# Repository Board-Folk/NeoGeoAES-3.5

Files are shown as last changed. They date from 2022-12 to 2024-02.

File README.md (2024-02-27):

# NeoGeoAES-3.5 PCB Reproduction

This repository contains a recreation of the main board PCB for NeoGeo AES
consoles. This recreation is based on the available schematics for the
NeoGeo AES and reverse engineering using scanned images of the original
board's copper layers, so should be a reasonably accurate reproduction.

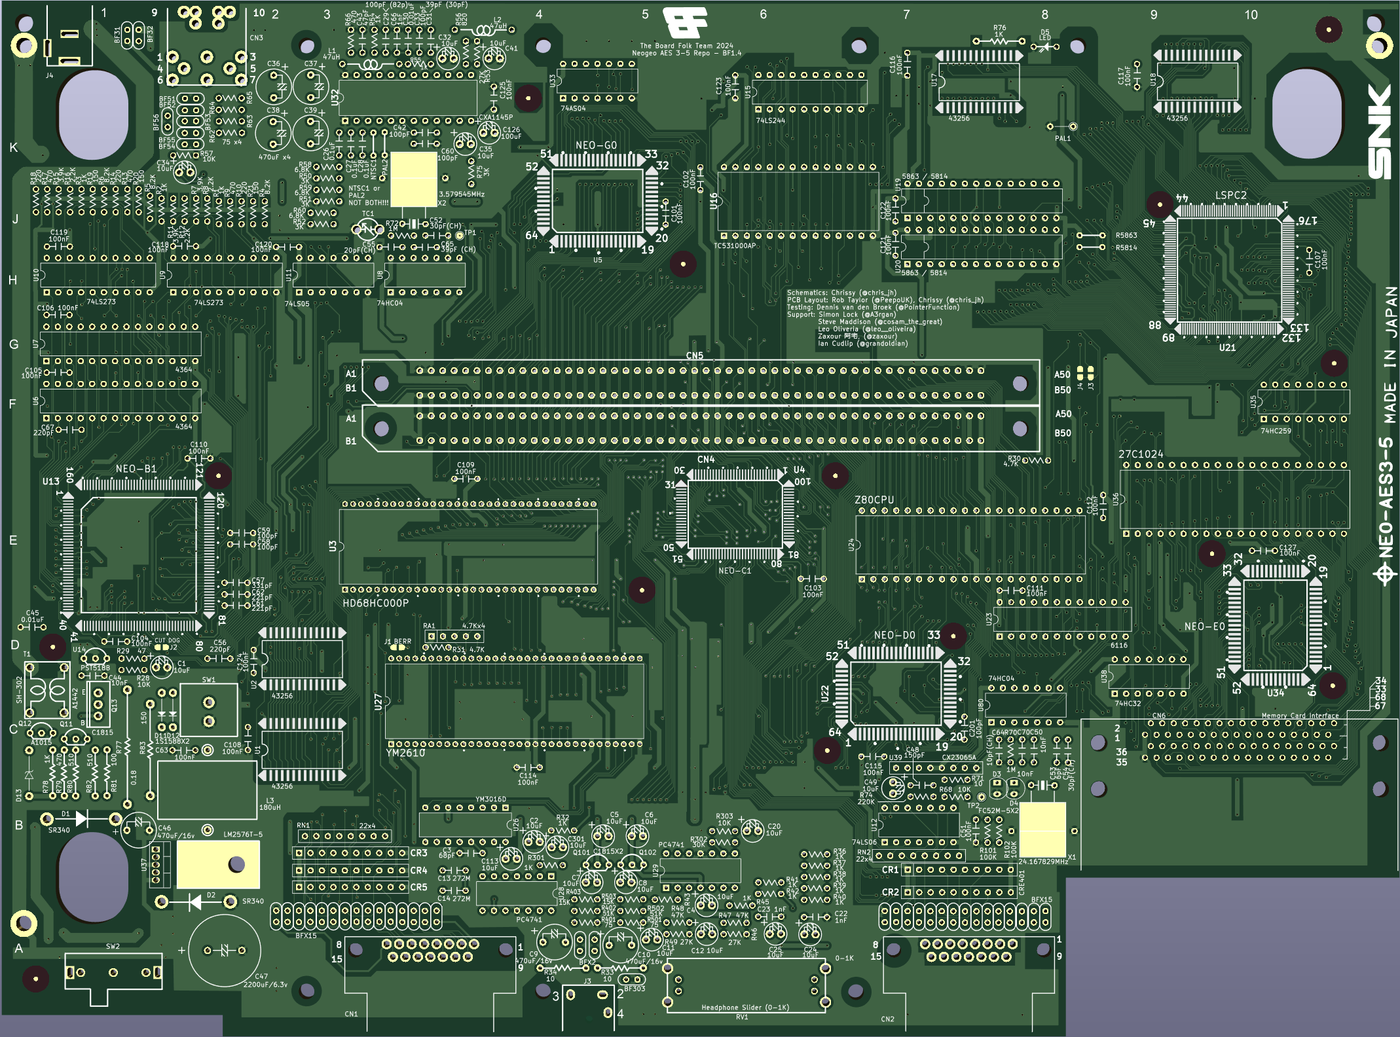
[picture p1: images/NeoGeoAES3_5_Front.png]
PCB


### Revisions

| Revision | Tested | Comments |
|:---:|:---:| --- |
| 1.1 | Working | Prototype |
| 1.2 | Not Tested | Added some missing silk screen |
| 1.3 | Tested | Moved some components on far right by 1mm to be in alignment |
| 1.4 | Tested (not by me) | Tweaks to BOM, updated Silkscreen |

### Future Features
 * Replace power section with something better
 * Add RGB ByPass Mod
 * Add Dual Controller component layput for using standard DB15
 * Do a SMD Version

## PCB Production

Minimum track widths, clearances and via sizes are within the standard
offering of modern PCB fabricators. Development was done using JLCPCB and as
such the Gerber files are provided to their specification.

The design is verified to work as a 2-layer PCB.

I have added it to the PCBWay Shared projects here

<a href="https://www.pcbway.com/project/shareproject/NeoGeo_AES_3_5_reproduction_main_PCB_179da741.html">PCB from PCBWay</a>

I recommend getting ENIG, but HASL will work also.

## Bill of Materials

Most parts are marked on the board and it is expected that these will be reused
from a donor board. It is completely possible that your particular board uses
different (but compatible) parts so it's advisable to take photos before starting.
For a complete BOM, consult the KiCad project's BOM folder, there you will find a CSV file or a PDF.

[**PDF BOM**][BOM]

[**Interactive BOM**][IBOM]

There are some components with mouser parts listed in Kicad BOM, *DO NOT USE THESE*. Need to verify they work.

## 9V or 5V

The NeoGeo AES 3-5 could come configured as either 9V or 5V supply input.

My board is 9V which this repository is based on. Due to this I have marked on the schematics/BOM
which parts are not to populated if using 9V or 5V and by default the 5V circuit is N.F (Not Fitted).

C66 was also not populated.

## Jumper / Links

There are various links around the board.

* __NTSC1 / PAL2 - Only one of these should be populated, it would be very very very bad if both are populated
  as one links to GND and the other to VCC.__\
&nbsp;
* PAL1 and PAL2 - if your board is configured for PAL with the appropriate crystal, these should be populated
* NTSC1 - if your board is configured for NTSC, this should be populated with the appropriate crystal.
* 5863 / 5814 - depending on your memory type, one of these should be populated.
* J1 - BERR Signal into the CPU. Default is off.
* J2 - DOGE Signal into the NEO-B1. Default is off.
* J3 / J4 - This is for the EVEN signal to the LSPC2 chip. J3 is already enabled by default.

## Memory

* 5814 - The shorter of the RAM Chips, make sure to populate into socket to the far right and populate the correct
  jumper.
* 5863 - The longer of the RAM Chips, uses the whole socket. Populate the correct jumper.

## Thanks

  * Rob Taylor ([@PeepoUK](https://github.com/PeepoUK)) for doing most of
    the PCB layout.\
&nbsp;
  * Simon "Aergan" Lock ([@Aergan](https://github.com/Aergan)),\
    Cosam (@cosam_the_great),\
    Dennis (@PointerFunction),\
    Leo Oliveria (@leo__oliveira),\
    Zaxour 阿宅, (@zaxour),\
    Ian Cudlip (@grandoldian)\
    for their insights, support and testing of the prototype boards.\
&nbsp;
  * The rest of the Board Folk Team for their support and general
    coolness.\
&nbsp;
  * The [NeoGeo Development Wiki](https://wiki.neogeodev.org/) for making
    the original NeoGeo-2 Schematics available, and the people who maintain
    this site.\
&nbsp;

## Legal

As the product of this project is a replica of a proprietary product, the
the author makes no claim of copyright to the schematics nor PCB layouts and
releases these into the public domain, solely for the purposes of study and
historical preservation.

You are free to produce PCBs based on this project's designs at your own risk
and without limitation, for your own use or for sale and/or repair at a
reasonable price. Attribution is appreciated. The authors are not obliged to
provide support of any kind.

Under no circumstances will the authors be held responsible or liable in any
way for losses, damages or costs resulting from the use of the information
and/or resources of this project.

The resources are provided "as-is" without warranty of any kind, either
expressed or implied, including, but not limited to, the implied warranties
of merchantability and fitness for a particular purpose.

[IBOM]: http://htmlpreview.github.io/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

[BOM]: https://raw.githubusercontent.com/Board-Folk/NeoGeoAES-3.5/main/bom/NeoGeoAES3_5-BOM.pdf

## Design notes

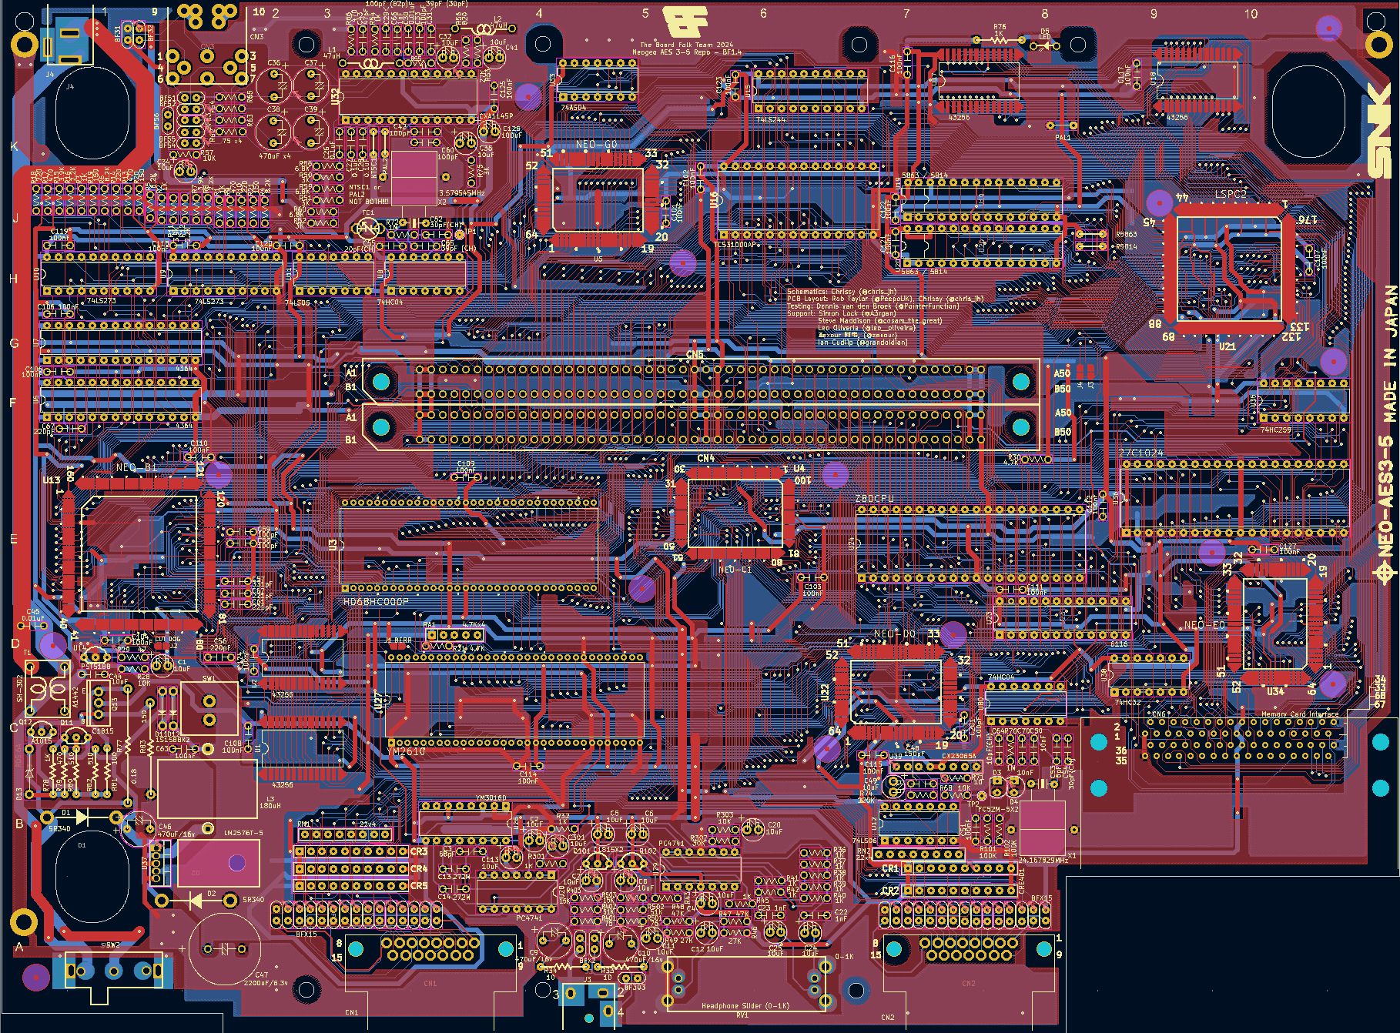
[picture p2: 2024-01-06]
images/NeoGeoAES3_5_PCB.png

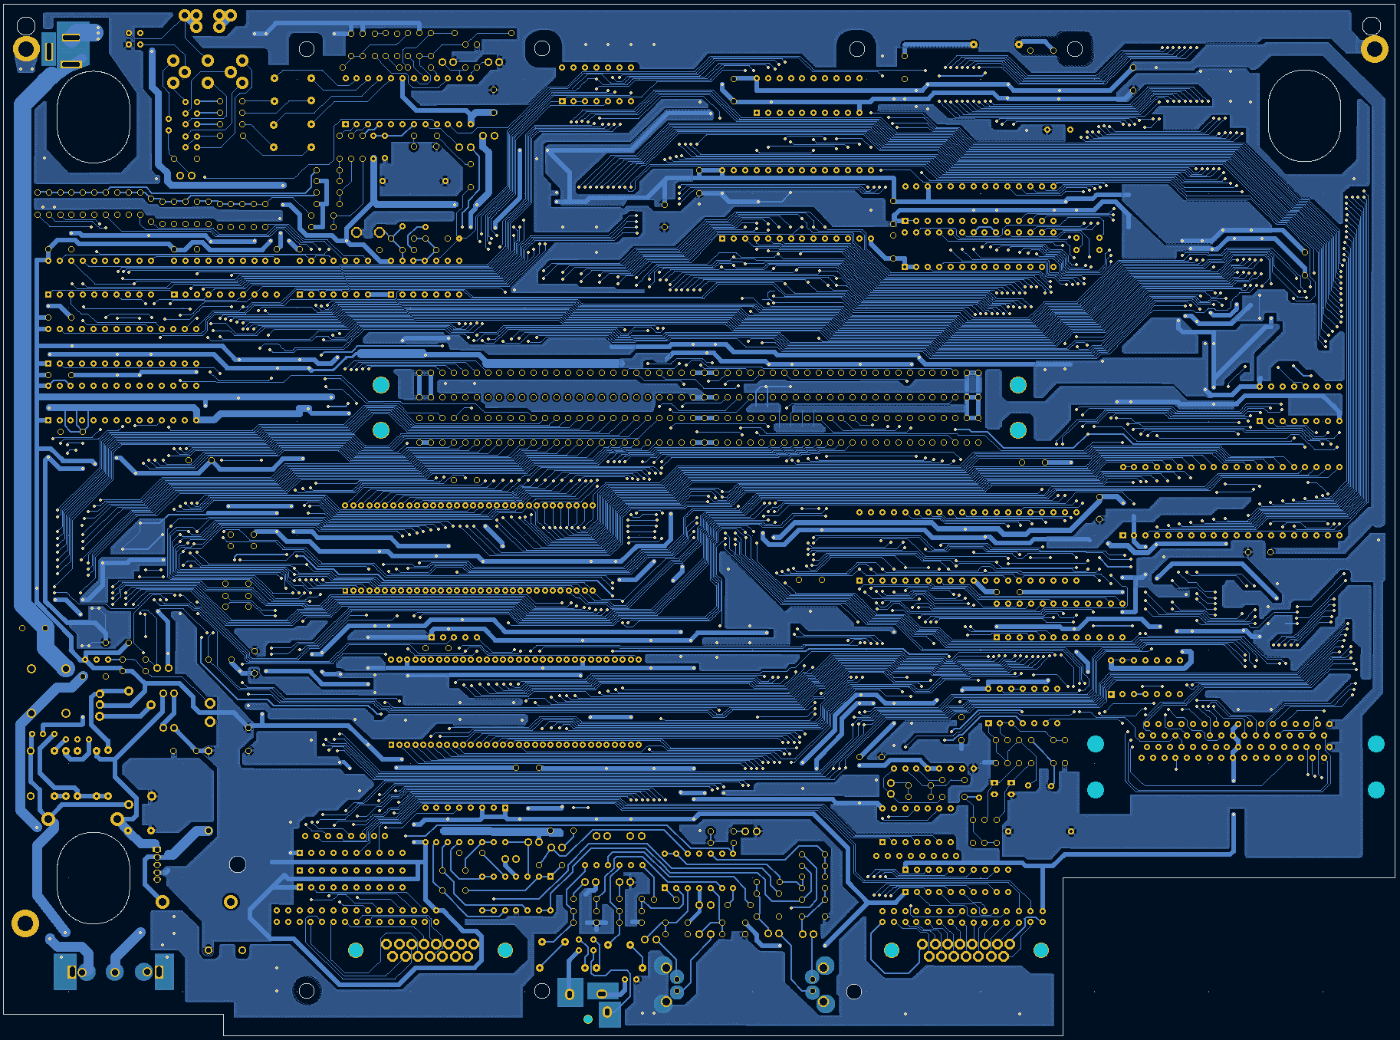
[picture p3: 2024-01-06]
images/NeoGeoAES3_5_PCB_Back.png

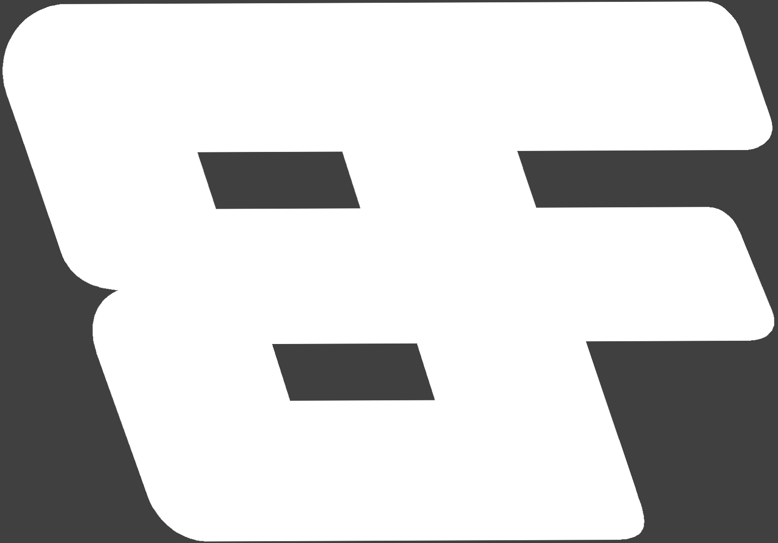
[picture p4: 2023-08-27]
images/BF.png

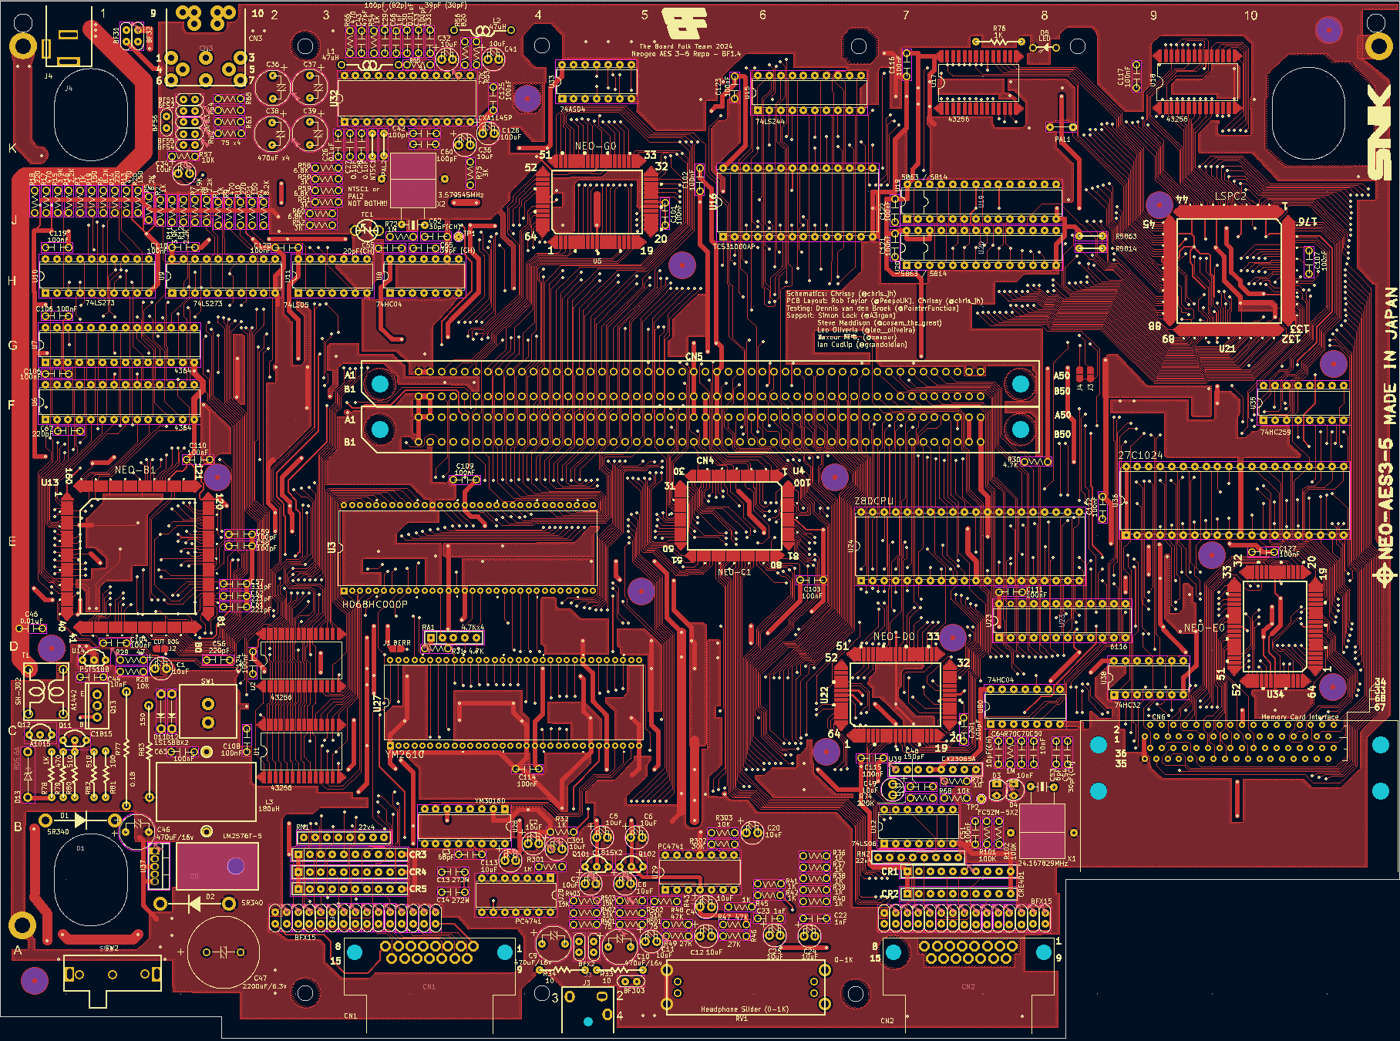
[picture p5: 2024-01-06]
images/NeoGeoAES3_5_PCB_Front.png

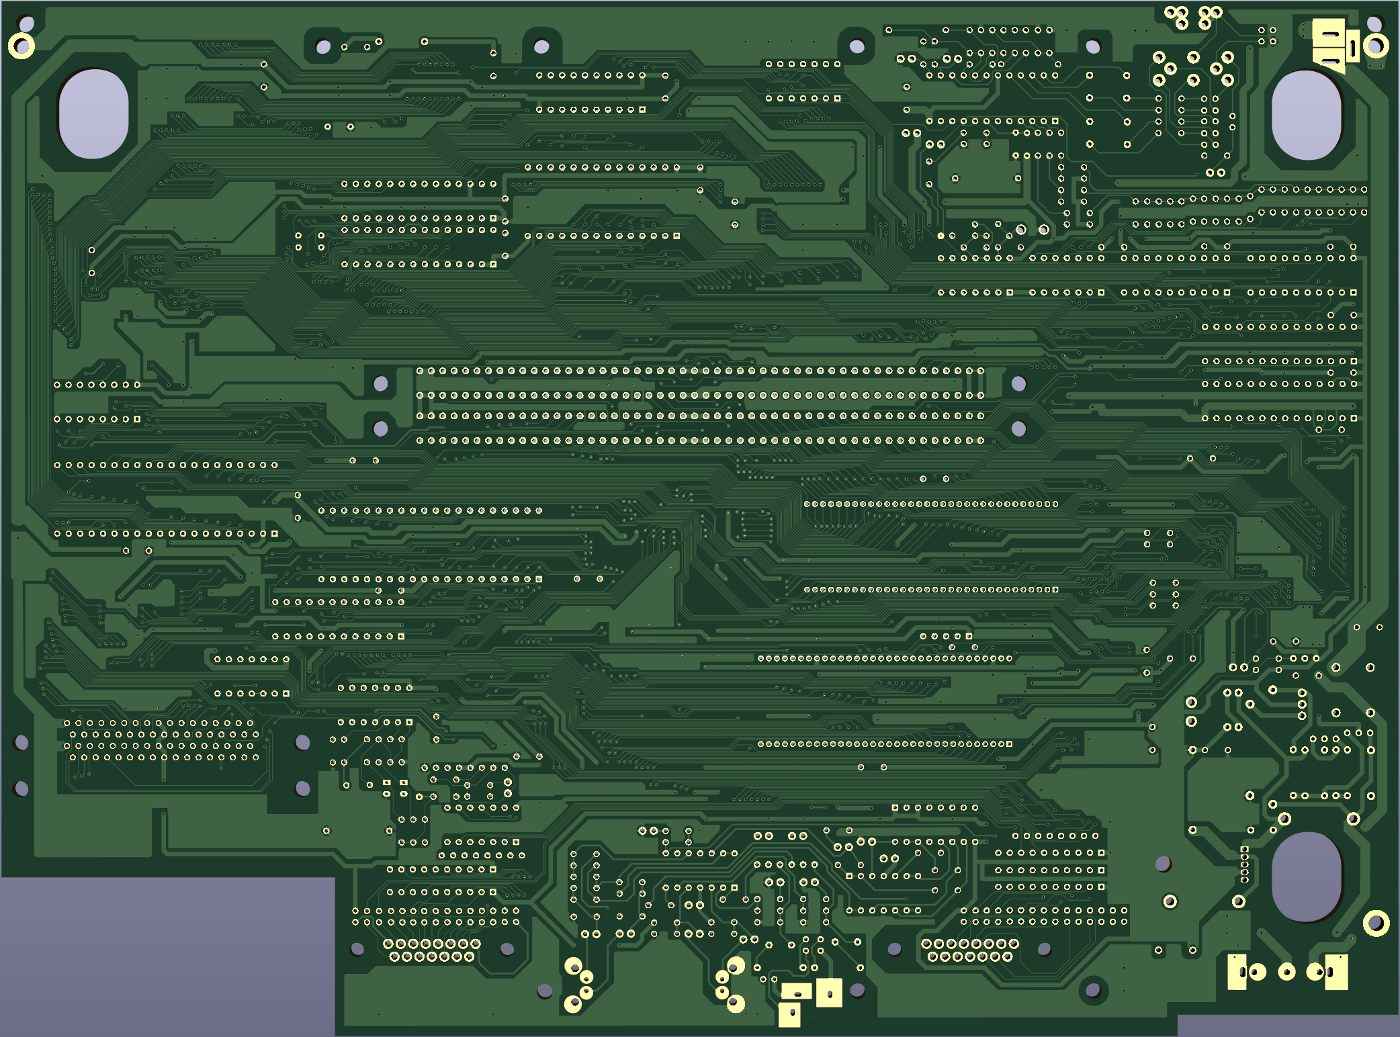
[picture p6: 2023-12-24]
images/NeoGeoAES3_5_Back.png

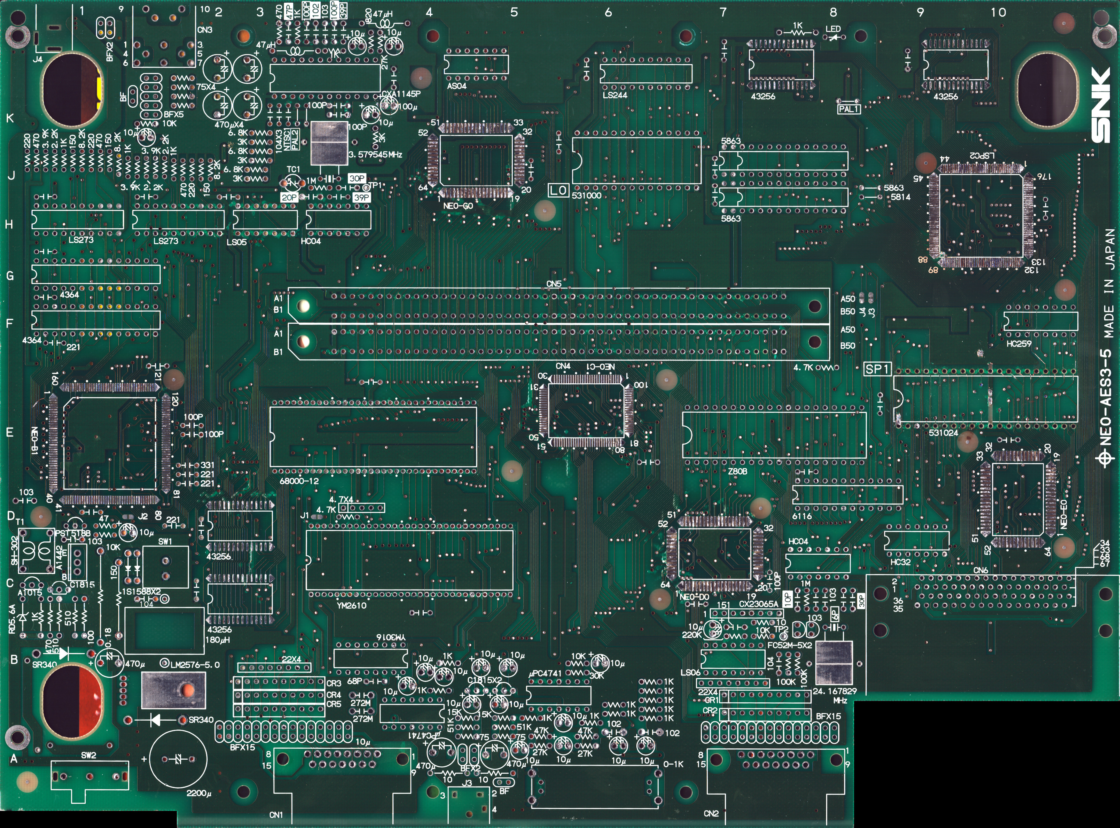
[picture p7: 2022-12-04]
images/neogeo_aes-3-5-front-300dpi_90p.jpg

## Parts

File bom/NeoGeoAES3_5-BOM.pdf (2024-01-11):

### NeoGeoAES3_5-BOM

Qty | Reference | Value | Mouser | Alternative | Comment
41 | BF1-BF32, BF51-BF56, BF301-BF303 | ZBF253D | 80-B-06-R-25
19 | C1, C2, C4-C8, C11, C12, C20, C24, C25, C32, C34, C35, C41, C49, C113, C301 | 10uF | 667-ECA-1CM100I
1 | C3 | 68pF | 810-FG28C0G2A680JNT6
7 | C9, C10, C36-C39, C46 | 470uF/16v | 647-UVR1C471MPD1TA
2 | C13, C14 | 272M | 80-MMK5272K63J01TA18
3 | C22, C23, C66 | 1nF | 810-FG28C0G1H102JNT6 | | -- mixed values --
3 | C26-C28 | 0.1uF | 810-FG26C0G1H104JNT0
1 | C29 | 100pF (82p) | 810-FG28C0G1H101JNT6
2 | C30, C45 | 0.01uF | 810-FG28C0G1H103JNT0
1 | C31 | 39pF (30pF) | 810-FG28C0G1H390JNT6
6 | C33, C42, C58-C60, C201 | 100pF | 810-FG28C0G1H101JNT6
1 | C43 | 47pF | 810-FG28C0G1H470JNT6
3 | C44, C50, C70 | 10nF | 810-FG28C0G1H103JNT0
1 | C47 | 2200uF/6.3v | 667-EEU-FC0J222S
1 | C48 | 150pF | 810-FG28C0G1H151JNT6
27 | C51, C63, C101-C112, C114-C125, C127 | 100nF | 810-FG26C0G1H104JNT0
2 | C52, C54 | 30pF(CH) | 80-C322C300K3G5TA
1 | C53 | 6pF | 810-FG28C0G1H060DNT6
1 | C55 | 20pF(CH) | 80-C317C200J5G
2 | C56, C67 | 220pF | 810-FG28C0G1H221JNT0
1 | C57 | 331pF | 810-FG28C0G1H331JNT6
2 | C61, C62 | 221pF | 810-FG28C0G1H221JNT0
1 | C64 | 10pF(CH) | 810-FG28C0G1H100DNT6
1 | C65 | 39pF (CH) | 810-FG28C0G1H390JNT6
1 | C126 | 100uF | 667-ECA-1CM101I
1 | CN1 | CTRL1 | | | Use Original
1 | CN2 | CTRL2 | | | Use Original
1 | CN3 | DIN-8 | | | Use Original
2 | CN4, CN5 | AXC90020 | 587-395-100-524-204
1 | CN6 | Memory Card Interface | | | Use Original
5 | CR1-CR5 | CRE401 | | https://github.com/mourix/CRE401
2 | D1, D2 | SR340 | 583-SR340-T | | Not Fitted when 5v Circuit
2 | D3, D4 | FC52M-5 | | LV2209 | Use Original
1 | D5 | LED | 604-WP7113ID5V
2 | D11, D12 | 1S1588 | | | Not Fitted when 9v Circuit
1 | D13 | RD5.6A | | | Not Fitted when 9v Circuit
1 | J3 | SMK S-G8043
1 | J4 | POWER JACK | 490-PJ-102B
1 | JP3 | J3
1 | JP4 | J4
1 | L1 | 47uH
1 | L2 | 47uH
1 | L3 | 180uH | | | Not Fitted when 5v Circuit, Use Original
1 | Q11 | C1815 | | | Not Fitted when 9v Circuit
1 | Q12 | A1015 | | | Not Fitted when 9v Circuit
1 | Q13 | A1442 | | | Not Fitted when 9v Circuit
2 | Q101, Q102 | 2SC1815 | 610-2SC1815
16 | R1-R3, R32, R36-R43, R45, R54, R55, R301 | 1K | 594-5063JD1K000FT
3 | R4-R6 | 8.2K | 594-5063JD8K200FT
3 | R7, R11, R15 | 3.9K | 594-5063JD3K900F
3 | R8, R12, R16 | 2.2K | 594-5063JD2K200FT
4 | R9, R13, R17, R66 | 470 | 594-5063JD470R0FT
3 | R10, R14, R18 | 220 | 594-5063JD220R0F
3 | R19-R21 | 150 | 594-5063JD150R0FT
4 | R28, R57, R68, R303 | 10K | 594-5063JD10K1%TR
1 | R29 | 47 | 594-5063JD47R00F
2 | R30, R31 | 4.7K | 594-5063JD4K700F5
2 | R33, R34 | 10 | 594-5063JD10R00FT
3 | R46, R49, R53 | 27K | 594-5063JD27K00FT
2 | R47, R48 | 47K | 594-5063JD47K00FT
4 | R50-R52, R75 | 3K | 594-5063JD3K000F
1 | R56 | 820 | 594-5063JD820R0FT
3 | R58-R60 | 6.8K | 594-5063JD6K810FT
6 | R62-R65, R401, R501 | 75 | 594-5063JD75R00FT
2 | R70, R72 | 1M | 594-5063JD1M000FT
1 | R71 | 10 | 594-5063JD10R00FT
1 | R74 | 220K | 594-5063JD220K0F
2 | R76, R78 | 1K | 594-5063JD1K000FT | | -- mixed values --
1 | R77 | 0.18 | | | Not Fitted when 9v Circuit
2 | R79, R82 | 510 | | | Not Fitted when 9v Circuit
1 | R80 | 470 | | | Not Fitted when 9v Circuit
1 | R81 | 100 | | | Not Fitted when 9v Circuit
1 | R83 | 150 | | | Not Fitted when 9v Circuit
2 | R101, R102 | 100K | 594-5063JD100K0FT

1

1 | R302 | 30K | 594-5063JD30K00F
2 | R402, R502 | 51K | 594-5063JD51K00F
2 | R403, R503 | 15K | 594-5063JD15K00F5
1 | RA1 | 4.7Kx4 | 652-4605X-1LF-4.7K
2 | RN1, RN2 | 22x4 | 652-4608X-2LF-22
1 | RV1 | Headphone Slider (0-1K) | | Alps Alpine RS20H12AC002 | Use Original
1 | SW1 | RESET SWITCH | | https://a.aliexpress.com/_EwBCIut | Use Original
1 | SW2 | POWER SWITCH | | | Use Original
1 | T1 | SH-302 | 80-SH-302
1 | TC1 | 0-50p | | Mouser 594-2222-808-23279 ?? 4pF-27pF or Digikey 2447-GKG50015-ND ? Use Original
4 | U1, U2, U17, U18 | 43256 | 870-62C256AL-25ULI | JEDEC 62256 (32k x 8) SRAM | Use Original
1 | U3 | HD68HC000P | | | Use Original
1 | U4 | NEO-C1 | | | Use Original
1 | U5 | NEO-G0 | | | Use Original
2 | U6, U7 | 4364 | 913-AS7C164A-15PCN | JEDEC 6264 (8k x 8) SRAM | Use Original
2 | U8, U80 | 74HC04 | 595-SN74HC04N
2 | U9, U10 | 74LS273 | 595-SN74LS273N
1 | U11 | 74LS05 | 595-SN74LS05N
1 | U12 | 74LS06 | 595-SN74LS06N
1 | U13 | NEO-B1 | | | Use Original
1 | U14 | PST518B | 579-MCP120-450GI/TO | | Use Original
1 | U15 | 74LS244 | 595-SN74LS244N
1 | U16 | TC531000AP | | | Use Original
2 | U19, U20 | 5863 / 5814 | | JEDEC 6116 (2k x 8) SRAM 35ns | Use Original
1 | U21 | LSPC2 | | | Use Original
1 | U22 | NEO-D0 | | | Use Original
1 | U23 | 6116 | | JEDEC 6116 (2k x 8) SRAM 35ns | Use Original
1 | U24 | Z80CPU | | | Use Original
1 | U26 | YM3016D | | | Use Original
1 | U27 | YM2610 | | | Use Original
2 | U28, U29 | PC4741 | 968-UPC4741G2-E1-A | | Use Original
1 | U32 | CXA1145P | | CXA1645 or CXA2075 needs adapterUse Original
1 | U33 | 74AS04 | 595-SN74AS04N
1 | U34 | NEO-E0 | | | Use Original
1 | U35 | 74HC259 | 595-SN74HC259N
1 | U36 | 27C1024 | | | Use Original
1 | U37 | LM2576T-5 | 926-LM2576T-5.0/NOPB | https://www.aliexpress.com/item/1005004285746293.html Not Fitted when 5v Circuit
1 | U38 | 74HC32 | 595-SN74HC32N
1 | U39 | CX23065A | Use Original or could be removed along with associated resistors and caps, D3 D4 removed and bridged and 24Mhz used
1 | X1 | 24.167829MHz | Use Original or 24 Mhz and CX23065A removed
1 | X2 | 3.579545MHz | 815-AB-3.579545-B2

2

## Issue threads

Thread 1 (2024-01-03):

Memory Card Slot Mouser Part does not fit

chris-jh, 2024-01-03:
The Memory Card PCMCIA selected in Mouser Part does not fit. Don't use.

jwestfall69, 2024-01-07:
Hi,

The NeoGeo uses a non-standard PCMCIA connector for the pins connecting to the PCB.  Pin 1 starts on the 2nd row while all PCMCIA connectors out there have pin 1 on the first row.  I've never been able to find a replacement other then sourcing from parts boards. You should consider just adjusting the PCB layout to work with a normal PCMCIA connector.

chris-jh, 2024-01-07:
Aye, i have removed the part from my bom and reference, which is now version BF1.4

I am planing on doing a remaster of the board with more modern parts in places.
PSU,
Video,
Memory Slot,
Headphone Socket and Slider,
Switch,
SRAM

Maybe even SMD for resistors and caps.

philjay78, 2024-01-12:
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
Hi, i'm Massimo. I think a similar thing could be a good solution for fix the problem for me that i have a 1.3 board.

philjay78, 2024-01-12:
[adapter.zip](https://github.com/Board-Folk/NeoGeoAES-3.5/files/13918917/adapter.zip)
could it work like this? It's my first attempt with kicad 👍

philjay78, 2024-01-13:
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
With my very very poor knowledge of kicad, i've made this adapter. I've tried the measure and maybe you have to cut the guide of the new pcmcia adapter (5535653-1), obviously you need to solder the adapter and cut the pins straight at max you can do.

chris-jh, 2024-01-14:
Looks good ? going for thin pcb ?

spokito95, 2025-01-26:
Hi, Having bent the connector to read the memory card of the neo geo, I looked for a substitute, but I found nothing interesting.
But this topic gave me the idea of making this small adapter on the surface, because the pins to be soldered through the pcb could be troublesome. So that's the idea I'm sharing with you.

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

spokito95, 2025-01-26:
Hello all,

I finally finished the pcb, taking care to check the measurements for optimum fit.
As philjay78 mentioned on his pcb, which I based on (thanks to him), I'll also have to cut off the parts of the PCMCIA adapter that stick out 12mm to keep the right dimensions.
I have made the Gerber file available. If anyone can find a cheap 5535651-6 connector, I'd be interested as it's a bit expensive.
I ordered 5 copies of pcb on JLCPCB and pre-ordered the connector: 5535651-6 because it was out of stock on LCSC electronics. I'll wait and see.
I will keep you informed as soon as I receive them.

[Gerber_adapter_PCMCIA_Neo_Geo_AES_2025-01-26.zip](https://github.com/user-attachments/files/18551862/Gerber_adapter_PCMCIA_Neo_Geo_AES_2025-01-26.zip)

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

chris-jh, 2025-01-28:
Looking good, still not got around to making a remix board, one day 😂

spokito95, 2025-01-30:
Hello Chris-jh,

First of all, congratulations on the reproduction work, it's truly amazing! I've finalized two Neo Geo AES 3.5 reproduction PCBs, and both work perfectly! However, I had to install components D3, D4, and U39 as well as the original quartz, in addition to the 100k resistors and the 100nF capacitor, because the 24.000 MHz quartz crystal, like the one in the photo, did not work. Which components should I remove exactly to avoid using D3, D4, and U39 as well as the original quartz? What is the exact procedure to make it work?

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

chris-jh, 2025-02-01:
Trying to remember, i found this photo on my phone. But basically it is the MVS circuit. I don't think i used 33pf, i think it was either 30pF or 20pF at C70.

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

spokito95, 2025-02-01:
Capacitor C50 10nf must be replaced also by 30pf or not ? Because I have a problem on screen with glitch or unsynchronised, I don't know.

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

spokito95, 2025-02-01:
It's ok now I had to replace the C50 (10 nF) and C70 (10 nF) capacitors with two 20pF capacitors, thank you very much for your help :)

chris-jh, 2025-02-01:
Yes sorry, C50 and C70. i got my board out and i have 20pF here.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

chris-jh, 2025-02-01:
These are the components i have fitted in that area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

spokito95, 2025-02-01:
No problem it's cool :), I'll summarise what needs to be done in pdf below.

[Remove and reolace components.pdf](https://github.com/user-attachments/files/18630258/Remove.and.reolace.components.pdf)

spokito95, 2025-03-15:
Hi everyone,

Just a quick update on my Neo Geo AES motherboard reproduction project: my latest board is finally finished and fully functional! Super happy with how it turned out! 🎉

I especially want to give a huge thanks to Illusionrip, who spontaneously and generously offered to send me a 68000 to help me out. Without him, I wouldn’t have been able to finish this board so quickly, so a massive thank you for your precious help! 🙏 :amen:

Right after that, I also assembled my little PCMCIA adapter PCB for the memory card reader, and good news — it works perfectly.
To connect the two PCBs, I chose to use tulip pin headers, and honestly, I don’t regret it at all.

They make soldering much easier (solder flows nicely between the contacts),
And most importantly, they allow for easy continuity testing if you ever have any doubts or issues — super handy to make sure everything is good before finalizing the build.
Just a quick note for anyone thinking about doing the same: the PCMCIA adapter PCB must be properly secured with two screws and nuts (see pictures), to make sure everything stays firmly in place and to avoid putting stress on the solder joints, which could eventually crack or break. This is really important for long-term reliability.

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

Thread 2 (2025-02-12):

Latest board (1.4) does not pass JLCPCB capabilities

joncco, 2025-02-12:
I sent the latest gerber (1.4) to JLCPCB for manufacturing.  It came back with:
the mininum trace spacing in your file are smaller than our mininum requirement of 0.1mm for 2 layer PCB ,please check and modify .

After opening the files in kicad, I found a few traces that have spacing of 0.081. These are around the cart slot, plus a few traces around the memory card area.

I have downloaded and reworked it a bit to allow it to pass DRC using kicad 8.x.  I can submit the changes I made, but not really sure how to proceed.

DoctorDan1986, 2025-04-03:
I, too, was unable to send this through JLCPCB.  Had to have mine done at PCBWAY for about 4x the cost.

bsulyan, 2025-05-05:
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

Same thing today

DoctorDan1986, 2025-05-05:
It seems to change - I've had it pass and I've had it fail a few times.

@bsulyan - I have several free boards.  If you are okay with black soldermask and ENIG, I'll happily sell you one for a reasonable price.

bsulyan, 2025-05-06:
> It seems to change - I've had it pass and I've had it fail a few times.
>
> [@bsulyan](https://github.com/bsulyan) - I have several free boards. If you are okay with black soldermask and ENIG, I'll happily sell you one for a reasonable price.

Thanks for the offer, but I have several NeoGeos that need a new PCB, I would like to take 5 at once. I'll wait for a response from
@joncco

DoctorDan1986, 2025-05-06:
Oh wow.  The funny thing is, I ordered 5 and got 7.  I've used one, and added the video RAM to another, so I actually do have 5 boards.  The offer is open should you care to take it, and no offense taken should you not.

joncco, 2025-05-06:
Sorry for the late reply.  I will look for my files and do a pull request.  Should happen in the next 2-3 days.

bsulyan, 2025-05-06:
> Oh wow. The funny thing is, I ordered 5 and got 7. I've used one, and added the video RAM to another, so I actually do have 5 boards available. The offer is open should you care to take it, and no offense taken should you not.

Can you email me at bastien.sulyan at gmail.com ?

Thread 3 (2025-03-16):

Power circuit missing details for A1015 and C1815

DoctorDan1986, 2025-03-16:
The interactive BOM does not even allow these components to be selected; are the two items near the A1142 left unpopulated?  Are they reused from the original?  Two C1815s are used near the headphone jack; why are these excluded from the build list?

chris-jh, 2025-03-16:
As the readme section on "9V or 5V" tells you this board build is based on the 9v version.

You need to look at the schematics, the interactive bom is used as a component location guide only and anything that is not selectable is N.F (Not Fitted) and will not be used on the iBom. look at the PDF or CSV file.

I don't understand what you mean about the two C1815s ? they are Q101 and Q102 they are not excluded from the build list.

chris-jh, 2025-03-17:
As i said this is based on the 9v version. If you want the 5v iBom, you will have to adjust the KiCad yourself and produce it.

Closed 2025-03-16.

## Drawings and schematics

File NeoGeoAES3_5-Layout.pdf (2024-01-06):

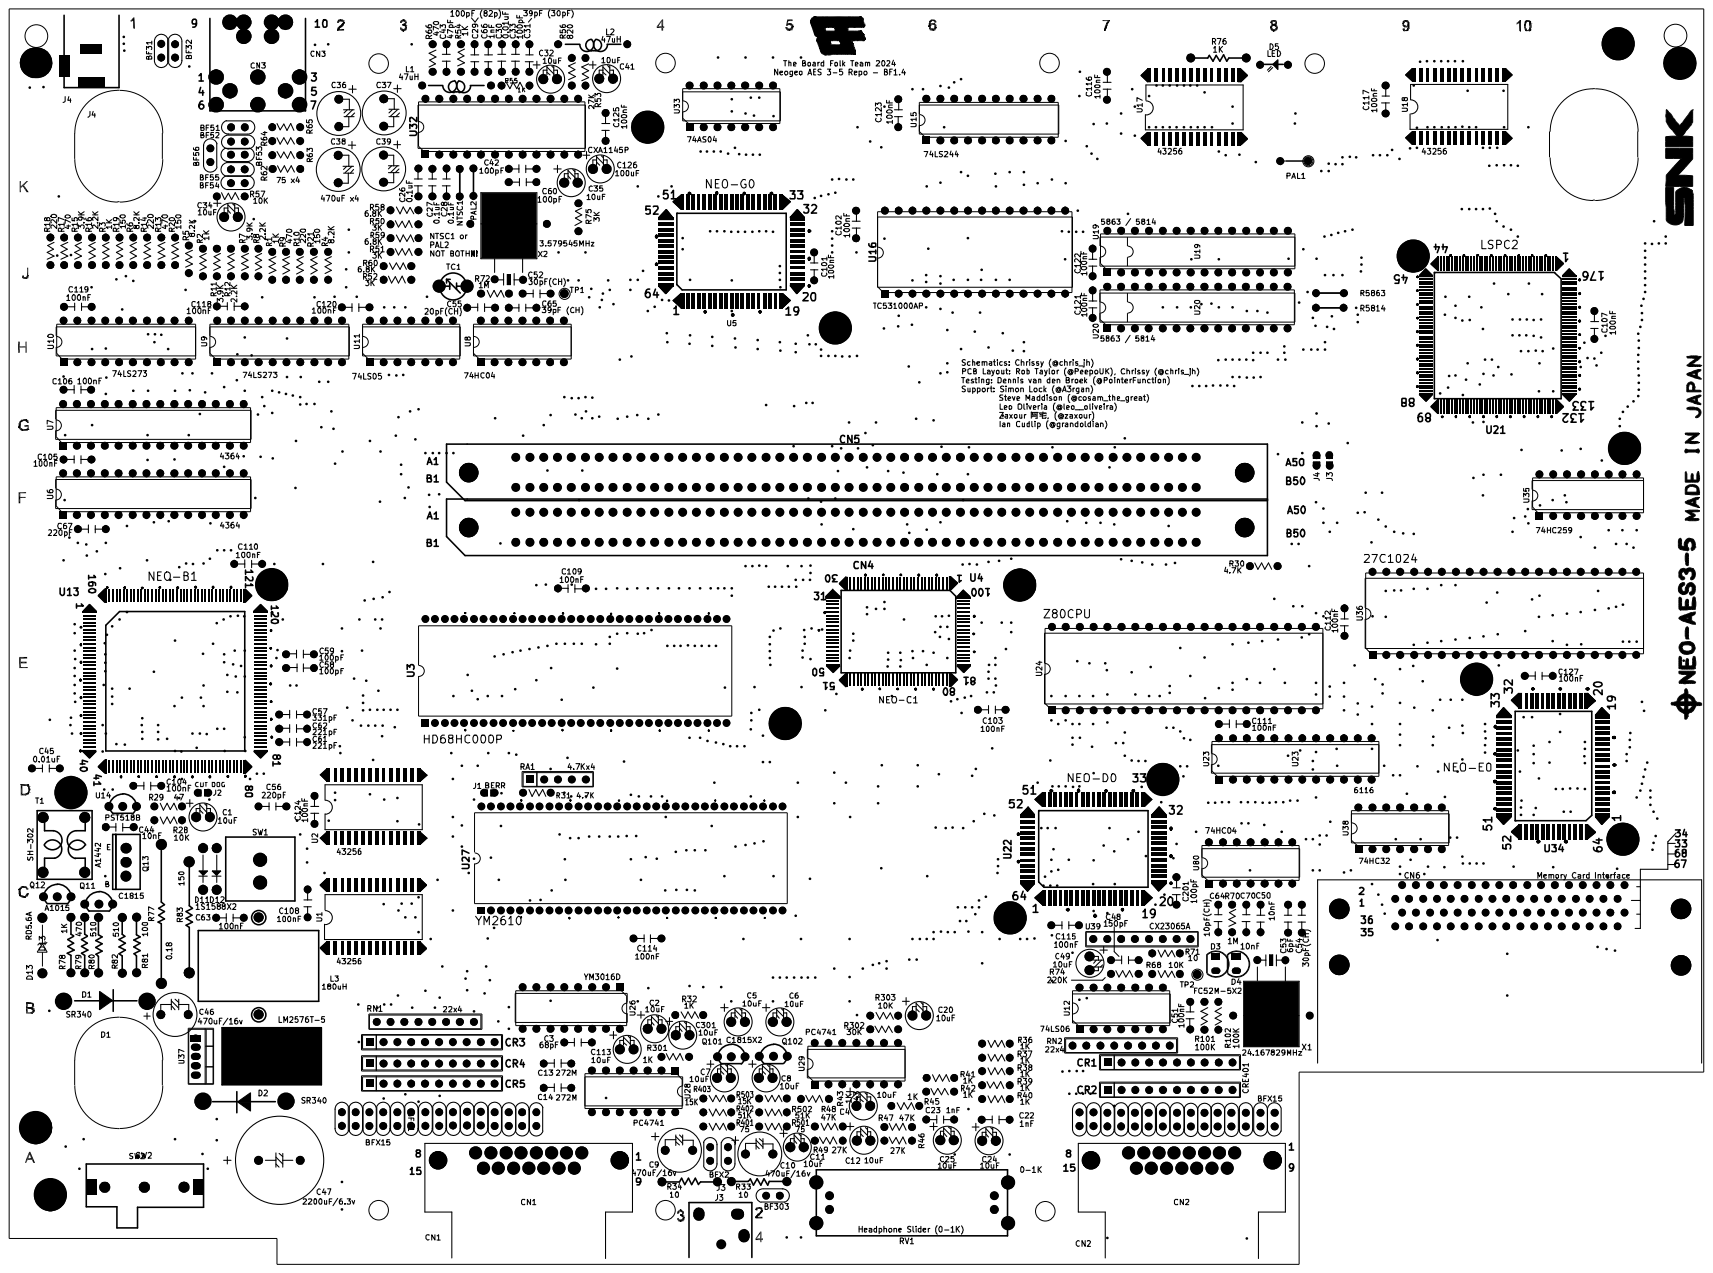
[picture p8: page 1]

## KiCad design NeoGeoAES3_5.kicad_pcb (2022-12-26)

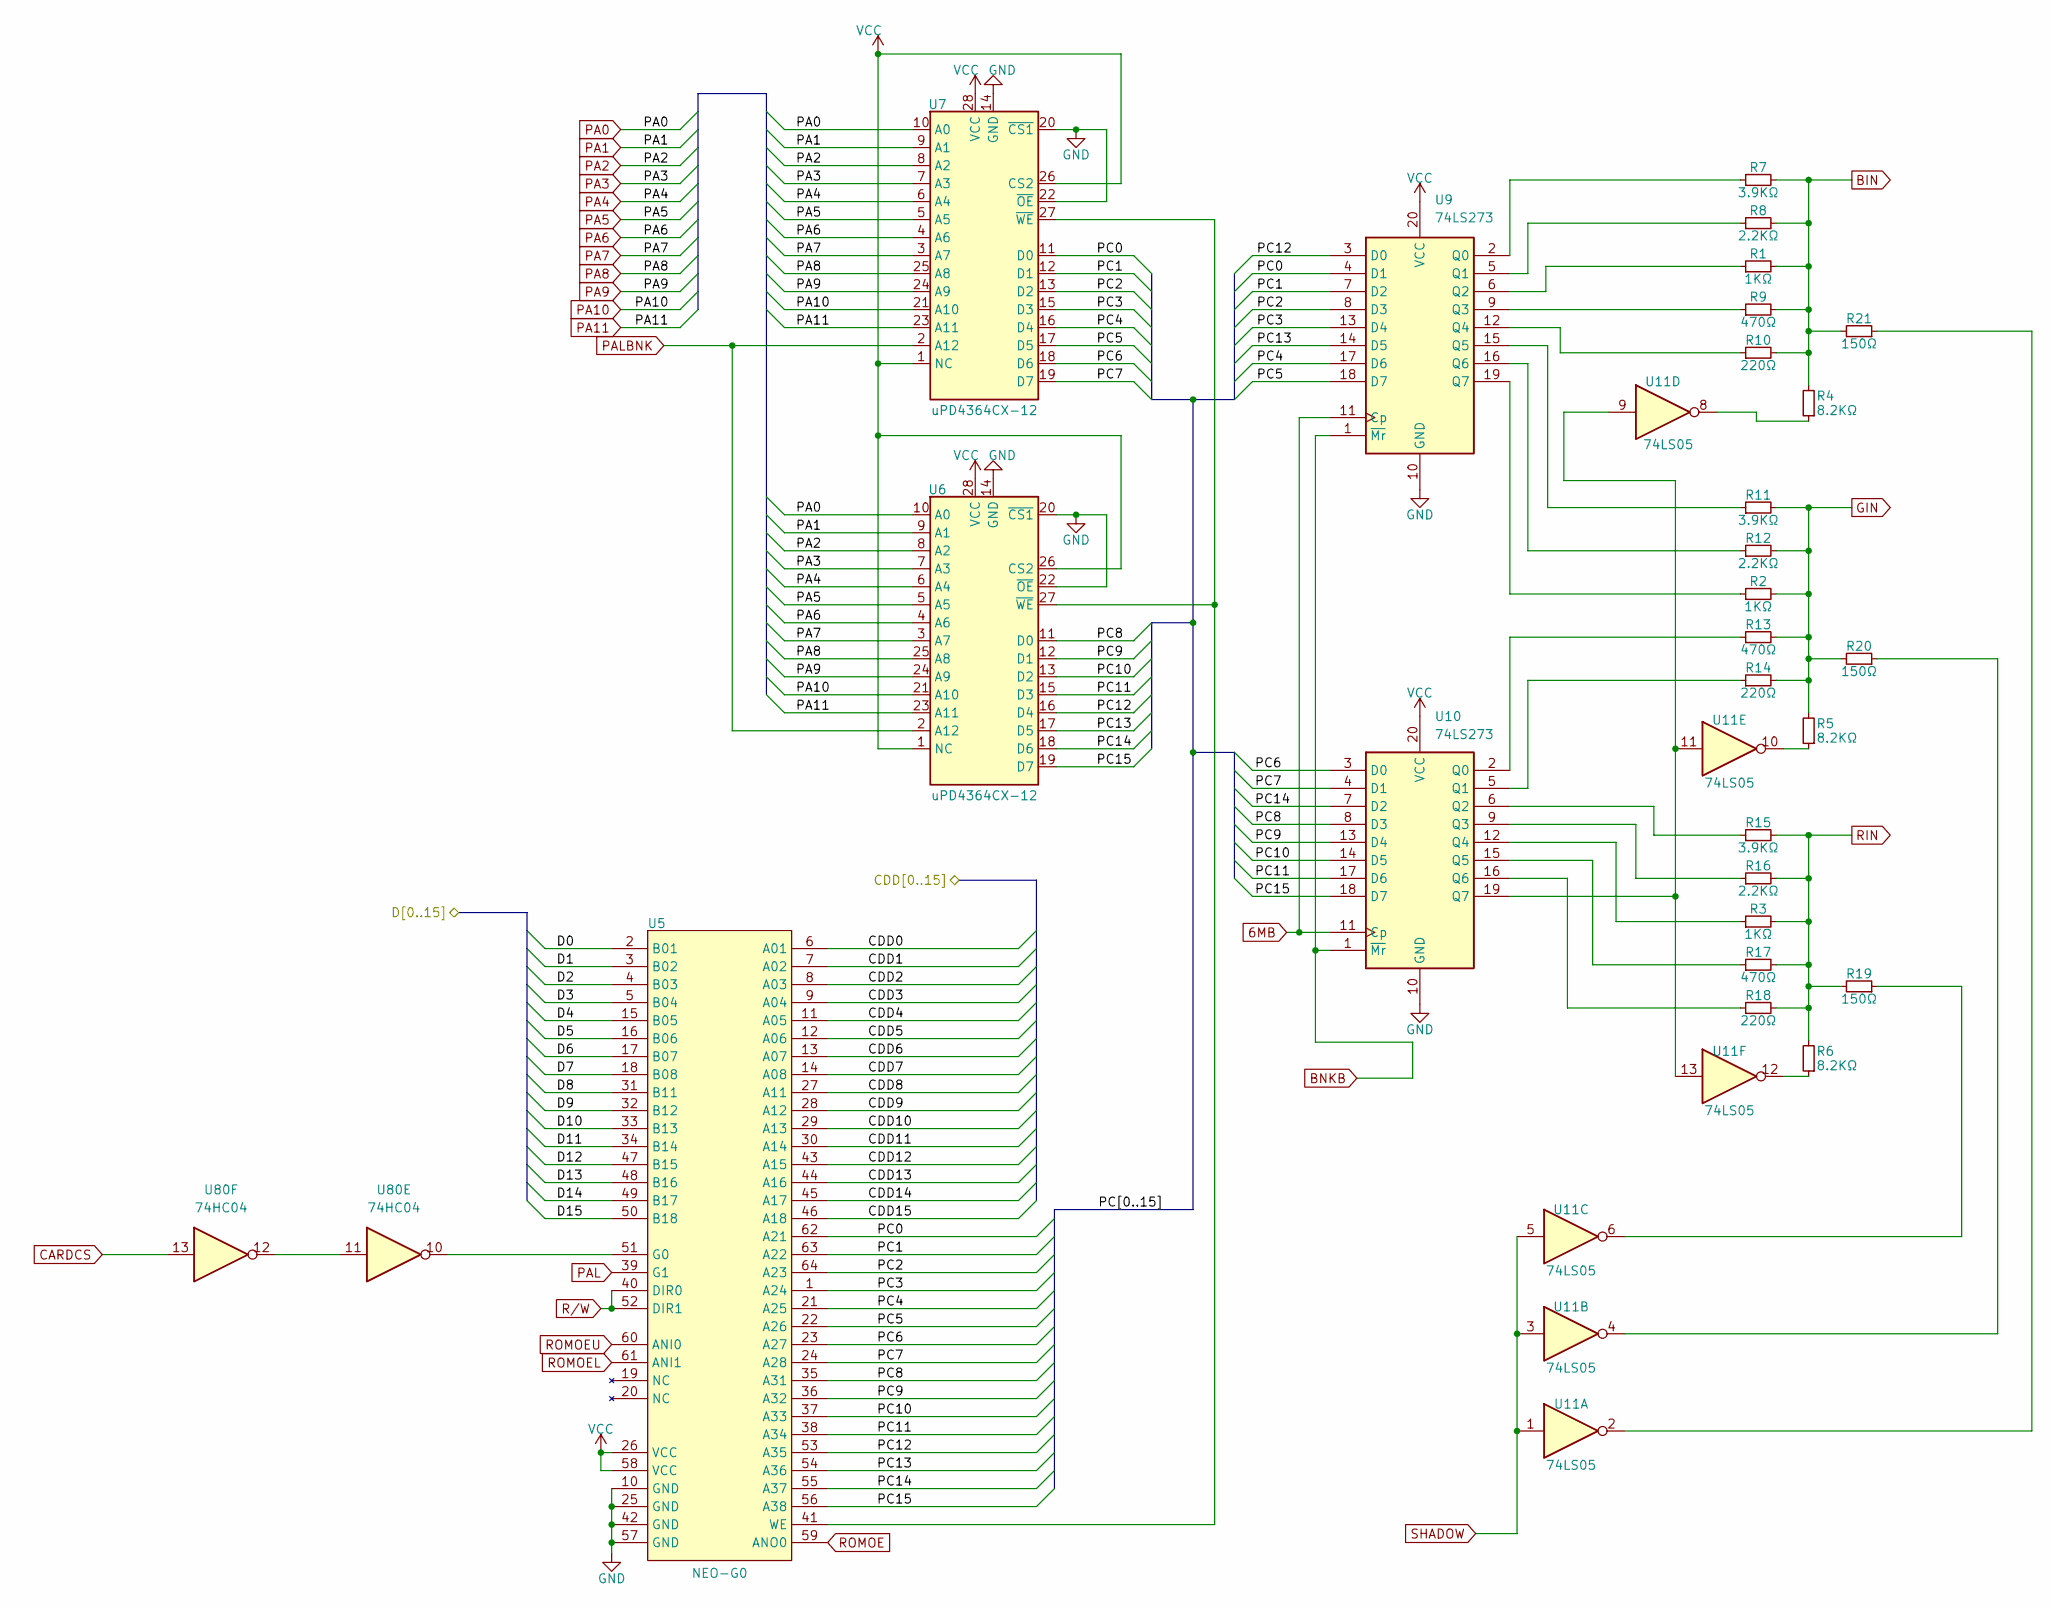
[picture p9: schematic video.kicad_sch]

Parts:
R1, R2, R3: 1KΩ; Resistor1-5mm
R4, R5, R6: 8.2KΩ; Resistor1-5mm
R7, R11, R15: 3.9KΩ; Resistor1-5mm
R8, R12, R16: 2.2KΩ; Resistor1-5mm
R9, R13, R17: 470Ω; Resistor1-5mm
R10, R14, R18: 220Ω; Resistor1-5mm
R19, R20, R21: 150Ω; Resistor1-5mm
U5: NEO-G0
U6, U7: uPD4364CX-12; DIP-28_W7.62mm
U9, U10: 74LS273; DIP-20_W7.62mm
U11: 74LS05; DIP-14_W7.62mm
U80: 74HC04; DIP-14_W7.62mm

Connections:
6MB: U9.11 (Cp), U10.11 (Cp); also elsewhere on the board
/CARD INTERFACE/CDD0: U5.6 (A01); also elsewhere on the board
/CARD INTERFACE/CDD1: U5.7 (A02); also elsewhere on the board
/CARD INTERFACE/CDD2: U5.8 (A03); also elsewhere on the board
/CARD INTERFACE/CDD3: U5.9 (A04); also elsewhere on the board
/CARD INTERFACE/CDD4: U5.11 (A05); also elsewhere on the board
/CARD INTERFACE/CDD5: U5.12 (A06); also elsewhere on the board
/CARD INTERFACE/CDD6: U5.13 (A07); also elsewhere on the board
/CARD INTERFACE/CDD7: U5.14 (A08); also elsewhere on the board
/CARD INTERFACE/CDD8: U5.27 (A11); also elsewhere on the board
/CARD INTERFACE/CDD9: U5.28 (A12); also elsewhere on the board
/CARD INTERFACE/CDD10: U5.29 (A13); also elsewhere on the board
/CARD INTERFACE/CDD11: U5.30 (A14); also elsewhere on the board
/CARD INTERFACE/CDD12: U5.43 (A15); also elsewhere on the board
/CARD INTERFACE/CDD13: U5.44 (A16); also elsewhere on the board
/CARD INTERFACE/CDD14: U5.45 (A17); also elsewhere on the board
/CARD INTERFACE/CDD15: U5.46 (A18); also elsewhere on the board
/CPU/D0: U5.2 (B01); also elsewhere on the board
/CPU/D1: U5.3 (B02); also elsewhere on the board
/CPU/D2: U5.4 (B03); also elsewhere on the board
/CPU/D3: U5.5 (B04); also elsewhere on the board
/CPU/D4: U5.15 (B05); also elsewhere on the board
/CPU/D5: U5.16 (B06); also elsewhere on the board
/CPU/D6: U5.17 (B07); also elsewhere on the board
/CPU/D7: U5.18 (B08); also elsewhere on the board
/CPU/D8: U5.31 (B11); also elsewhere on the board
/CPU/D11: U5.34 (B14); also elsewhere on the board
/CPU/D12: U5.47 (B15); also elsewhere on the board
/CPU/D13: U5.48 (B16); also elsewhere on the board
/CPU/D14: U5.49 (B17); also elsewhere on the board
/CPU/D15: U5.50 (B18); also elsewhere on the board
/VIDEO/PC0: U5.62 (A21), U7.11 (D0), U9.4 (D1)
/VIDEO/PC1: U5.63 (A22), U7.12 (D1), U9.7 (D2)
/VIDEO/PC2: U5.64 (A23), U7.13 (D2), U9.8 (D3)
/VIDEO/PC3: U5.1 (A24), U7.15 (D3), U9.13 (D4)
/VIDEO/PC4: U5.21 (A25), U7.16 (D4), U9.17 (D6)
/VIDEO/PC5: U5.22 (A26), U7.17 (D5), U9.18 (D7)
/VIDEO/PC6: U5.23 (A27), U7.18 (D6), U10.3 (D0)
/VIDEO/PC7: U5.24 (A28), U7.19 (D7), U10.4 (D1)
/VIDEO/PC8: U5.35 (A31), U6.11 (D0), U10.8 (D3)
/VIDEO/PC9: U5.36 (A32), U6.12 (D1), U10.13 (D4)
/VIDEO/PC10: U5.37 (A33), U6.13 (D2), U10.14 (D5)
/VIDEO/PC11: U5.38 (A34), U6.15 (D3), U10.17 (D6)
/VIDEO/PC12: U5.53 (A35), U6.16 (D4), U9.3 (D0)
/VIDEO/PC13: U5.54 (A36), U6.17 (D5), U9.14 (D5)
/VIDEO/PC14: U5.55 (A37), U6.18 (D6), U10.7 (D2)
/VIDEO/PC15: U5.56 (A38), U6.19 (D7), U10.18 (D7)
BIN: R1.2, R4.2, R7.2, R8.2, R9.2, R10.2, R21.2; also elsewhere on the board
BNKB: U9.1 (~Mr), U10.1 (~Mr); also elsewhere on the board
CARDCS: U80.13; also elsewhere on the board
GIN: R2.2, R5.2, R11.2, R12.2, R13.2, R14.2, R20.2; also elsewhere on the board
unnamed: R4.1, U11.8
unnamed: R5.1, U11.10
unnamed: R6.1, U11.12
unnamed: R19.1, U11.6
unnamed: R20.1, U11.4
unnamed: R21.1, U11.2
unnamed: U5.51 (G0), U80.10
unnamed: U5.41 (WE), U6.27 (~WE), U7.27 (~WE)
unnamed: R7.1, U9.2 (Q0)
unnamed: R8.1, U9.5 (Q1)
unnamed: R1.1, U9.6 (Q2)
unnamed: R9.1, U9.9 (Q3)
unnamed: R10.1, U9.12 (Q4)
unnamed: R11.1, U9.15 (Q5)
unnamed: R12.1, U9.16 (Q6)
unnamed: R2.1, U9.19 (Q7)
unnamed: R13.1, U10.2 (Q0)
unnamed: R14.1, U10.5 (Q1)
unnamed: R15.1, U10.6 (Q2)
unnamed: R16.1, U10.9 (Q3)
unnamed: R3.1, U10.12 (Q4)
unnamed: R17.1, U10.15 (Q5)
unnamed: R18.1, U10.16 (Q6)
unnamed: U10.19 (Q7), U11.9, U11.11, U11.13
unnamed: U80.11, U80.12
PA0: U6.10 (A0), U7.10 (A0); also elsewhere on the board
PA1: U6.9 (A1), U7.9 (A1); also elsewhere on the board
PA2: U6.8 (A2), U7.8 (A2); also elsewhere on the board
PA3: U6.7 (A3), U7.7 (A3); also elsewhere on the board
PA4: U6.6 (A4), U7.6 (A4); also elsewhere on the board
PA5: U6.5 (A5), U7.5 (A5); also elsewhere on the board
PA6: U6.4 (A6), U7.4 (A6); also elsewhere on the board
PA7: U6.3 (A7), U7.3 (A7); also elsewhere on the board
PA8: U6.25 (A8), U7.25 (A8); also elsewhere on the board
PA9: U6.24 (A9), U7.24 (A9); also elsewhere on the board
PA10: U6.21 (A10), U7.21 (A10); also elsewhere on the board
PA11: U6.23 (A11), U7.23 (A11); also elsewhere on the board
PAL: U5.39 (G1); also elsewhere on the board
PALBNK: U6.2 (A12), U7.2 (A12); also elsewhere on the board
RIN: R3.2, R6.2, R15.2, R16.2, R17.2, R18.2, R19.2; also elsewhere on the board
ROMOE: U5.59 (ANO0); also elsewhere on the board
ROMOEL: U5.61 (ANI1); also elsewhere on the board
ROMOEU: U5.60 (ANI0); also elsewhere on the board
R/W: U5.40 (DIR0), U5.52 (DIR1); also elsewhere on the board
SHADOW: U11.1, U11.3, U11.5; also elsewhere on the board
VCC: U5.26 (VCC), U5.58 (VCC), U6.1 (NC), U6.26 (CS2), U6.28 (VCC), U7.1 (NC), U7.26 (CS2), U7.28 (VCC), U9.20 (VCC), U10.20 (VCC); also elsewhere on the board

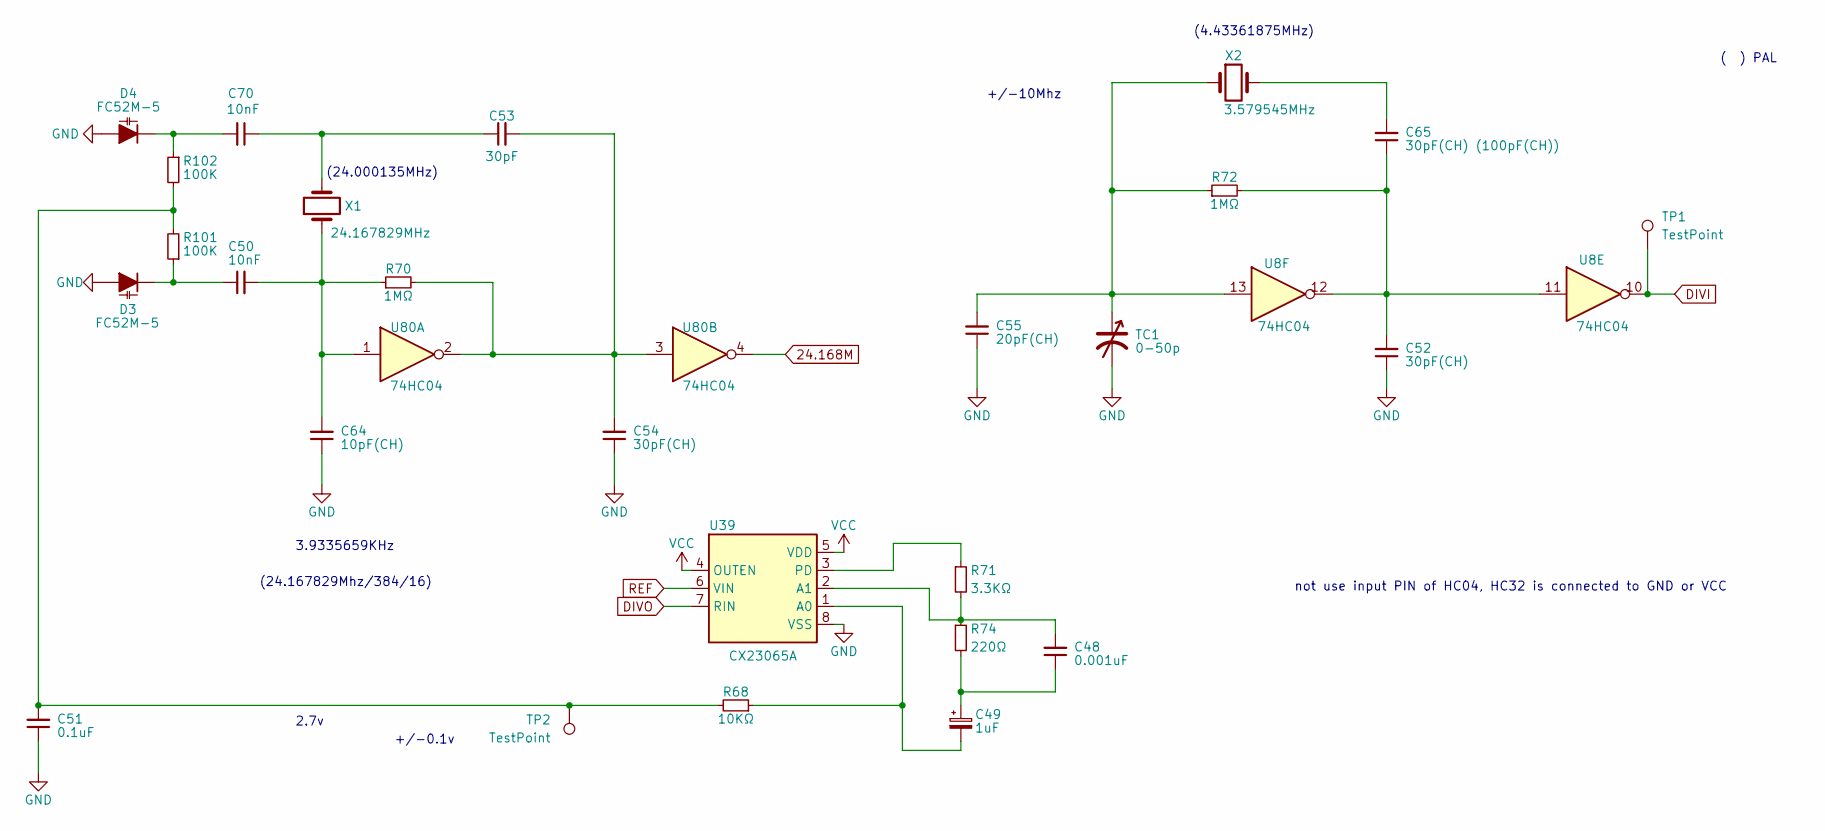
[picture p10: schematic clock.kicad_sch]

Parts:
C48: 0.001uF; CAP3-5mm
C49: 1uF; CAP2-2.5mm
C50, C70: 10nF; CAP3-5mm
C51: 0.1uF; CAP3-5mm
C52: 30pF(CH); CAP1-5mm
C53: 30pF; CAP3-5mm
C54: 30pF(CH); CAP3-5mm
C55: 20pF(CH); CAP1-5mm
C64: 10pF(CH); CAP3-5mm
C65: 30pF(CH) (100pF(CH)); CAP1-5mm
D3, D4: FC52M-5; SOD-70_P2.54mm
R68: 10KΩ; Resistor1-5mm
R70, R72: 1MΩ; Resistor1-5mm
R71: 3.3KΩ; Resistor1-5mm
R74: 220Ω; Resistor1-5mm
R101, R102: 100K; Resistor1-5mm
TC1: 0-50p; R_Axial_DIN0204_L3.6mm_D1.6mm_P5.08mm_Vertical
TP1: TestPoint; TestPoint_Pad_D1.5mm
TP2: TestPoint; TestPoint_THTPad_D1.5mm_Drill0.7mm
U8, U80: 74HC04; DIP-14_W7.62mm
U39: CX23065A
X1: 24.167829MHz; Crystal
X2: 3.579545MHz; Crystal

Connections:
24.168M: U80.4
DIVI: TP1.1, U8.10; also elsewhere on the board
DIVO: U39.7 (RIN); also elsewhere on the board
unnamed: C48.1, C49.1, R74.2
unnamed: C50.2, C64.2, R70.1, U80.1, X1.1
unnamed: C51.2, R68.2, R101.2, R102.2, TP2.1
unnamed: C52.2, C65.1, R72.2, U8.11, U8.12
unnamed: C53.1, C70.1, X1.2
unnamed: C53.2, C54.2, R70.2, U80.2, U80.3
unnamed: C55.2, R72.1, TC1.1, U8.13, X2.1
unnamed: C65.2, X2.2
unnamed: C50.1, D3.1 (K), R101.1
unnamed: C70.2, D4.1 (K), R102.1
unnamed: C49.2, R68.1, U39.1 (A0)
unnamed: C48.2, R71.2, R74.1, U39.2 (A1)
unnamed: R71.1, U39.3 (PD)
REF: U39.6 (VIN); also elsewhere on the board
VCC: U39.4 (OUTEN), U39.5 (VDD); also elsewhere on the board

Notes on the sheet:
2.7v
(4.43361875MHz)
+/-0.1v
(24.167829Mhz/384/16)
( ) PAL
(24.000135MHz)
not use input PIN of HC04, HC32 is connected to GND or VCC
+/-10Mhz
3.9335659KHz

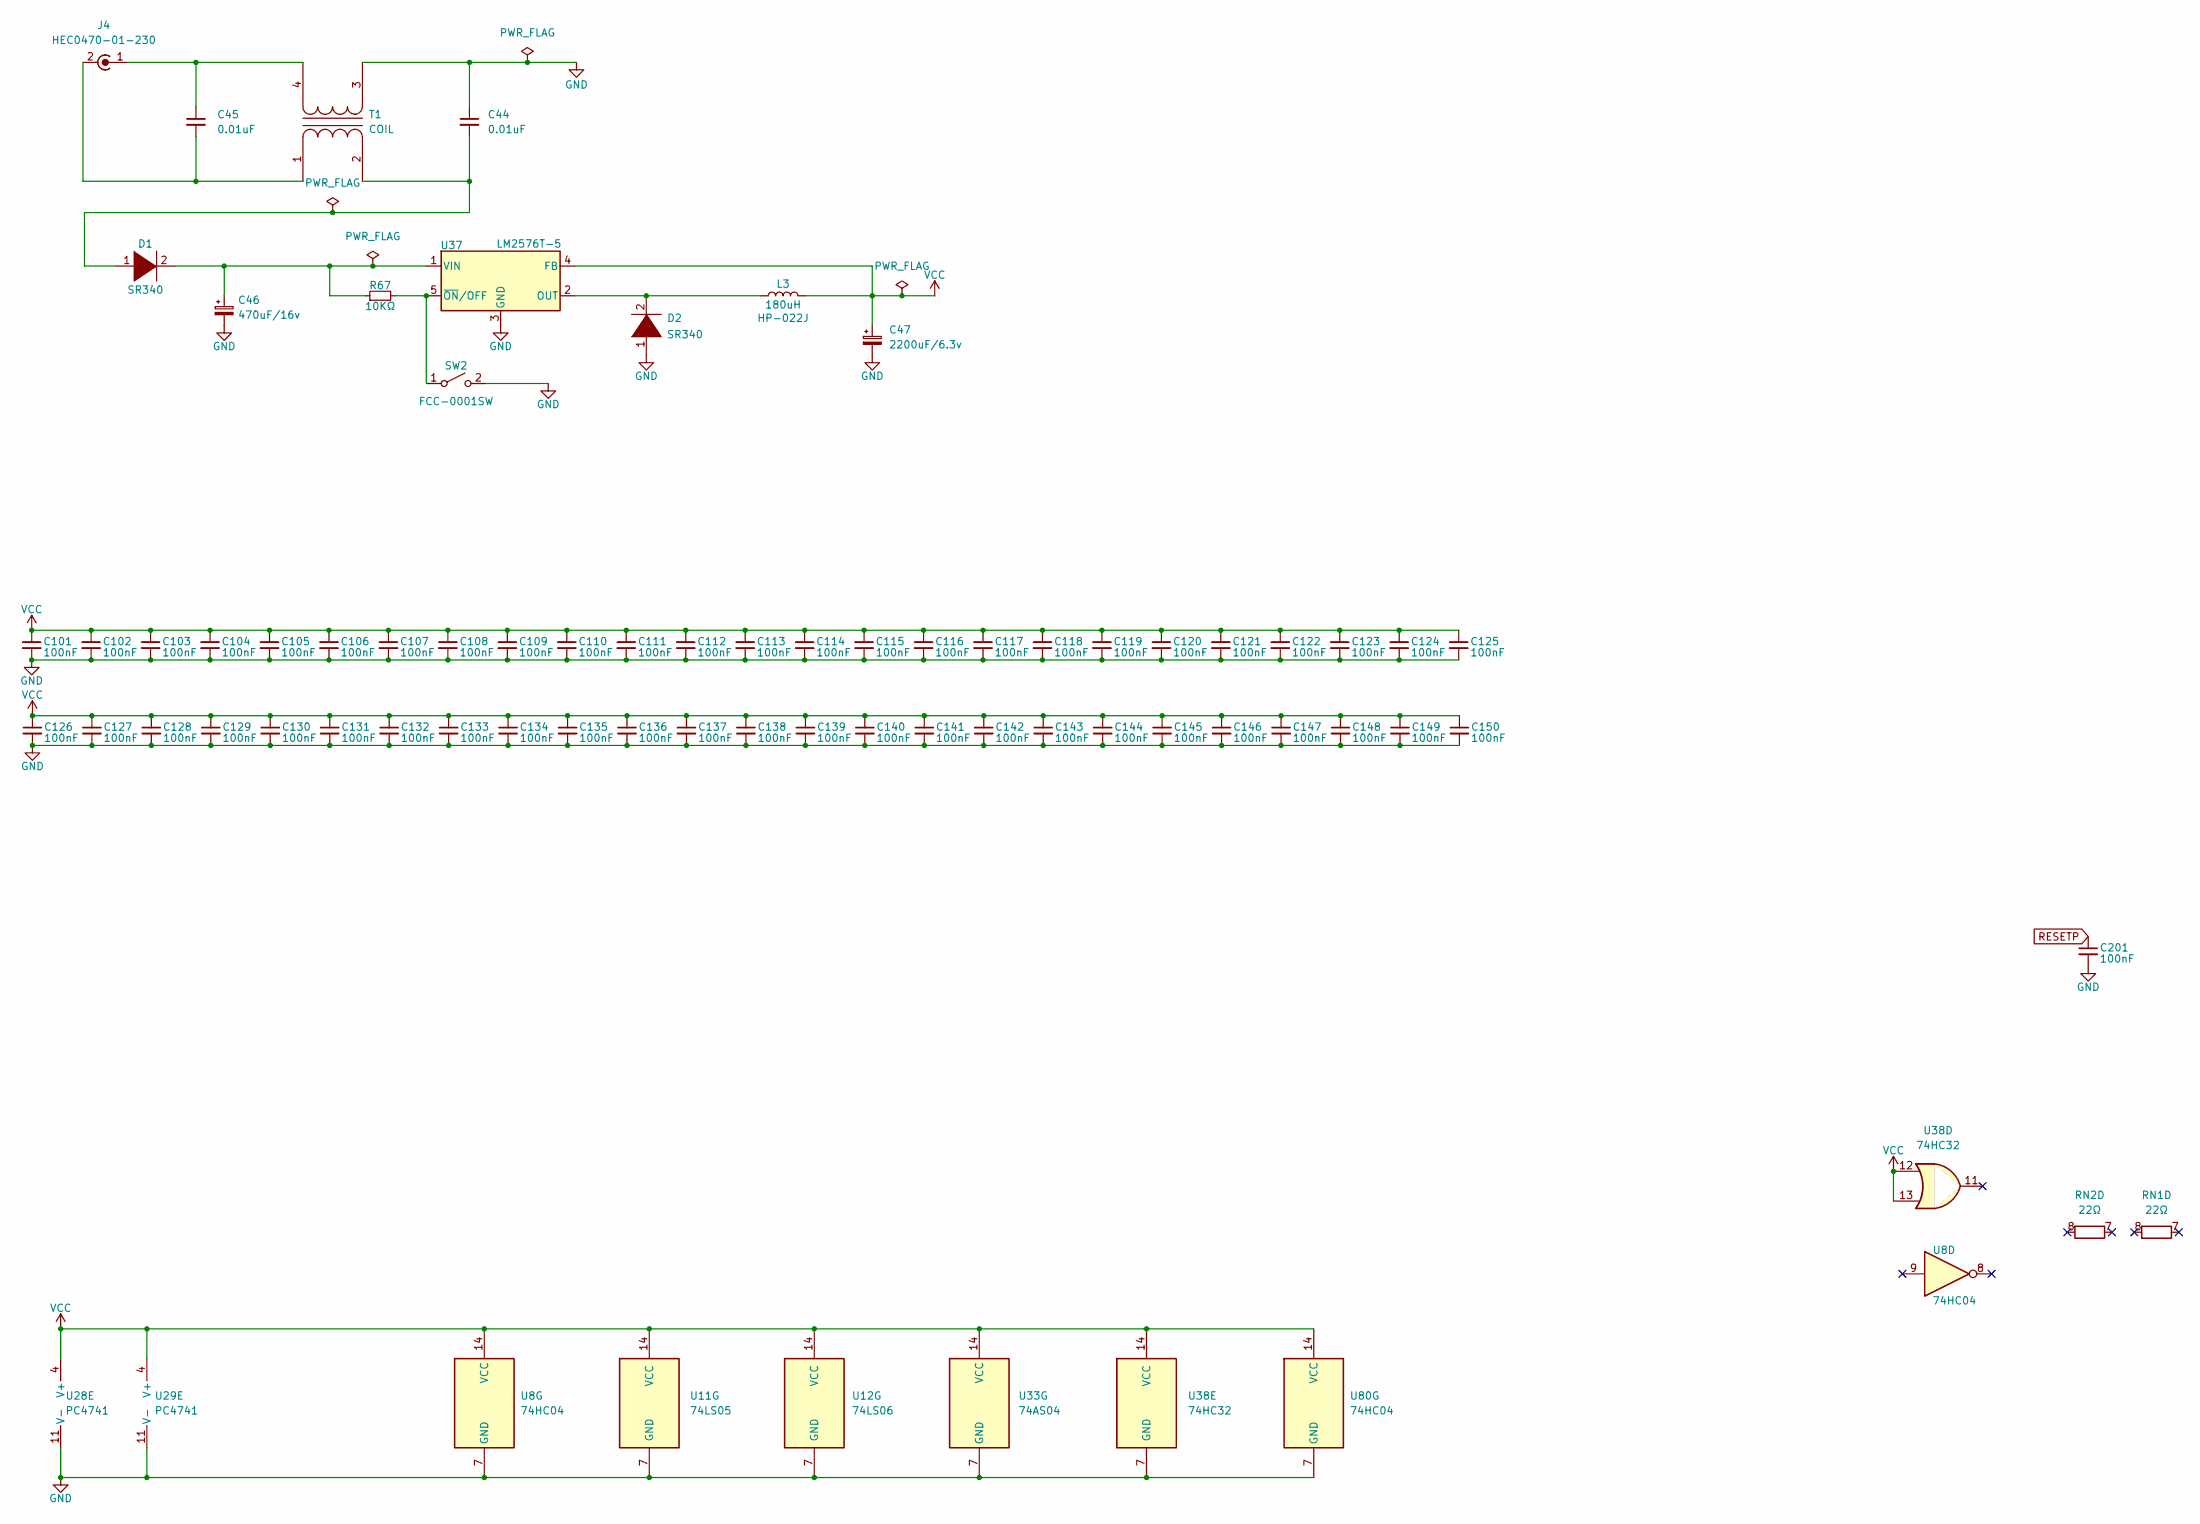
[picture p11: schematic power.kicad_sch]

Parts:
C44, C45: 0.01uF; CAP1-5mm
C46: 470uF/16v; CAP3-5mm
C47: 2200uF/6.3v; CAP3-5mm
C101, C102, C103, C104, C105, C106, C107, C108, C109, C110, C111, C112, C114, C115, C116, C117, C118, C119, C120, C121, C122, C123, C124, C125, C126, C127, C128, C129, C130, C131, C132, C133, C134, C135, C136, C137, C138, C139, C140, C141, C142, C143, C144, C145, C146, C147, C148, C149, C150, C201: 100nF; CAP3-5mm
C113: 100nF; CAP2-2.5mm
D1, D2: SR340; D_A-405_P10.16mm_Horizontal
J4: HEC0470-01-230; SolderJumper-2_P1.3mm_Open_Pad1.0x1.5mm
L3: 180uH; Resistor1-5mm
R67: 10KΩ; Resistor1-5mm
RN1, RN2: 22Ω; RN2
SW2: FCC-0001SW; SW_Tactile_Straight_KSL0Axx1LFTR
T1: COIL; Transformer_NF_ETAL_1-1_P1200
U8, U80: 74HC04; DIP-14_W7.62mm
U11: 74LS05; DIP-14_W7.62mm
U12: 74LS06; DIP-14_W7.62mm
U28, U29: PC4741; DIP-14_W7.62mm
U33: 74AS04; DIP-14_W7.62mm
U37: LM2576T-5; TO-220-5_Vertical
U38: 74HC32; DIP-14_W7.62mm

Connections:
unnamed: C44.2, D1.1 (K), T1.2 (AB)
unnamed: C46.1, D1.2 (A), R67.1, U37.1 (VIN)
unnamed: D2.2 (A), L3.1, U37.2 (OUT)
unnamed: C45.2, J4.2 (Ext), T1.1 (AA)
unnamed: C45.1, J4.1 (In), T1.4 (SB)
unnamed: R67.2, SW2.1 (A), U37.5 (~ON/OFF)
RESETP: C201.1; also elsewhere on the board
VCC: C47.1, C101.1, C102.1, C103.1, C104.1, C105.1, C106.1, C107.1, C108.1, C109.1, C110.1, C111.1, C112.1, C113.1, C114.1, C115.1, C116.1, C117.1, C118.1, C119.1, C120.1, C121.1, C122.1, C123.1, C124.1, C125.1, C126.1, C127.1, C128.1, C129.1, C130.1, C131.1, C132.1, C133.1, C134.1, C135.1, C136.1, C137.1, C138.1, C139.1, C140.1, C141.1, C142.1, C143.1, C144.1, C145.1, C146.1, C147.1, C148.1, C149.1, C150.1, L3.2, U8.14 (VCC), U11.14 (VCC), U12.14 (VCC), U28.4 (V+), U29.4 (V+), U33.14 (VCC), U37.4 (FB), U38.12, U38.13, U38.14 (VCC), U80.14 (VCC); also elsewhere on the board

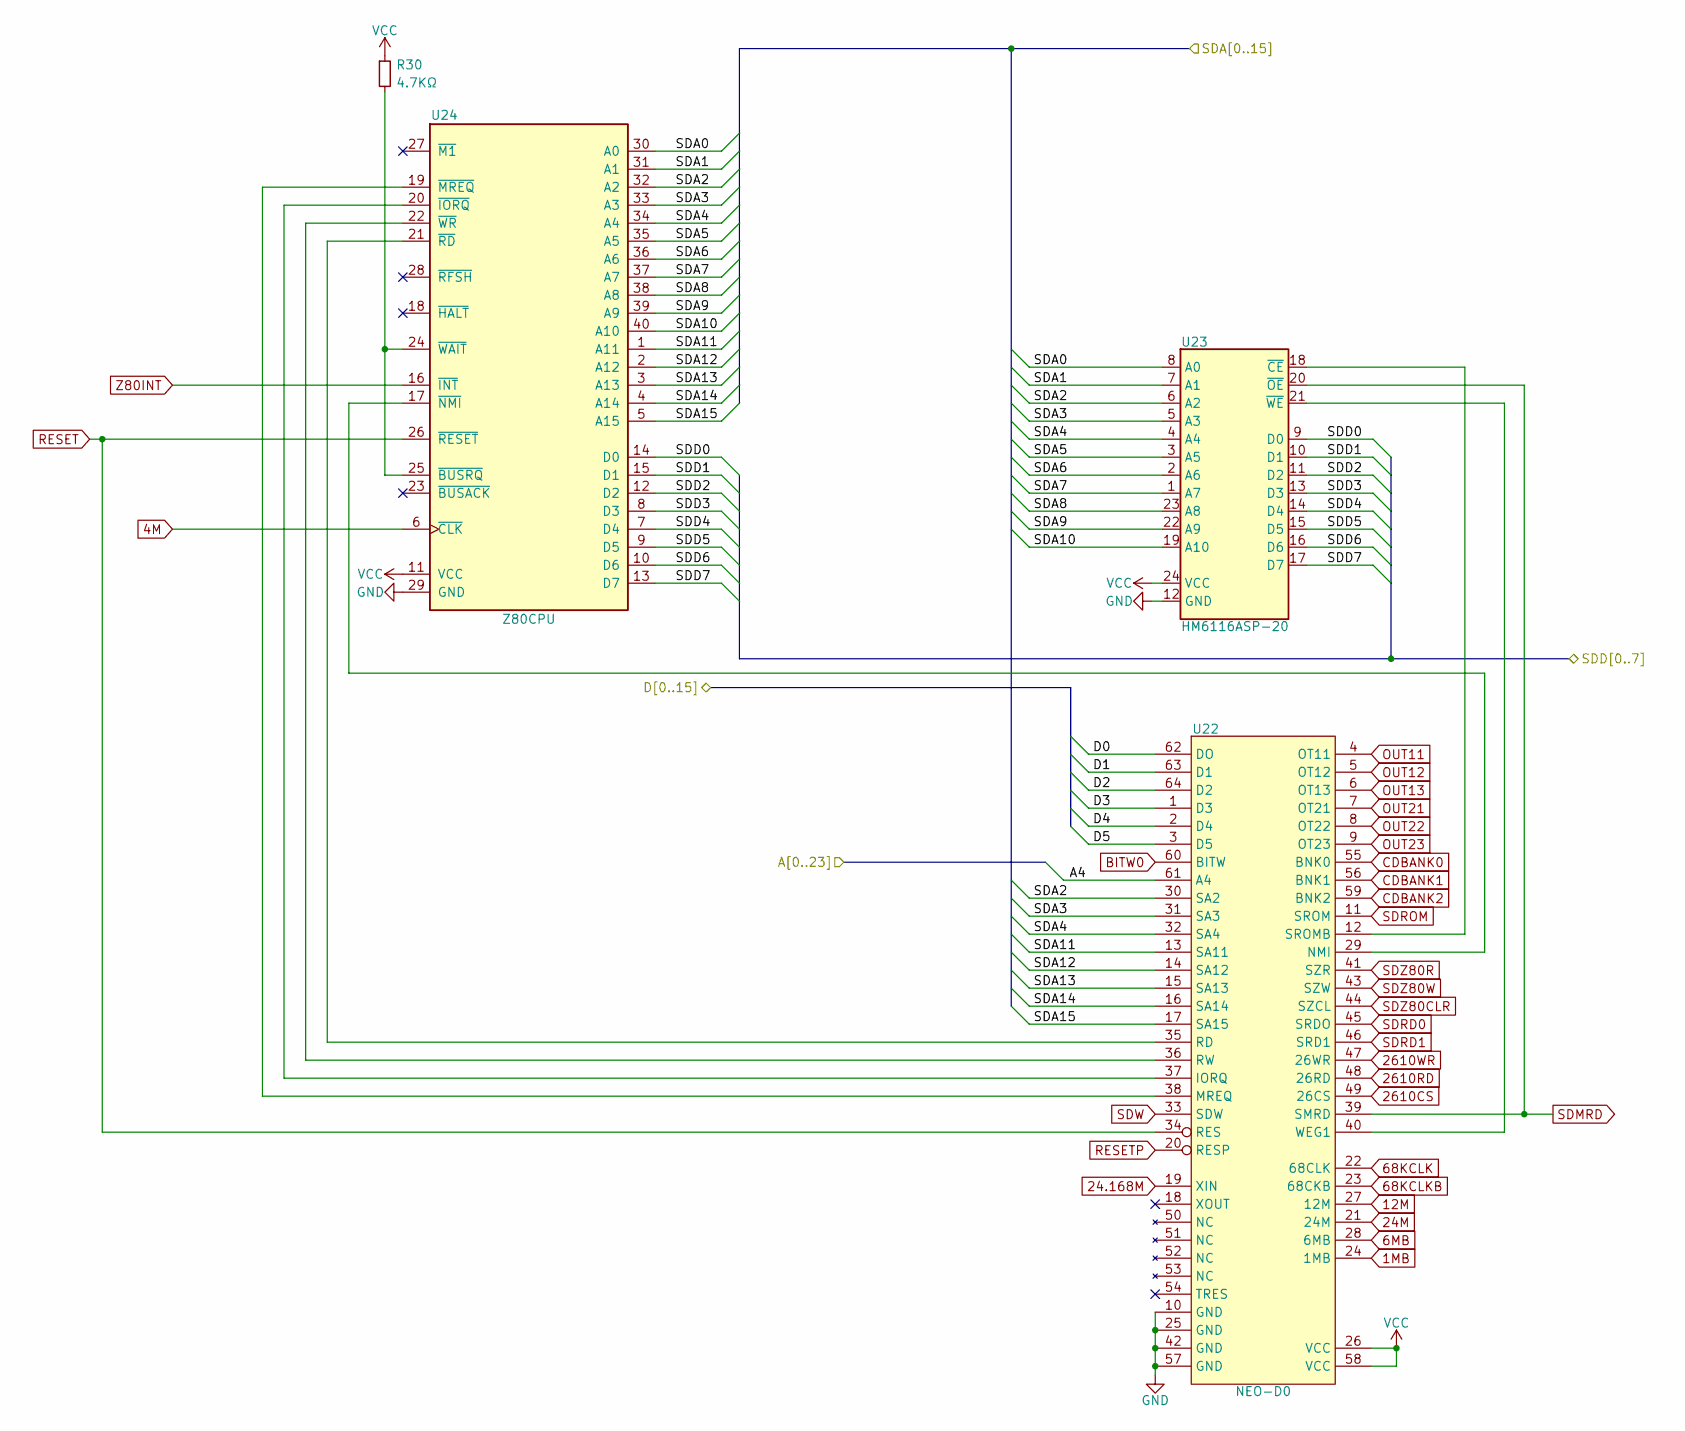
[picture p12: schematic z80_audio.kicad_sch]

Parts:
R30: 4.7KΩ; Resistor1-5mm
U22: NEO-D0; NEO-G0
U23: HM6116ASP-20; DIP-24_W7.62mm
U24: Z80CPU; DIP-40_W15.24mm

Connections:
1MB: U22.24 (1MB); also elsewhere on the board
4M: U24.6 (~CLK); also elsewhere on the board
6MB: U22.28 (6MB); also elsewhere on the board
12M: U22.27 (12M); also elsewhere on the board
24M: U22.21 (24M); also elsewhere on the board
68KCLK: U22.22 (68CLK); also elsewhere on the board
68KCLKB: U22.23 (68CKB); also elsewhere on the board
2610CS: U22.49 (26CS); also elsewhere on the board
2610RD: U22.48 (26RD); also elsewhere on the board
2610WR: U22.47 (26WR); also elsewhere on the board
/CPU/A4: U22.61 (A4); also elsewhere on the board
/CPU/D0: U22.62 (DO); also elsewhere on the board
/CPU/D1: U22.63 (D1); also elsewhere on the board
/CPU/D4: U22.2 (D4); also elsewhere on the board
/CPU/D5: U22.3 (D5); also elsewhere on the board
/CPU/SDD0: U23.9 (D0), U24.14 (D0); also elsewhere on the board
/CPU/SDD1: U23.10 (D1), U24.15 (D1); also elsewhere on the board
/CPU/SDD2: U23.11 (D2), U24.12 (D2); also elsewhere on the board
/CPU/SDD3: U23.13 (D3), U24.8 (D3); also elsewhere on the board
/CPU/SDD4: U23.14 (D4), U24.7 (D4); also elsewhere on the board
/CPU/SDD5: U23.15 (D5), U24.9 (D5); also elsewhere on the board
/CPU/SDD6: U23.16 (D6), U24.10 (D6); also elsewhere on the board
/CPU/SDD7: U23.17 (D7), U24.13 (D7); also elsewhere on the board
/Cartridge Slots/SDA0: U23.8 (A0), U24.30 (A0); also elsewhere on the board
/Cartridge Slots/SDA1: U23.7 (A1), U24.31 (A1); also elsewhere on the board
/Cartridge Slots/SDA2: U22.30 (SA2), U23.6 (A2), U24.32 (A2); also elsewhere on the board
/Cartridge Slots/SDA3: U22.31 (SA3), U23.5 (A3), U24.33 (A3); also elsewhere on the board
/Cartridge Slots/SDA4: U22.32 (SA4), U23.4 (A4), U24.34 (A4); also elsewhere on the board
/Cartridge Slots/SDA5: U23.3 (A5), U24.35 (A5); also elsewhere on the board
/Cartridge Slots/SDA6: U23.2 (A6), U24.36 (A6); also elsewhere on the board
/Cartridge Slots/SDA7: U23.1 (A7), U24.37 (A7); also elsewhere on the board
/Cartridge Slots/SDA8: U23.23 (A8), U24.38 (A8); also elsewhere on the board
/Cartridge Slots/SDA9: U23.22 (A9), U24.39 (A9); also elsewhere on the board
/Cartridge Slots/SDA10: U23.19 (A10), U24.40 (A10); also elsewhere on the board
/Cartridge Slots/SDA11: U22.13 (SA11), U24.1 (A11); also elsewhere on the board
/Cartridge Slots/SDA12: U22.14 (SA12), U24.2 (A12); also elsewhere on the board
/Cartridge Slots/SDA13: U22.15 (SA13), U24.3 (A13); also elsewhere on the board
/Cartridge Slots/SDA14: U22.16 (SA14), U24.4 (A14); also elsewhere on the board
/Cartridge Slots/SDA15: U22.17 (SA15), U24.5 (A15); also elsewhere on the board
BITW0: U22.60 (BITW); also elsewhere on the board
CDBANK0: U22.55 (BNK0); also elsewhere on the board
CDBANK1: U22.56 (BNK1)
CDBANK2: U22.59 (BNK2)
unnamed: U22.37 (IORQ), U24.20 (~IORQ)
unnamed: U22.38 (MREQ), U24.19 (~MREQ)
unnamed: U22.29 (NMI), U24.17 (~NMI)
unnamed: U22.35 (RD), U24.21 (~RD)
unnamed: U22.36 (RW), U24.22 (~WR)
unnamed: U22.12 (SROMB), U23.18 (~CE)
unnamed: U22.40 (WEG1), U23.21 (~WE)
unnamed: R30.2, U24.24 (~WAIT), U24.25 (~BUSRQ)
OUT11: U22.4 (OT11); also elsewhere on the board
OUT12: U22.5 (OT12); also elsewhere on the board
OUT13: U22.6 (OT13); also elsewhere on the board
OUT21: U22.7 (OT21); also elsewhere on the board
OUT22: U22.8 (OT22); also elsewhere on the board
OUT23: U22.9 (OT23); also elsewhere on the board
RESET: U22.34 (RES), U24.26 (~RESET); also elsewhere on the board
SDMRD: U22.39 (SMRD), U23.20 (~OE); also elsewhere on the board
SDRD0: U22.45 (SRDO); also elsewhere on the board
SDRD1: U22.46 (SRD1); also elsewhere on the board
SDROM: U22.11 (SROM); also elsewhere on the board
SDZ80CLR: U22.44 (SZCL); also elsewhere on the board
SDZ80R: U22.41 (SZR); also elsewhere on the board
SDZ80W: U22.43 (SZW); also elsewhere on the board
VCC: R30.1, U22.26 (VCC), U22.58 (VCC), U23.24 (VCC), U24.11 (VCC); also elsewhere on the board
Z80INT: U24.16 (~INT); also elsewhere on the board

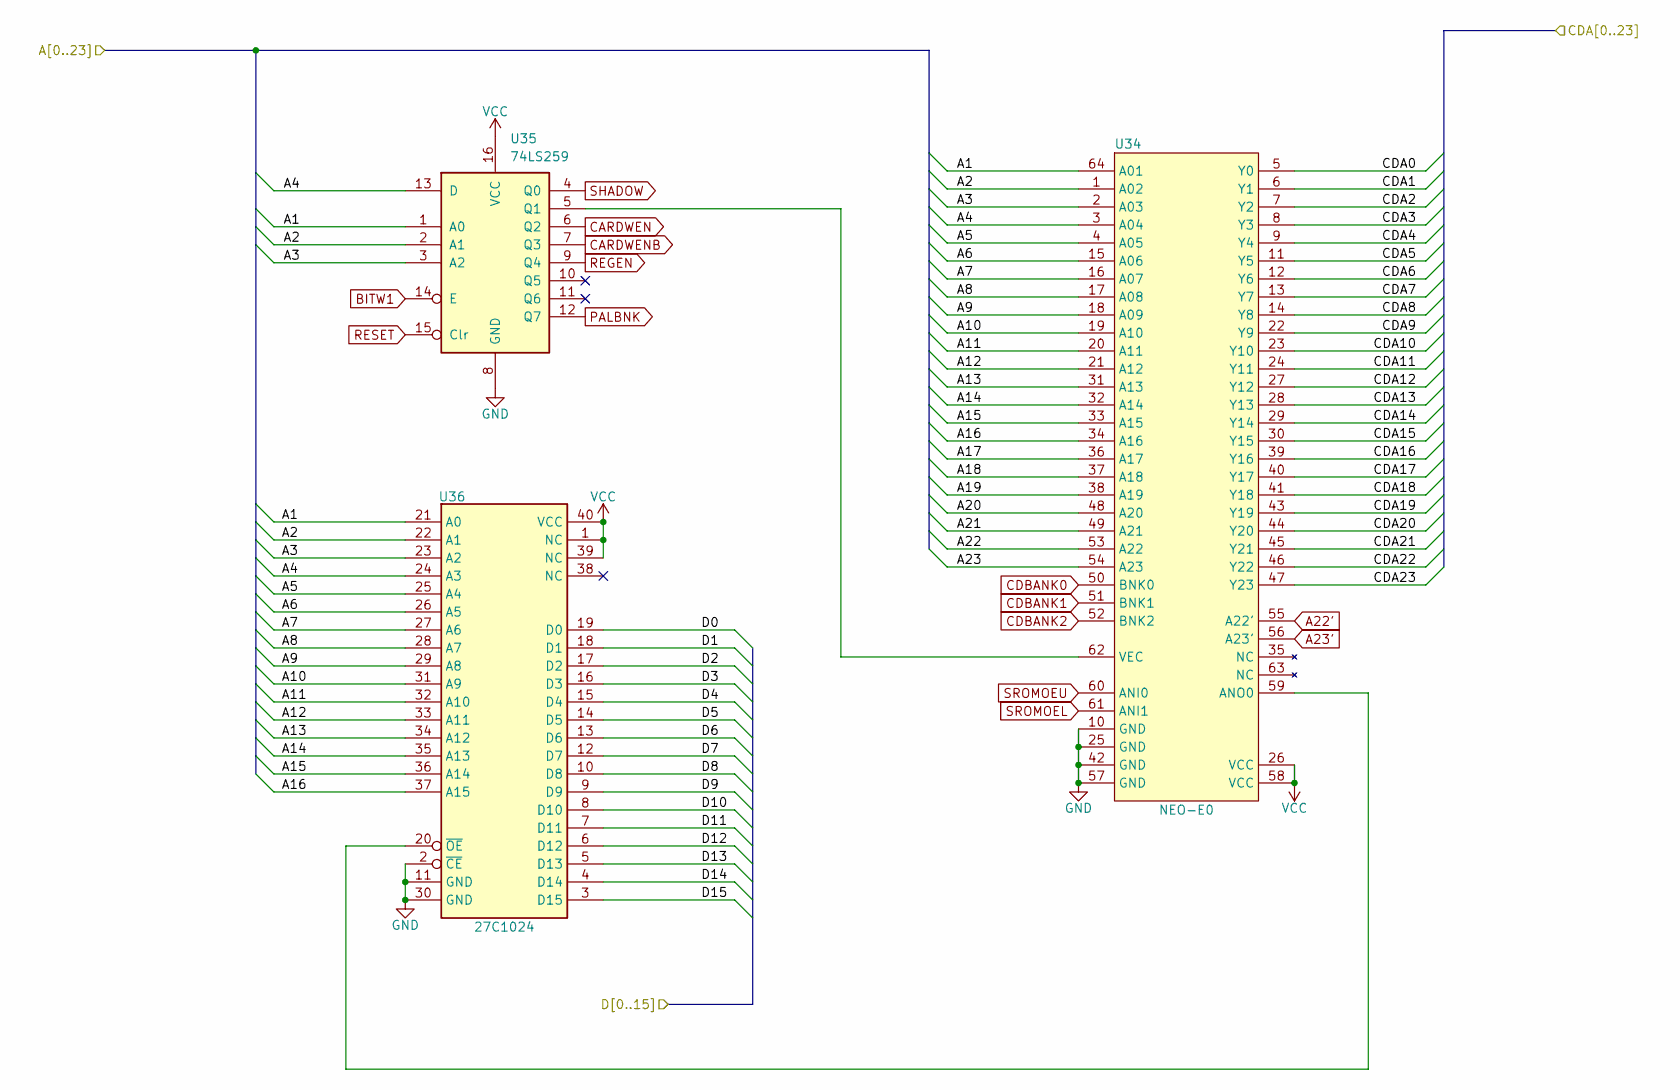
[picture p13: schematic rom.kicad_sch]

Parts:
U34: NEO-E0; NEO-G0
U35: 74LS259; DIP-16_W7.62mm
U36: 27C1024; DIP-40_W15.24mm

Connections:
/CARD INTERFACE/CDA0: U34.5 (Y0); also elsewhere on the board
/CARD INTERFACE/CDA1: U34.6 (Y1); also elsewhere on the board
/CARD INTERFACE/CDA2: U34.7 (Y2); also elsewhere on the board
/CARD INTERFACE/CDA3: U34.8 (Y3); also elsewhere on the board
/CARD INTERFACE/CDA4: U34.9 (Y4); also elsewhere on the board
/CARD INTERFACE/CDA5: U34.11 (Y5); also elsewhere on the board
/CARD INTERFACE/CDA6: U34.12 (Y6); also elsewhere on the board
/CARD INTERFACE/CDA7: U34.13 (Y7); also elsewhere on the board
/CARD INTERFACE/CDA8: U34.14 (Y8); also elsewhere on the board
/CARD INTERFACE/CDA9: U34.22 (Y9); also elsewhere on the board
/CARD INTERFACE/CDA10: U34.23 (Y10); also elsewhere on the board
/CARD INTERFACE/CDA11: U34.24 (Y11); also elsewhere on the board
/CARD INTERFACE/CDA12: U34.27 (Y12); also elsewhere on the board
/CARD INTERFACE/CDA13: U34.28 (Y13); also elsewhere on the board
/CARD INTERFACE/CDA14: U34.29 (Y14); also elsewhere on the board
/CARD INTERFACE/CDA15: U34.30 (Y15); also elsewhere on the board
/CARD INTERFACE/CDA16: U34.39 (Y16); also elsewhere on the board
/CARD INTERFACE/CDA17: U34.40 (Y17); also elsewhere on the board
/CARD INTERFACE/CDA18: U34.41 (Y18); also elsewhere on the board
/CARD INTERFACE/CDA19: U34.43 (Y19); also elsewhere on the board
/CARD INTERFACE/CDA20: U34.44 (Y20); also elsewhere on the board
/CARD INTERFACE/CDA21: U34.45 (Y21); also elsewhere on the board
/CARD INTERFACE/CDA22: U34.46 (Y22); also elsewhere on the board
/CARD INTERFACE/CDA23: U34.47 (Y23); also elsewhere on the board
/CPU/A1: U34.64 (A01), U35.1 (A0), U36.21 (A0); also elsewhere on the board
/CPU/A2: U34.1 (A02), U35.2 (A1), U36.22 (A1); also elsewhere on the board
/CPU/A3: U34.2 (A03), U35.3 (A2), U36.23 (A2); also elsewhere on the board
/CPU/A4: U34.3 (A04), U35.13 (D), U36.24 (A3); also elsewhere on the board
/CPU/A5: U34.4 (A05), U36.25 (A4); also elsewhere on the board
/CPU/A6: U34.15 (A06), U36.26 (A5); also elsewhere on the board
/CPU/A7: U34.16 (A07), U36.27 (A6); also elsewhere on the board
/CPU/A8: U34.17 (A08), U36.28 (A7); also elsewhere on the board
/CPU/A9: U34.18 (A09), U36.29 (A8); also elsewhere on the board
/CPU/A10: U34.19 (A10), U36.31 (A9); also elsewhere on the board
/CPU/A11: U34.20 (A11), U36.32 (A10); also elsewhere on the board
/CPU/A12: U34.21 (A12), U36.33 (A11); also elsewhere on the board
/CPU/A13: U34.31 (A13), U36.34 (A12); also elsewhere on the board
/CPU/A14: U34.32 (A14), U36.35 (A13); also elsewhere on the board
/CPU/A15: U34.33 (A15), U36.36 (A14); also elsewhere on the board
/CPU/A16: U34.34 (A16), U36.37 (A15); also elsewhere on the board
/CPU/A17: U34.36 (A17); also elsewhere on the board
/CPU/A18: U34.37 (A18); also elsewhere on the board
/CPU/A19: U34.38 (A19); also elsewhere on the board
/CPU/A20: U34.48 (A20); also elsewhere on the board
/CPU/A21: U34.49 (A21); also elsewhere on the board
/CPU/A22: U34.53 (A22); also elsewhere on the board
/CPU/A23: U34.54 (A23); also elsewhere on the board
/CPU/D0: U36.19 (D0); also elsewhere on the board
/CPU/D1: U36.18 (D1); also elsewhere on the board
/CPU/D2: U36.17 (D2); also elsewhere on the board
/CPU/D3: U36.16 (D3); also elsewhere on the board
/CPU/D4: U36.15 (D4); also elsewhere on the board
/CPU/D5: U36.14 (D5); also elsewhere on the board
/CPU/D6: U36.13 (D6); also elsewhere on the board
/CPU/D7: U36.12 (D7); also elsewhere on the board
/CPU/D8: U36.10 (D8); also elsewhere on the board
/CPU/D9: U36.9 (D9); also elsewhere on the board
/CPU/D10: U36.8 (D10); also elsewhere on the board
/CPU/D11: U36.7 (D11); also elsewhere on the board
/CPU/D12: U36.6 (D12); also elsewhere on the board
/CPU/D13: U36.5 (D13); also elsewhere on the board
/CPU/D14: U36.4 (D14); also elsewhere on the board
/CPU/D15: U36.3 (D15); also elsewhere on the board
A22': U34.55 (A22'); also elsewhere on the board
A23': U34.56 (A23'); also elsewhere on the board
BITW1: U35.14 (E)
CARDWEN: U35.6 (Q2); also elsewhere on the board
CARDWENB: U35.7 (Q3); also elsewhere on the board
CDBANK0: U34.50 (BNK0); also elsewhere on the board
unnamed: U34.59 (ANO0), U36.20 (~OE)
unnamed: U34.62 (VEC), U35.5 (Q1)
PALBNK: U35.12 (Q7); also elsewhere on the board
REGEN: U35.9 (Q4); also elsewhere on the board
RESET: U35.15 (Clr); also elsewhere on the board
SHADOW: U35.4 (Q0); also elsewhere on the board
SROMOEL: U34.61 (ANI1); also elsewhere on the board
SROMOEU: U34.60 (ANI0); also elsewhere on the board
VCC: U34.26 (VCC), U34.58 (VCC), U35.16 (VCC), U36.1 (NC), U36.39 (NC), U36.40 (VCC); also elsewhere on the board

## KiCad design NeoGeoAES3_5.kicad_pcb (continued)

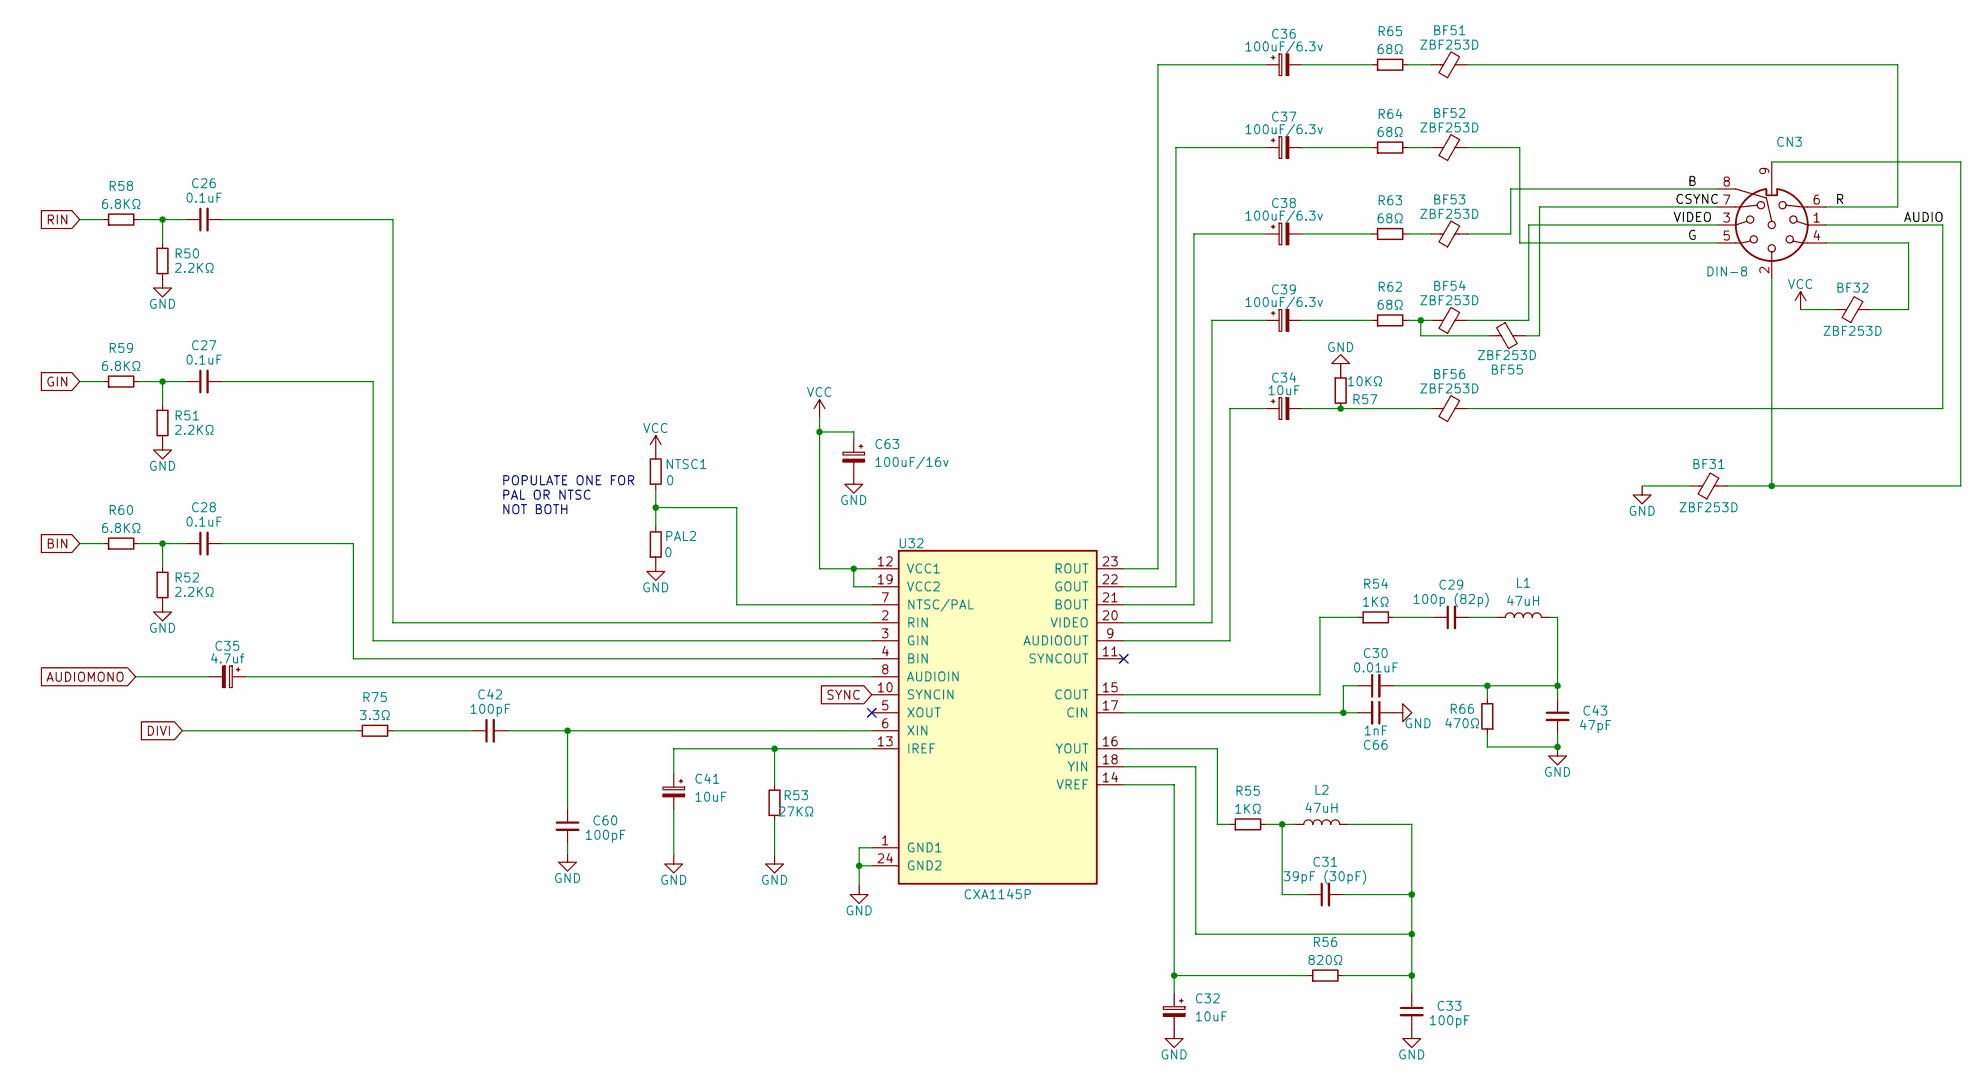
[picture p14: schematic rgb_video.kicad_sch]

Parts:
BF31, BF32, BF51, BF52, BF53, BF54, BF55, BF56: ZBF253D; BF-2.5mm
C26, C27, C28: 0.1uF; CAP3-5mm
C29: 100p (82p); CAP3-5mm
C30: 0.01uF; CAP3-5mm
C31: 39pF (30pF); CAP3-5mm
C32, C34, C41: 10uF; CAP2-2.5mm
C33, C42, C60: 100pF; CAP3-5mm
C35: 4.7uf; CAP2-2.5mm
C36, C37, C38, C39: 100uF/6.3v; CAP1-5mm
C43: 47pF; CAP3-5mm
C63: 100uF/16v; CAP3-5mm
C66: 1nF; CAP3-5mm
CN3: DIN-8; DSUB-9_Female_Horizontal_P2.77x2.84mm_EdgePinOffset4.94mm_H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
L1, L2: 47uH; Inductor
NTSC1: 0; PAL
PAL2: 0; PAL
R50, R51, R52: 2.2KΩ; Resistor1-5mm
R53: 27KΩ; Resistor1-5mm
R54, R55: 1KΩ; Resistor1-5mm
R56: 820Ω; Resistor1-5mm
R57: 10KΩ; Resistor1-5mm
R58, R59, R60: 6.8KΩ; Resistor1-5mm
R62, R63, R64, R65: 68Ω; Resistor1-5mm
R66: 470Ω; Resistor1-5mm
R75: 3.3Ω; Resistor1-5mm
U32: CXA1145P; DIP-24_W10.16mm

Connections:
/RGB VIDEO/AUDIO: BF56.2, CN3.1
/RGB VIDEO/B: BF53.2, CN3.8
/RGB VIDEO/CSYNC: BF55.2, CN3.7
/RGB VIDEO/G: BF52.2, CN3.5
/RGB VIDEO/R: BF51.2, CN3.6
/RGB VIDEO/VIDEO: BF54.2, CN3.3
AUDIOMONO: C35.2; also elsewhere on the board
BIN: R60.1; also elsewhere on the board
DIVI: R75.1; also elsewhere on the board
GIN: R59.1; also elsewhere on the board
unnamed: BF31.2, CN3.2, CN3.9
unnamed: BF32.2, CN3.4
unnamed: BF51.1, R65.2
unnamed: BF52.1, R64.2
unnamed: BF53.1, R63.2
unnamed: BF54.1, BF55.1, R62.2
unnamed: BF56.1, C34.2, R57.2
unnamed: C26.1, R50.1, R58.2
unnamed: C27.1, R51.1, R59.2
unnamed: C28.1, R52.1, R60.2
unnamed: C29.1, R54.2
unnamed: C29.2, L1.1
unnamed: C30.2, C43.1, L1.2, R66.2
unnamed: C31.1, L2.1, R55.2
unnamed: C36.2, R65.1
unnamed: C37.2, R64.1
unnamed: C38.2, R63.1
unnamed: C39.2, R62.1
unnamed: C42.1, R75.2
unnamed: C35.1, U32.8 (AUDIOIN)
unnamed: C34.1, U32.9 (AUDIOOUT)
unnamed: C28.2, U32.4 (BIN)
unnamed: C38.1, U32.21 (BOUT)
unnamed: C30.1, C66.2, U32.17 (CIN)
unnamed: R54.1, U32.15 (COUT)
unnamed: C27.2, U32.3 (GIN)
unnamed: C37.1, U32.22 (GOUT)
unnamed: C41.1, R53.2, U32.13 (IREF)
unnamed: NTSC1.1, PAL2.2, U32.7 (NTSC/PAL)
unnamed: C26.2, U32.2 (RIN)
unnamed: C36.1, U32.23 (ROUT)
unnamed: C39.1, U32.20 (VIDEO)
unnamed: C32.1, R56.1, U32.14 (VREF)
unnamed: C42.2, C60.1, U32.6 (XIN)
unnamed: C31.2, C33.1, L2.2, R56.2, U32.18 (YIN)
unnamed: R55.1, U32.16 (YOUT)
RIN: R58.1; also elsewhere on the board
SYNC: U32.10 (SYNCIN); also elsewhere on the board
VCC: BF32.1, C63.1, NTSC1.2, U32.12 (VCC1), U32.19 (VCC2); also elsewhere on the board

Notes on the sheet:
POPULATE ONE FOR PAL OR NTSC NOT BOTH

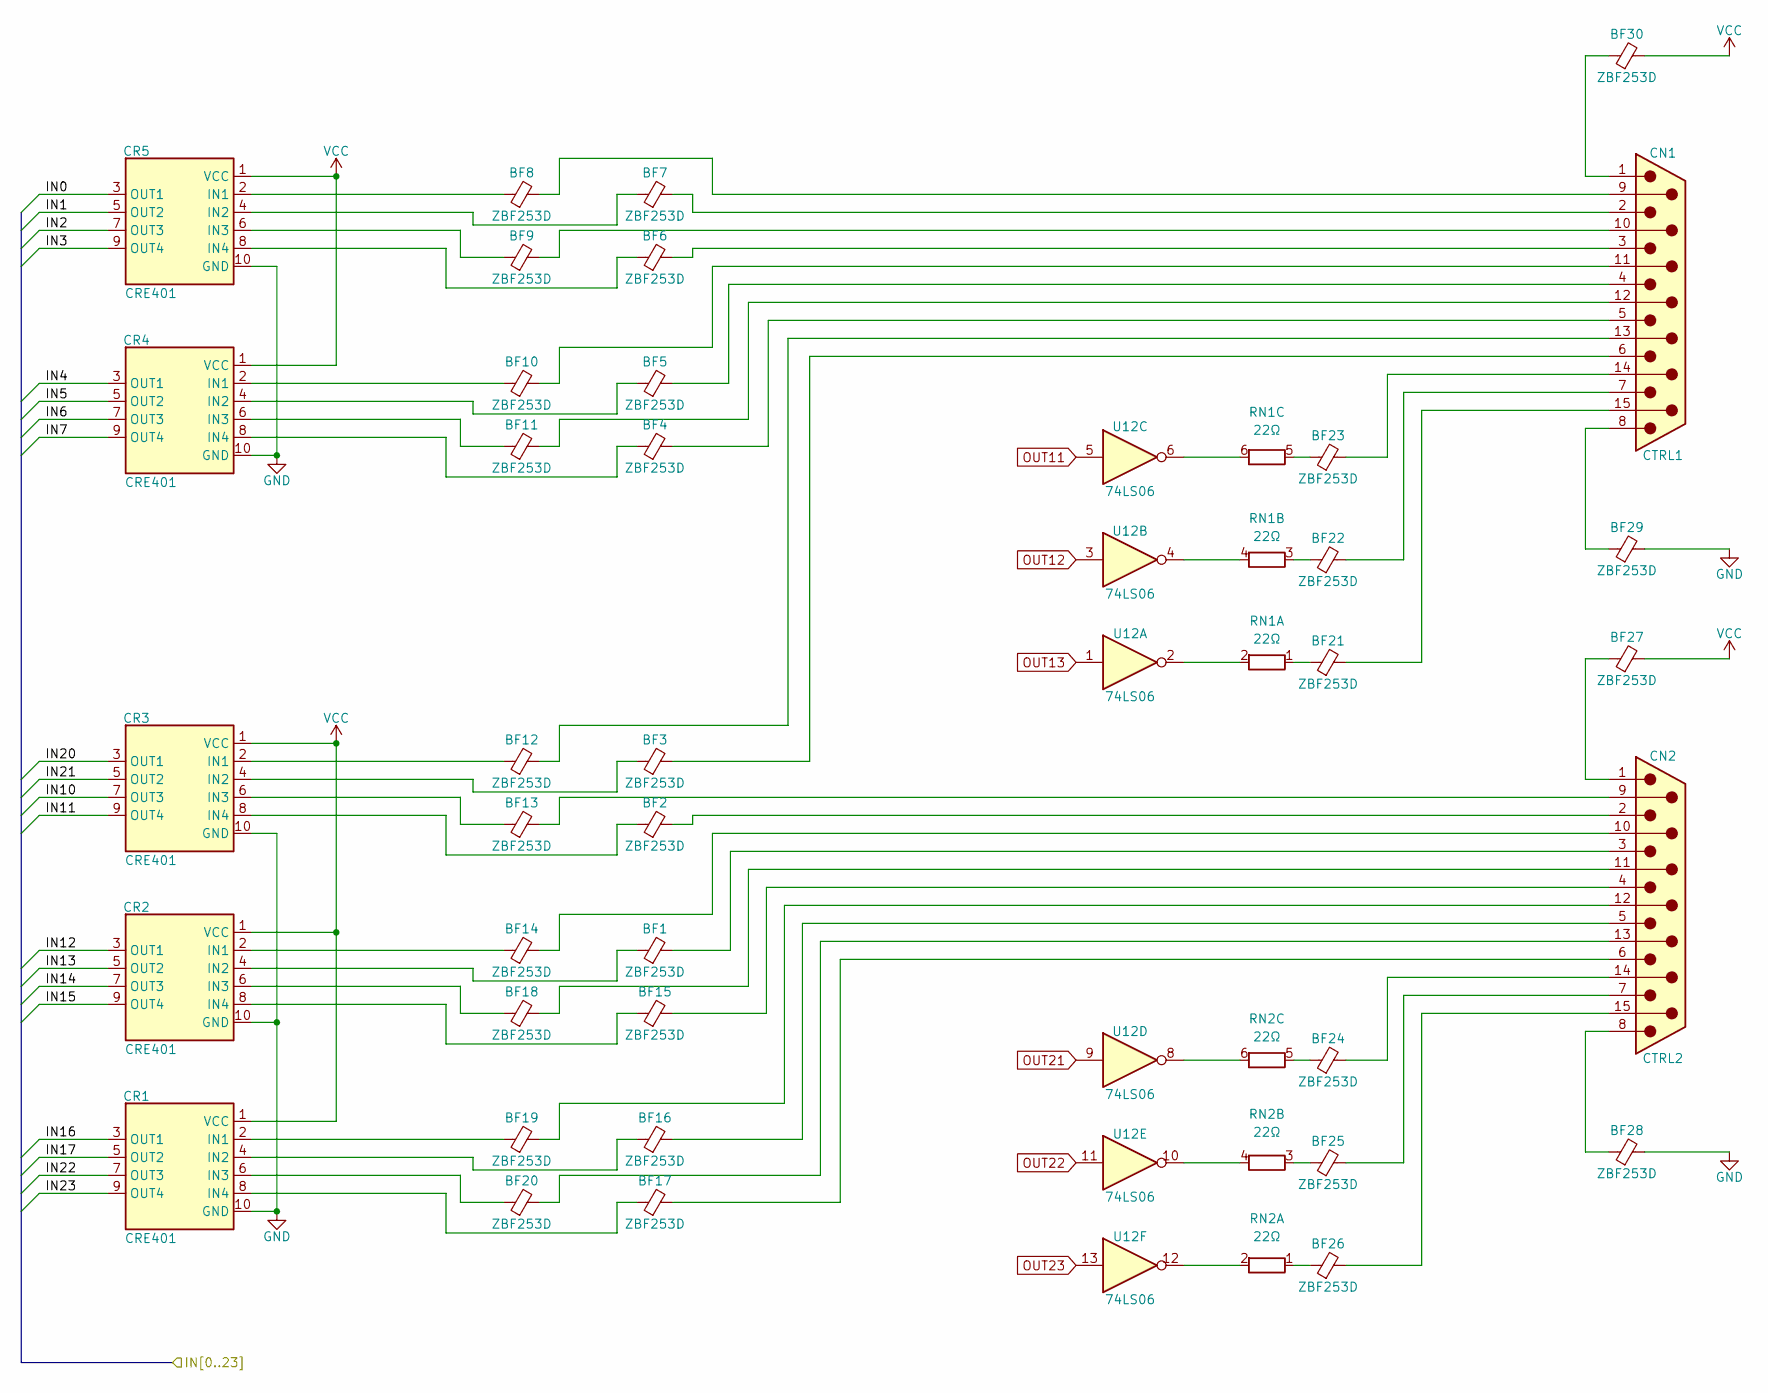
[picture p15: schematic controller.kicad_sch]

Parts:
BF1, BF2, BF3, BF4, BF5, BF6, BF7, BF8, BF9, BF10, BF11, BF12, BF13, BF14, BF15, BF16, BF17, BF18, BF19, BF20, BF21, BF22, BF23, BF24, BF25, BF26, BF27, BF28, BF29, BF30: ZBF253D; BF-2.5mm
CN1: CTRL1; CN1-2
CN2: CTRL2; CN1-2
CR1, CR2, CR3, CR4, CR5: CRE401; R_Array_SIP10
RN1, RN2: 22Ω; RN2
U12: 74LS06; DIP-14_W7.62mm

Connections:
/CONTROLLER/IN0: CR5.3 (OUT1); also elsewhere on the board
/CONTROLLER/IN1: CR5.5 (OUT2); also elsewhere on the board
/CONTROLLER/IN2: CR5.7 (OUT3); also elsewhere on the board
/CONTROLLER/IN3: CR5.9 (OUT4); also elsewhere on the board
/CONTROLLER/IN4: CR4.3 (OUT1); also elsewhere on the board
/CONTROLLER/IN5: CR4.5 (OUT2); also elsewhere on the board
/CONTROLLER/IN6: CR4.7 (OUT3); also elsewhere on the board
/CONTROLLER/IN7: CR4.9 (OUT4); also elsewhere on the board
/CONTROLLER/IN10: CR3.7 (OUT3); also elsewhere on the board
/CONTROLLER/IN11: CR3.9 (OUT4); also elsewhere on the board
/CONTROLLER/IN12: CR2.3 (OUT1); also elsewhere on the board
/CONTROLLER/IN13: CR2.5 (OUT2); also elsewhere on the board
/CONTROLLER/IN14: CR2.7 (OUT3); also elsewhere on the board
/CONTROLLER/IN15: CR2.9 (OUT4); also elsewhere on the board
/CONTROLLER/IN16: CR1.3 (OUT1); also elsewhere on the board
/CONTROLLER/IN17: CR1.5 (OUT2); also elsewhere on the board
/CONTROLLER/IN20: CR3.3 (OUT1); also elsewhere on the board
/CONTROLLER/IN21: CR3.5 (OUT2); also elsewhere on the board
/CONTROLLER/IN22: CR1.7 (OUT3); also elsewhere on the board
/CONTROLLER/IN23: CR1.9 (OUT4); also elsewhere on the board
unnamed: BF1.2, CN2.3
unnamed: BF2.2, CN2.2
unnamed: BF3.2, CN1.6
unnamed: BF4.2, CN1.5
unnamed: BF5.2, CN1.4
unnamed: BF6.2, CN1.3
unnamed: BF7.2, CN1.2
unnamed: BF15.2, CN2.4
unnamed: BF16.2, CN2.5
unnamed: BF17.2, CN2.6
unnamed: BF22.2, CN1.7
unnamed: BF25.2, CN2.7
unnamed: BF27.1, CN2.1
unnamed: BF28.1, CN2.8
unnamed: BF29.1, CN1.8
unnamed: BF30.1, CN1.1
unnamed: BF8.2, CN1.9
unnamed: BF9.2, CN1.10
unnamed: BF11.2, CN1.12
unnamed: BF12.2, CN1.13
unnamed: BF23.2, CN1.14
unnamed: BF21.2, CN1.15
unnamed: BF10.2, CN1.11 (P111)
unnamed: BF13.2, CN2.9
unnamed: BF14.2, CN2.10
unnamed: BF19.2, CN2.12
unnamed: BF20.2, CN2.13
unnamed: BF24.2, CN2.14
unnamed: BF26.2, CN2.15
unnamed: BF18.2, CN2.11 (P111)
unnamed: BF19.1, CR1.2 (IN1)
unnamed: BF16.1, CR1.4 (IN2)
unnamed: BF20.1, CR1.6 (IN3)
unnamed: BF17.1, CR1.8 (IN4)
unnamed: BF14.1, CR2.2 (IN1)
unnamed: BF1.1, CR2.4 (IN2)
unnamed: BF18.1, CR2.6 (IN3)
unnamed: BF15.1, CR2.8 (IN4)
unnamed: BF12.1, CR3.2 (IN1)
unnamed: BF3.1, CR3.4 (IN2)
unnamed: BF13.1, CR3.6 (IN3)
unnamed: BF2.1, CR3.8 (IN4)
unnamed: BF10.1, CR4.2 (IN1)
unnamed: BF5.1, CR4.4 (IN2)
unnamed: BF11.1, CR4.6 (IN3)
unnamed: BF4.1, CR4.8 (IN4)
unnamed: BF8.1, CR5.2 (IN1)
unnamed: BF7.1, CR5.4 (IN2)
unnamed: BF9.1, CR5.6 (IN3)
unnamed: BF6.1, CR5.8 (IN4)
unnamed: BF21.1, RN1.1 (R1.1)
unnamed: RN1.2 (R1.2), U12.2
unnamed: BF22.1, RN1.3 (R2.1)
unnamed: RN1.4 (R2.2), U12.4
unnamed: BF23.1, RN1.5 (R3.1)
unnamed: RN1.6 (R3.2), U12.6
unnamed: BF26.1, RN2.1 (R1.1)
unnamed: RN2.2 (R1.2), U12.12
unnamed: BF25.1, RN2.3 (R2.1)
unnamed: RN2.4 (R2.2), U12.10
unnamed: BF24.1, RN2.5 (R3.1)
unnamed: RN2.6 (R3.2), U12.8
OUT11: U12.5; also elsewhere on the board
OUT12: U12.3; also elsewhere on the board
OUT13: U12.1; also elsewhere on the board
OUT21: U12.9; also elsewhere on the board
OUT22: U12.11; also elsewhere on the board
OUT23: U12.13; also elsewhere on the board
VCC: BF27.2, BF30.2, CR1.1 (VCC), CR2.1 (VCC), CR3.1 (VCC), CR4.1 (VCC), CR5.1 (VCC); also elsewhere on the board

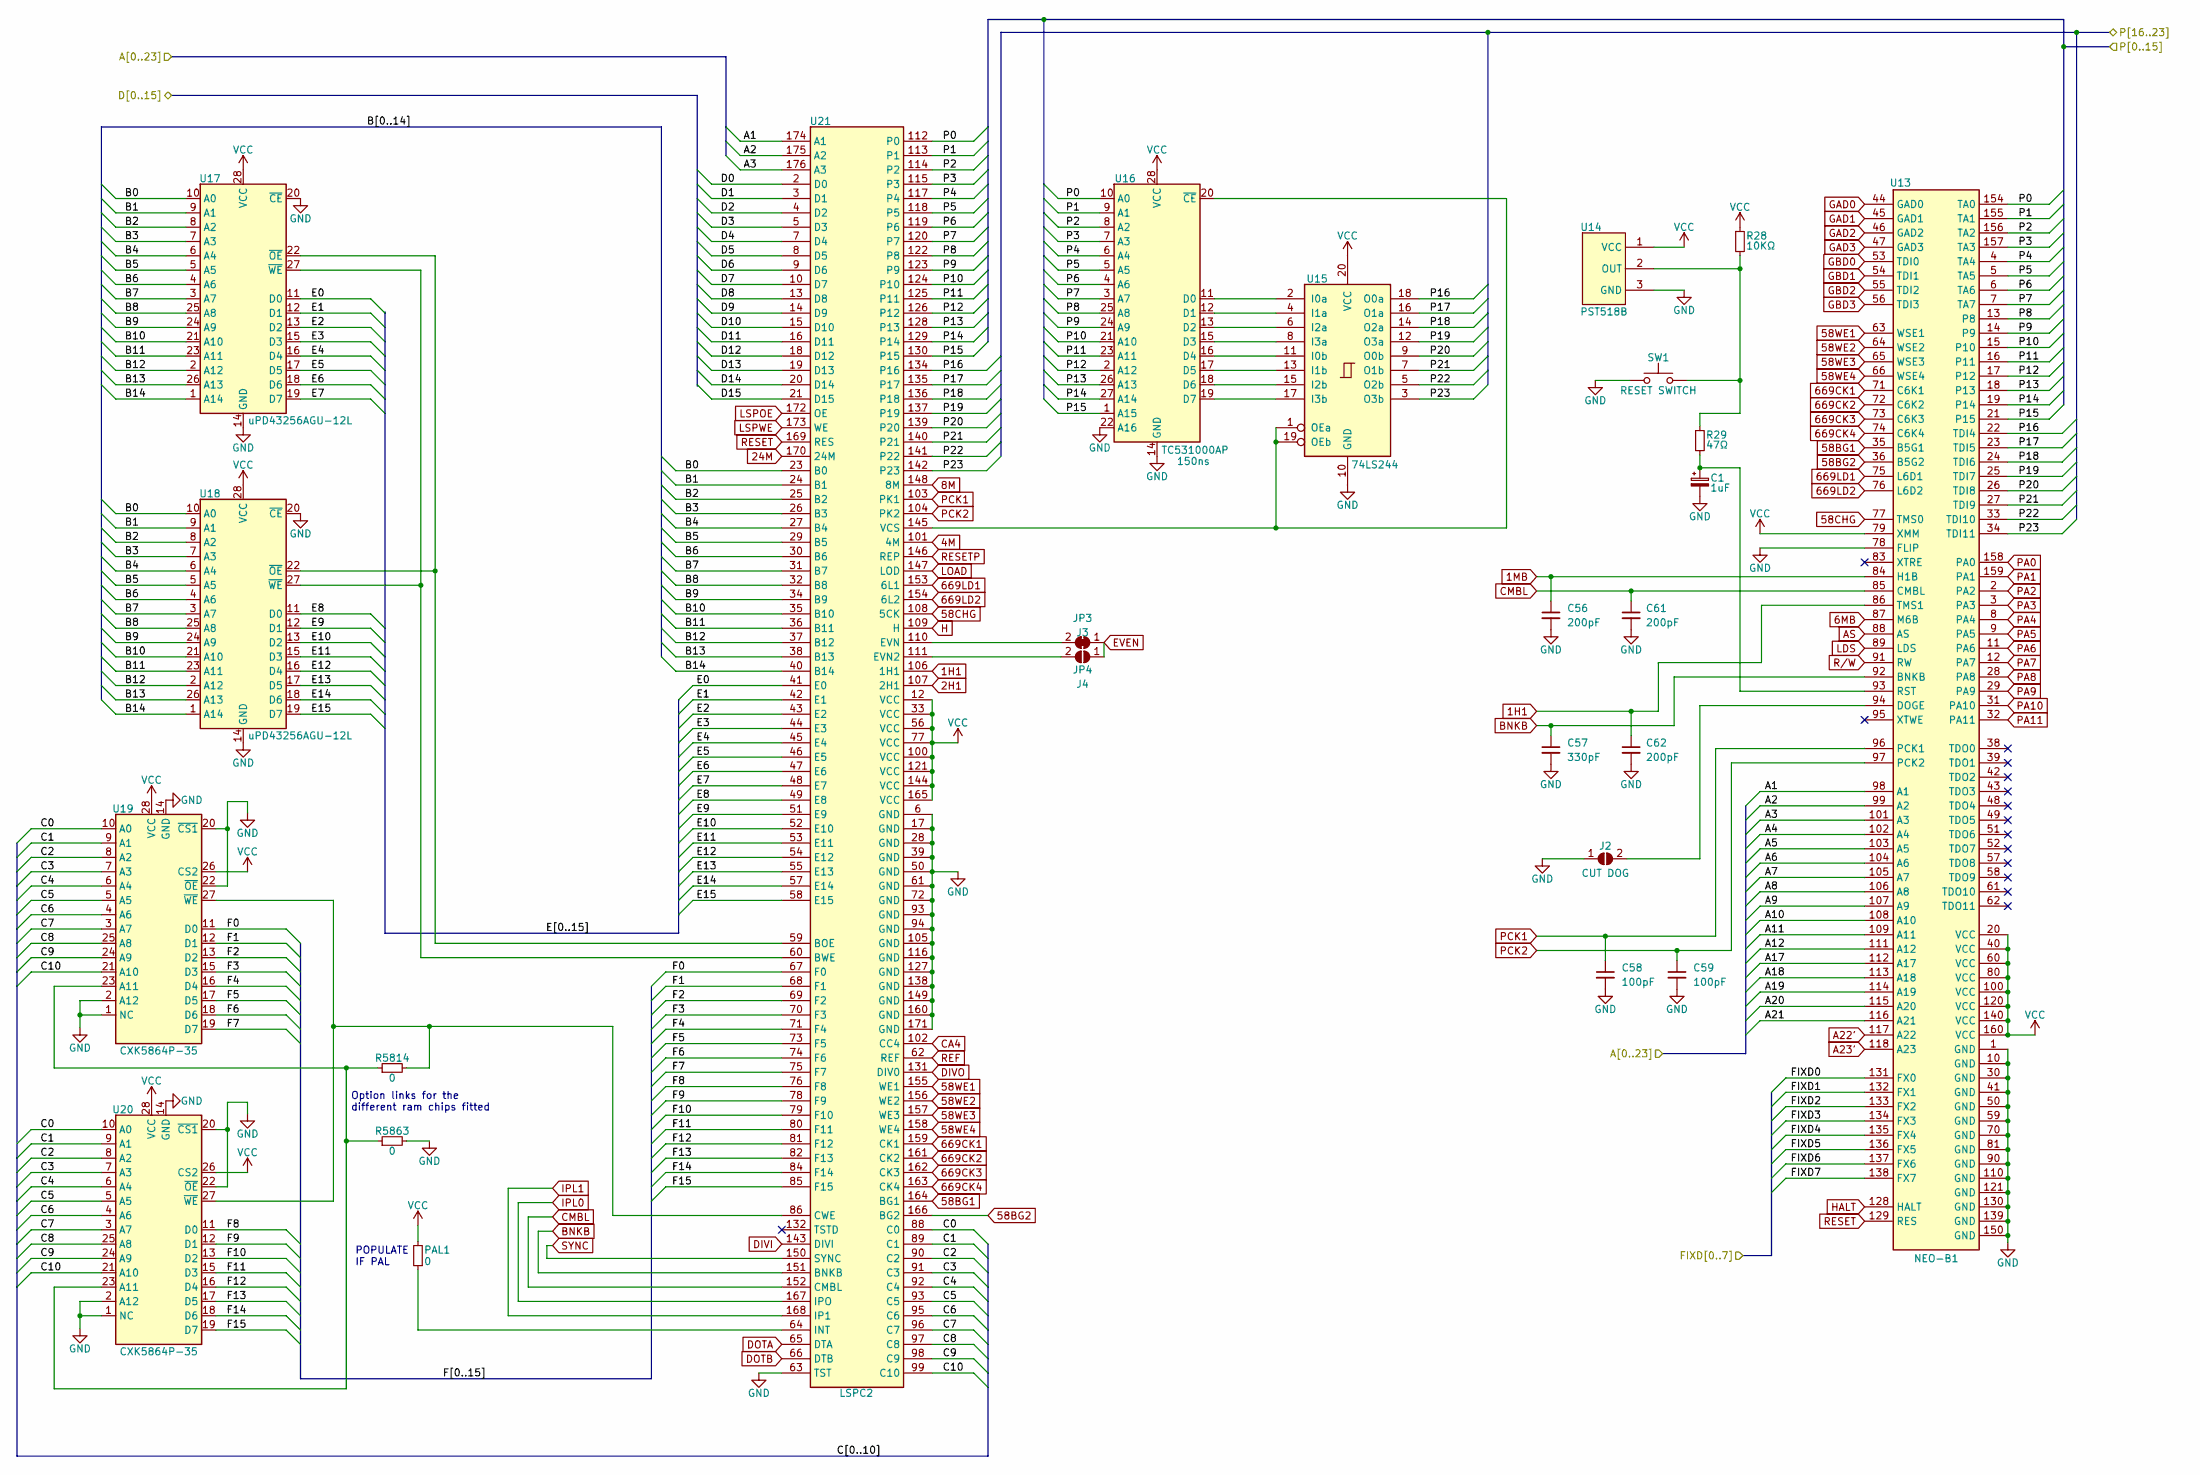
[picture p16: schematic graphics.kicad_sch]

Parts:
C1: 1uF; CAP2-2.5mm
C56, C61, C62: 200pF; CAP3-5mm
C57: 330pF; CAP3-5mm
C58, C59: 100pF; CAP3-5mm
J2: CUT DOG; J2
JP3: J3; J2
JP4: J4; J2
PAL1: 0; R_Axial_DIN0204_L3.6mm_D1.6mm_P5.08mm_Vertical
R28: 10KΩ; Resistor1-5mm
R29: 47Ω; Resistor1-5mm
R5814, R5863: 0; PAL
SW1: RESET SWITCH; SW_Tactile_Straight_KSL0Axx1LFTR
U13: NEO-B1
U14: PST518B
U15: 74LS244; DIP-20_W7.62mm
U16: TC531000AP; DIP-28_W15.24mm
U17, U18: uPD43256AGU-12L; 43256
U19, U20: CXK5864P-35; DIP-28_W7.62mm
U21: LSPC2

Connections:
1H1: C62.1, U13.86 (TMS1), U21.106 (1H1)
1MB: C56.1, U13.84 (H1B); also elsewhere on the board
2H1: U21.107 (2H1); also elsewhere on the board
4M: U21.101 (4M); also elsewhere on the board
6MB: U13.87 (M6B); also elsewhere on the board
8M: U21.148 (8M); also elsewhere on the board
24M: U21.170 (24M); also elsewhere on the board
58BG1: U13.35 (B5G1), U21.164 (BG1)
58BG2: U13.36 (B5G2), U21.166 (BG2)
58CHG: U13.77 (TMS0), U21.108 (5CK)
58WE1: U13.63 (WSE1), U21.155 (WE1)
58WE2: U13.64 (WSE2), U21.156 (WE2)
58WE3: U13.65 (WSE3), U21.157 (WE3)
58WE4: U13.66 (WSE4), U21.158 (WE4)
669CK1: U13.71 (C6K1), U21.159 (CK1)
669CK2: U13.72 (C6K2), U21.161 (CK2)
669CK3: U13.73 (C6K3), U21.162 (CK3)
669CK4: U13.74 (C6K4), U21.163 (CK4)
669LD1: U13.75 (L6D1), U21.153 (6L1)
669LD2: U13.76 (L6D2), U21.154 (6L2)
/CPU/A1: U13.98 (A1), U21.174 (A1); also elsewhere on the board
/CPU/A2: U13.99 (A2), U21.175 (A2); also elsewhere on the board
/CPU/A3: U13.101 (A3), U21.176 (A3); also elsewhere on the board
/CPU/A4: U13.102 (A4); also elsewhere on the board
/CPU/A5: U13.103 (A5); also elsewhere on the board
/CPU/A6: U13.104 (A6); also elsewhere on the board
/CPU/A7: U13.105 (A7); also elsewhere on the board
/CPU/A8: U13.106 (A8); also elsewhere on the board
/CPU/A9: U13.107 (A9); also elsewhere on the board
/CPU/A10: U13.108 (A10); also elsewhere on the board
/CPU/A11: U13.109 (A11); also elsewhere on the board
/CPU/A12: U13.111 (A12); also elsewhere on the board
/CPU/A17: U13.112 (A17); also elsewhere on the board
/CPU/A18: U13.113 (A18); also elsewhere on the board
/CPU/A19: U13.114 (A19); also elsewhere on the board
/CPU/A20: U13.115 (A20); also elsewhere on the board
/CPU/A21: U13.116 (A21); also elsewhere on the board
/CPU/D0: U21.2 (D0); also elsewhere on the board
/CPU/D1: U21.3 (D1); also elsewhere on the board
/CPU/D2: U21.4 (D2); also elsewhere on the board
/CPU/D3: U21.5 (D3); also elsewhere on the board
/CPU/D4: U21.7 (D4); also elsewhere on the board
/CPU/D5: U21.8 (D5); also elsewhere on the board
/CPU/D6: U21.9 (D6); also elsewhere on the board
/CPU/D7: U21.10 (D7); also elsewhere on the board
/CPU/D8: U21.13 (D8); also elsewhere on the board
/CPU/D9: U21.14 (D9); also elsewhere on the board
/CPU/D10: U21.15 (D10); also elsewhere on the board
/CPU/D11: U21.16 (D11); also elsewhere on the board
/CPU/D12: U21.18 (D12); also elsewhere on the board
/CPU/D13: U21.19 (D13); also elsewhere on the board
/CPU/D14: U21.20 (D14); also elsewhere on the board
/CPU/D15: U21.21 (D15); also elsewhere on the board
/Cartridge Slots/FIXD0: U13.131 (FX0); also elsewhere on the board
/Cartridge Slots/FIXD1: U13.132 (FX1); also elsewhere on the board
/Cartridge Slots/FIXD2: U13.133 (FX2); also elsewhere on the board
/Cartridge Slots/FIXD3: U13.134 (FX3); also elsewhere on the board
/Cartridge Slots/FIXD4: U13.135 (FX4); also elsewhere on the board
/Cartridge Slots/FIXD5: U13.136 (FX5); also elsewhere on the board
/Cartridge Slots/FIXD6: U13.137 (FX6); also elsewhere on the board
/Cartridge Slots/FIXD7: U13.138 (FX7); also elsewhere on the board
/Cartridge Slots/P0: U13.154 (TA0), U16.10 (A0), U21.112 (P0); also elsewhere on the board
/Cartridge Slots/P1: U13.155 (TA1), U16.9 (A1), U21.113 (P1); also elsewhere on the board
/Cartridge Slots/P2: U13.156 (TA2), U16.8 (A2), U21.114 (P2); also elsewhere on the board
/Cartridge Slots/P3: U13.157 (TA3), U16.7 (A3), U21.115 (P3); also elsewhere on the board
/Cartridge Slots/P4: U13.4 (TA4), U16.6 (A4), U21.117 (P4); also elsewhere on the board
/Cartridge Slots/P5: U13.5 (TA5), U16.5 (A5), U21.118 (P5); also elsewhere on the board
/Cartridge Slots/P6: U13.6 (TA6), U16.4 (A6), U21.119 (P6); also elsewhere on the board
/Cartridge Slots/P7: U13.7 (TA7), U16.3 (A7), U21.120 (P7); also elsewhere on the board
/Cartridge Slots/P8: U13.13 (P8), U16.25 (A8), U21.122 (P8); also elsewhere on the board
/Cartridge Slots/P9: U13.14 (P9), U16.24 (A9), U21.123 (P9); also elsewhere on the board
/Cartridge Slots/P10: U13.15 (P10), U16.21 (A10), U21.124 (P10); also elsewhere on the board
/Cartridge Slots/P11: U13.16 (P11), U16.23 (A11), U21.125 (P11); also elsewhere on the board
/Cartridge Slots/P12: U13.17 (P12), U16.2 (A12), U21.126 (P12); also elsewhere on the board
/Cartridge Slots/P13: U13.18 (P13), U16.26 (A13), U21.128 (P13); also elsewhere on the board
/Cartridge Slots/P14: U13.19 (P14), U16.27 (A14), U21.129 (P14); also elsewhere on the board
/Cartridge Slots/P15: U13.21 (P15), U16.1 (A15), U21.130 (P15); also elsewhere on the board
/Cartridge Slots/P16: U13.22 (TDI4), U15.18 (O0a), U21.134 (P16); also elsewhere on the board
/Cartridge Slots/P17: U13.23 (TDI5), U15.16 (O1a), U21.135 (P17); also elsewhere on the board
/Cartridge Slots/P18: U13.24 (TDI6), U15.14 (O2a), U21.136 (P18); also elsewhere on the board
/Cartridge Slots/P19: U13.25 (TDI7), U15.12 (O3a), U21.137 (P19); also elsewhere on the board
/Cartridge Slots/P20: U13.26 (TDI8), U15.9 (O0b), U21.139 (P20); also elsewhere on the board
/Cartridge Slots/P21: U13.27 (TDI9), U15.7 (O1b), U21.140 (P21); also elsewhere on the board
/Cartridge Slots/P22: U13.33 (TDI10), U15.5 (O2b), U21.141 (P22); also elsewhere on the board
/Cartridge Slots/P23: U13.34 (TDI11), U15.3 (O3b), U21.142 (P23); also elsewhere on the board
/GRAPHICS/B0: U17.10 (A0), U18.10 (A0), U21.23 (B0)
/GRAPHICS/B1: U17.9 (A1), U18.9 (A1), U21.24 (B1)
/GRAPHICS/B2: U17.8 (A2), U18.8 (A2), U21.25 (B2)
/GRAPHICS/B3: U17.7 (A3), U18.7 (A3), U21.26 (B3)
/GRAPHICS/B4: U17.6 (A4), U18.6 (A4), U21.27 (B4)
/GRAPHICS/B5: U17.5 (A5), U18.5 (A5), U21.29 (B5)
/GRAPHICS/B6: U17.4 (A6), U18.4 (A6), U21.30 (B6)
/GRAPHICS/B7: U17.3 (A7), U18.3 (A7), U21.31 (B7)
/GRAPHICS/B8: U17.25 (A8), U18.25 (A8), U21.32 (B8)
/GRAPHICS/B9: U17.24 (A9), U18.24 (A9), U21.34 (B9)
/GRAPHICS/B10: U17.21 (A10), U18.21 (A10), U21.35 (B10)
/GRAPHICS/B11: U17.23 (A11), U18.23 (A11), U21.36 (B11)
/GRAPHICS/B12: U17.2 (A12), U18.2 (A12), U21.37 (B12)
/GRAPHICS/B13: U17.26 (A13), U18.26 (A13), U21.38 (B13)
/GRAPHICS/B14: U17.1 (A14), U18.1 (A14), U21.40 (B14)
/GRAPHICS/C0: U19.10 (A0), U20.10 (A0), U21.88 (C0)
/GRAPHICS/C1: U19.9 (A1), U20.9 (A1), U21.89 (C1)
/GRAPHICS/C2: U19.8 (A2), U20.8 (A2), U21.90 (C2)
/GRAPHICS/C3: U19.7 (A3), U20.7 (A3), U21.91 (C3)
/GRAPHICS/C4: U19.6 (A4), U20.6 (A4), U21.92 (C4)
/GRAPHICS/C6: U19.4 (A6), U20.4 (A6), U21.95 (C6)
/GRAPHICS/C7: U19.3 (A7), U20.3 (A7), U21.96 (C7)
/GRAPHICS/C8: U19.25 (A8), U20.25 (A8), U21.97 (C8)
/GRAPHICS/C9: U19.24 (A9), U20.24 (A9), U21.98 (C9)
/GRAPHICS/C10: U19.21 (A10), U20.21 (A10), U21.99 (C10)
/GRAPHICS/E0: U17.11 (D0), U21.41 (E0)
/GRAPHICS/E1: U17.12 (D1), U21.42 (E1)
/GRAPHICS/E2: U17.13 (D2), U21.43 (E2)
/GRAPHICS/E4: U17.16 (D4), U21.45 (E4)
/GRAPHICS/E5: U17.17 (D5), U21.46 (E5)
/GRAPHICS/E6: U17.18 (D6), U21.47 (E6)
/GRAPHICS/E7: U17.19 (D7), U21.48 (E7)
/GRAPHICS/E8: U18.11 (D0), U21.49 (E8)
/GRAPHICS/E9: U18.12 (D1), U21.51 (E9)
/GRAPHICS/E10: U18.13 (D2), U21.52 (E10)
/GRAPHICS/E11: U18.15 (D3), U21.53 (E11)
/GRAPHICS/E12: U18.16 (D4), U21.54 (E12)
/GRAPHICS/E13: U18.17 (D5), U21.55 (E13)
/GRAPHICS/E14: U18.18 (D6), U21.57 (E14)
/GRAPHICS/E15: U18.19 (D7), U21.58 (E15)
/GRAPHICS/F0: U19.11 (D0), U21.67 (F0)
/GRAPHICS/F1: U19.12 (D1), U21.68 (F1)
/GRAPHICS/F2: U19.13 (D2), U21.69 (F2)
/GRAPHICS/F3: U19.15 (D3), U21.70 (F3)
/GRAPHICS/F4: U19.16 (D4), U21.71 (F4)
/GRAPHICS/F5: U19.17 (D5), U21.73 (F5)
/GRAPHICS/F6: U19.18 (D6), U21.74 (F6)
/GRAPHICS/F7: U19.19 (D7), U21.75 (F7)
/GRAPHICS/F8: U20.11 (D0), U21.76 (F8)
/GRAPHICS/F9: U20.12 (D1), U21.78 (F9)
/GRAPHICS/F10: U20.13 (D2), U21.79 (F10)
/GRAPHICS/F11: U20.15 (D3), U21.80 (F11)
/GRAPHICS/F12: U20.16 (D4), U21.81 (F12)
/GRAPHICS/F13: U20.17 (D5), U21.82 (F13)
/GRAPHICS/F14: U20.18 (D6), U21.84 (F14)
/GRAPHICS/F15: U20.19 (D7), U21.85 (F15)
A22': U13.117 (A22); also elsewhere on the board
A23': U13.118 (A23); also elsewhere on the board
AS: U13.88 (AS); also elsewhere on the board
BNKB: C57.1, U13.92 (BNKB), U21.151 (BNKB); also elsewhere on the board
CA4: U21.102 (CC4); also elsewhere on the board
CMBL: C61.1, U13.85 (CMBL), U21.152 (CMBL)
DIVI: U21.143 (DIVI); also elsewhere on the board
DIVO: U21.131 (DIV0); also elsewhere on the board
DOTA: U21.65 (DTA); also elsewhere on the board
DOTB: U21.66 (DTB); also elsewhere on the board
GAD0: U13.44 (GAD0); also elsewhere on the board
GAD1: U13.45 (GAD1); also elsewhere on the board
GAD2: U13.46 (GAD2); also elsewhere on the board
GAD3: U13.47 (GAD3); also elsewhere on the board
GBD0: U13.53 (TDI0); also elsewhere on the board
GBD1: U13.54 (TDI1); also elsewhere on the board
GBD2: U13.55 (TDI2); also elsewhere on the board
GBD3: U13.56 (TDI3); also elsewhere on the board
H: U21.109 (H); also elsewhere on the board
HALT: U13.128 (HALT); also elsewhere on the board
IPL0: U21.167 (IPO); also elsewhere on the board
IPL1: U21.168 (IP1); also elsewhere on the board
LDS: U13.89 (LDS); also elsewhere on the board
LOAD: U21.147 (LOD); also elsewhere on the board
LSPOE: U21.172 (OE); also elsewhere on the board
LSPWE: U21.173 (WE); also elsewhere on the board
unnamed: J2.2 (B), U13.94 (DOGE)
unnamed: JP3.2 (B), U21.110 (EVN)
unnamed: JP4.2 (B), U21.111 (EVN2)
unnamed: C1.1, R29.2, U13.93 (RST)
unnamed: R28.2, R29.1, SW1.2, U14.2 (OUT)
unnamed: U15.2 (I0a), U16.11 (D0)
unnamed: U15.11 (I0b), U16.16 (D4)
unnamed: U15.4 (I1a), U16.12 (D1)
unnamed: U15.13 (I1b), U16.17 (D5)
unnamed: U15.6 (I2a), U16.13 (D2)
unnamed: U15.15 (I2b), U16.18 (D6)
unnamed: U15.8 (I3a), U16.15 (D3)
unnamed: U15.17 (I3b), U16.19 (D7)
unnamed: U15.1 (OEa), U15.19 (OEb), U16.20 (~CE), U21.145 (VCS)
unnamed: U17.22 (~OE), U18.22 (~OE), U21.59 (BOE)
unnamed: U17.27 (~WE), U18.27 (~WE), U21.60 (BWE)
unnamed: R5814.1, R5863.1, U19.23 (A11), U20.23 (A11)
unnamed: R5814.2, U19.27 (~WE), U20.27 (~WE), U21.86 (CWE)
unnamed: PAL1.1, U21.64 (INT)
PA0: U13.158 (PA0); also elsewhere on the board
PA1: U13.159 (PA1); also elsewhere on the board
PA2: U13.2 (PA2); also elsewhere on the board
PA3: U13.3 (PA3); also elsewhere on the board
PA4: U13.8 (PA4); also elsewhere on the board
PA5: U13.9 (PA5); also elsewhere on the board
PA6: U13.11 (PA6); also elsewhere on the board
PA7: U13.12 (PA7); also elsewhere on the board
PA8: U13.28 (PA8); also elsewhere on the board
PA9: U13.29 (PA9); also elsewhere on the board
PA10: U13.31 (PA10); also elsewhere on the board
PA11: U13.32 (PA11); also elsewhere on the board
PCK1: C58.1, U13.96 (PCK1), U21.103 (PK1); also elsewhere on the board
PCK2: C59.1, U13.97 (PCK2), U21.104 (PK2); also elsewhere on the board
REF: U21.62 (REF); also elsewhere on the board
RESET: U13.129 (RES), U21.169 (RES); also elsewhere on the board
RESETP: U21.146 (REP); also elsewhere on the board
R/W: U13.91 (RW); also elsewhere on the board
SYNC: U21.150 (SYNC); also elsewhere on the board
VCC: PAL1.2, R28.1, U13.20 (VCC), U13.40 (VCC), U13.60 (VCC), U13.79 (XMM), U13.80 (VCC), U13.100 (VCC), U13.120 (VCC), U13.140 (VCC), U13.160 (VCC), U14.1 (VCC), U15.20 (VCC), U16.28 (VCC), U17.28 (VCC), U18.28 (VCC), U19.26 (CS2), U19.28 (VCC), U20.26 (CS2), U20.28 (VCC), U21.12 (VCC), U21.33 (VCC), U21.56 (VCC), U21.77 (VCC), U21.100 (VCC), U21.121 (VCC), U21.144 (VCC), U21.165 (VCC); also elsewhere on the board

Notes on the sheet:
POPULATE IF PAL
Option links for the different ram chips fitted

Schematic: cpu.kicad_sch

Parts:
J1: BEER; J2
RA1: 4.7KΩ; R_Array_SIP5
U1, U2: uPD43256AGU-12L; 43256
U3: HD68HC000P; 68000
U4: NEO-C1

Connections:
68KCLK: U3.15 (CLK), U4.36 (6CLK); also elsewhere on the board
/CONTROLLER/IN0: U4.42 (IN00); also elsewhere on the board
/CONTROLLER/IN1: U4.43 (IN01); also elsewhere on the board
/CONTROLLER/IN2: U4.44 (IN02); also elsewhere on the board
/CONTROLLER/IN3: U4.45 (IN03); also elsewhere on the board
/CONTROLLER/IN4: U4.46 (IN04); also elsewhere on the board
/CONTROLLER/IN5: U4.47 (IN05); also elsewhere on the board
/CONTROLLER/IN6: U4.48 (IN06); also elsewhere on the board
/CONTROLLER/IN7: U4.59 (IN07); also elsewhere on the board
/CONTROLLER/IN10: U4.60 (IN10); also elsewhere on the board
/CONTROLLER/IN11: U4.61 (IN11); also elsewhere on the board
/CONTROLLER/IN12: U4.62 (IN12); also elsewhere on the board
/CONTROLLER/IN13: U4.63 (IN13); also elsewhere on the board
/CONTROLLER/IN14: U4.64 (IN14); also elsewhere on the board
/CONTROLLER/IN15: U4.66 (IN15); also elsewhere on the board
/CONTROLLER/IN16: U4.67 (IN16); also elsewhere on the board
/CONTROLLER/IN17: U4.68 (IN17); also elsewhere on the board
/CONTROLLER/IN20: U4.69 (IN20); also elsewhere on the board
/CONTROLLER/IN21: U4.70 (IN21); also elsewhere on the board
/CONTROLLER/IN22: U4.71 (IN22); also elsewhere on the board
/CONTROLLER/IN23: U4.72 (IN23); also elsewhere on the board
/CPU/A1: U1.10 (A0), U2.10 (A0), U3.29 (A1); also elsewhere on the board
/CPU/A2: U1.9 (A1), U2.9 (A1), U3.30 (A2); also elsewhere on the board
/CPU/A3: U1.8 (A2), U2.8 (A2), U3.31 (A3); also elsewhere on the board
/CPU/A4: U1.7 (A3), U2.7 (A3), U3.32 (A4); also elsewhere on the board
/CPU/A5: U1.6 (A4), U2.6 (A4), U3.33 (A5); also elsewhere on the board
/CPU/A6: U1.5 (A5), U2.5 (A5), U3.34 (A6); also elsewhere on the board
/CPU/A7: U1.4 (A6), U2.4 (A6), U3.35 (A7); also elsewhere on the board
/CPU/A8: U1.3 (A7), U2.3 (A7), U3.36 (A8); also elsewhere on the board
/CPU/A9: U1.25 (A8), U2.25 (A8), U3.37 (A9); also elsewhere on the board
/CPU/A10: U1.24 (A9), U2.24 (A9), U3.38 (A10); also elsewhere on the board
/CPU/A11: U1.21 (A10), U2.21 (A10), U3.39 (A11); also elsewhere on the board
/CPU/A12: U1.23 (A11), U2.23 (A11), U3.40 (A12); also elsewhere on the board
/CPU/A13: U1.2 (A12), U2.2 (A12), U3.41 (A13); also elsewhere on the board
/CPU/A14: U1.26 (A13), U2.26 (A13), U3.42 (A14); also elsewhere on the board
/CPU/A15: U1.1 (A14), U2.1 (A14), U3.43 (A15); also elsewhere on the board
/CPU/A16: U3.44 (A16); also elsewhere on the board
/CPU/A17: U3.45 (A17), U4.20 (A17); also elsewhere on the board
/CPU/A18: U3.46 (A18), U4.21 (A18); also elsewhere on the board
/CPU/A19: U3.47 (A19), U4.22 (A19); also elsewhere on the board
/CPU/A20: U3.48 (A20), U4.23 (A20); also elsewhere on the board
/CPU/A21: U3.50 (A21), U4.24 (A21); also elsewhere on the board
/CPU/A22: U3.51 (A22); also elsewhere on the board
/CPU/A23: U3.52 (A23); also elsewhere on the board
/CPU/D0: U1.11 (D0), U3.5 (D0); also elsewhere on the board
/CPU/D1: U1.12 (D1), U3.4 (D1); also elsewhere on the board
/CPU/D2: U1.13 (D2), U3.3 (D2); also elsewhere on the board
/CPU/D3: U1.15 (D3), U3.2 (D3); also elsewhere on the board
/CPU/D4: U1.16 (D4), U3.1 (D4); also elsewhere on the board
/CPU/D5: U1.17 (D5), U3.64 (D5); also elsewhere on the board
/CPU/D6: U1.18 (D6), U3.63 (D6); also elsewhere on the board
/CPU/D7: U1.19 (D7), U3.62 (D7); also elsewhere on the board
/CPU/D8: U2.11 (D0), U3.61 (D8), U4.49 (D8); also elsewhere on the board
/CPU/D9: U2.12 (D1), U3.60 (D9), U4.50 (D9); also elsewhere on the board
/CPU/D10: U2.13 (D2), U3.59 (D10), U4.51 (D10); also elsewhere on the board
/CPU/D11: U2.15 (D3), U3.58 (D11), U4.52 (D11); also elsewhere on the board
/CPU/D12: U2.16 (D4), U3.57 (D12), U4.55 (D12); also elsewhere on the board
/CPU/D13: U2.17 (D5), U3.56 (D13), U4.56 (D13); also elsewhere on the board
/CPU/D14: U2.18 (D6), U3.55 (D14), U4.57 (D14); also elsewhere on the board
/CPU/D15: U2.19 (D7), U3.54 (D15), U4.58 (D15); also elsewhere on the board
/CPU/SDD0: U4.74 (SD0); also elsewhere on the board
/CPU/SDD1: U4.75 (SD1); also elsewhere on the board
/CPU/SDD2: U4.76 (SD2); also elsewhere on the board
/CPU/SDD3: U4.77 (SD3); also elsewhere on the board
/CPU/SDD6: U4.82 (SD6); also elsewhere on the board
/CPU/SDD7: U4.83 (SD7); also elsewhere on the board
A22': U4.25 (A22); also elsewhere on the board
A23': U4.26 (A23); also elsewhere on the board
AS: U3.6 (AS), U4.35 (AS); also elsewhere on the board
BITW0: U4.99 (BTW0); also elsewhere on the board
CARDCS: U4.27 (CRDC); also elsewhere on the board
CD1: U4.73 (IN24); also elsewhere on the board
CD2: U4.87 (IN25); also elsewhere on the board
HALT: RA1.3 (R2), U3.17 (HALT); also elsewhere on the board
IPL0: U3.25 (IPL0); also elsewhere on the board
IPL1: U3.24 (IPL1); also elsewhere on the board
LDS: U3.8 (LDS), U4.34 (LDS); also elsewhere on the board
LSPOE: U4.8 (LSPO); also elsewhere on the board
LSPWE: U4.9 (LSPW); also elsewhere on the board
unnamed: J1.2 (B), RA1.5 (R4), U3.22 (BERR)
unnamed: RA1.2 (R1), U3.12 (BGACK), U3.13 (BR), U3.23 (IPL2)
unnamed: U1.22 (~OE), U4.92 (RAOL)
unnamed: U1.27 (~WE), U4.93 (RAWL)
unnamed: U2.22 (~OE), U4.6 (RAOU)
unnamed: U2.27 (~WE), U4.7 (RAWU)
unnamed: U3.10 (DTACK), U4.19 (DTCK)
unnamed: U3.7 (UDS), U4.33 (UDS)
unnamed: U3.21 (VPA), U4.17 (VPA)
PAL: U4.16 (PAL); also elsewhere on the board
PDTACK: U4.41 (PDTK); also elsewhere on the board
PORTADRS: U4.18 (PADR); also elsewhere on the board
PORTOEL: U4.94 (PTOL); also elsewhere on the board
PORTOEU: U4.10 (PTOU); also elsewhere on the board
PORTWEL: U4.95 (PTWL); also elsewhere on the board
PORTWEU: U4.11 (PTWU); also elsewhere on the board
PWAIT0: U4.38 (PWT0); also elsewhere on the board
PWAIT1: U4.39 (PWT1); also elsewhere on the board
RESET: RA1.4 (R3), U3.18 (RESET); also elsewhere on the board
ROMOEL: U4.91 (ROOL); also elsewhere on the board
ROMOEU: U4.5 (ROOU); also elsewhere on the board
ROMWAIT: U4.37 (RWAT); also elsewhere on the board
R/W: U3.9 (R/W), U4.32 (RW); also elsewhere on the board
SDW: U4.29 (SDW)
SDZ80CLR: U4.86 (SDZC); also elsewhere on the board
SDZ80R: U4.84 (SDZR); also elsewhere on the board
SDZ80W: U4.85 (SDZW); also elsewhere on the board
SROMOEL: U4.96 (SOOL); also elsewhere on the board
SROMOEU: U4.12 (SOOU); also elsewhere on the board
VCC: RA1.1 (common), U1.28 (VCC), U2.28 (VCC), U3.14 (VCC), U3.49 (VCC), U4.3 (VCC), U4.28 (VCC), U4.53 (VCC), U4.78 (VCC); also elsewhere on the board
WP: U4.88 (IN26); also elsewhere on the board

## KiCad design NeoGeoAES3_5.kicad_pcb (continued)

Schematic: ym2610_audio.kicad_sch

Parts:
BF301, BF302, BF303: ZBF253D; BF-2.5mm
C2, C4, C5, C6, C7, C8, C11, C12, C20, C24, C25, C301: 10uF; CAP2-2.5mm
C3: 68pF; CAP3-5mm
C9, C10: 470uF; CAP1-5mm
C13, C14: 0.0022uF; CAP3-5mm
C22, C23: 10uF; CAP3-5mm
J3: SMK S-G8043; J3
Q101, Q102: 2SC1815; Transistor
R31, R39, R40, R41, R42: 4.7KΩ; Resistor1-5mm
R32, R36, R37, R38, R43, R45, R301: 1KΩ; Resistor1-5mm
R33, R34: 10Ω; R_Axial_DIN0207_L6.3mm_D2.5mm_P10.16mm_Horizontal
R46, R49: 27KΩ; Resistor1-5mm
R47, R48: 47KΩ; Resistor1-5mm
R302: 30KΩ; Resistor1-5mm
R303: 10KΩ; Resistor1-5mm
R401, R501: 75Ω; Resistor1-5mm
R402, R502: 51KΩ; Resistor1-5mm
R403, R503: 15KΩ; Resistor1-5mm
RV1: Headphone Slider; Volume-Slider
U26: YM3016D; DIP-16_W7.62mm
U27: YM2610; 68000
U28, U29: PC4741; DIP-14_W7.62mm

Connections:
8M: U27.63 (CLK); also elsewhere on the board
2610CS: U27.57 (~CS); also elsewhere on the board
2610RD: U27.59 (~RD); also elsewhere on the board
2610WR: U27.58 (~WR); also elsewhere on the board
/CPU/SDD0: U27.2 (D0); also elsewhere on the board
/CPU/SDD1: U27.3 (D1); also elsewhere on the board
/CPU/SDD2: U27.4 (D2); also elsewhere on the board
/CPU/SDD3: U27.5 (D3); also elsewhere on the board
/CPU/SDD4: U27.6 (D4); also elsewhere on the board
/CPU/SDD5: U27.7 (D5); also elsewhere on the board
/CPU/SDD6: U27.8 (D6); also elsewhere on the board
/CPU/SDD7: U27.9 (D7); also elsewhere on the board
/Cartridge Slots/SDA0: U27.60 (A0); also elsewhere on the board
/Cartridge Slots/SDA1: U27.61 (A1); also elsewhere on the board
/Cartridge Slots/SDPAD0: U27.48 (PAD0); also elsewhere on the board
/Cartridge Slots/SDPAD1: U27.49 (PAD1); also elsewhere on the board
/Cartridge Slots/SDPAD2: U27.50 (PAD2); also elsewhere on the board
/Cartridge Slots/SDPAD3: U27.51 (PAD3); also elsewhere on the board
/Cartridge Slots/SDPAD4: U27.52 (PAD4); also elsewhere on the board
/Cartridge Slots/SDPAD5: U27.53 (PAD5); also elsewhere on the board
/Cartridge Slots/SDPAD6: U27.54 (PAD6); also elsewhere on the board
/Cartridge Slots/SDPAD7: U27.55 (PAD7); also elsewhere on the board
/Cartridge Slots/SDRAD0: U27.17 (RAD0); also elsewhere on the board
/Cartridge Slots/SDRAD1: U27.16 (RAD1); also elsewhere on the board
/Cartridge Slots/SDRAD2: U27.15 (RAD2); also elsewhere on the board
/Cartridge Slots/SDRAD3: U27.14 (RAD3); also elsewhere on the board
/Cartridge Slots/SDRAD4: U27.13 (RAD4); also elsewhere on the board
/Cartridge Slots/SDRAD5: U27.12 (RAD5); also elsewhere on the board
/Cartridge Slots/SDRAD6: U27.11 (RAD6); also elsewhere on the board
/Cartridge Slots/SDRAD7: U27.10 (RAD7); also elsewhere on the board
AUDIOL: C23.2, C25.1, R41.1, R42.2
AUDIOMONO: R302.1, U29.8; also elsewhere on the board
AUDIOR: C22.1, C24.1, R39.1, R40.2
unnamed: BF301.1, R34.2
unnamed: BF301.2, J3.T
unnamed: BF302.1, R33.2
unnamed: BF302.2, J3.R
unnamed: BF303.1, J3.S
unnamed: C7.1, R403.1
unnamed: C8.1, R503.1
unnamed: C9.2, R34.1
unnamed: C10.2, R33.1
unnamed: C11.2, RV1.2
unnamed: C12.2, RV1.5
unnamed: C20.1, R303.2
unnamed: C24.2, RV1.1
unnamed: C25.2, RV1.6
unnamed: Q101.3 (B), R45.2
unnamed: C9.1, Q101.1 (E), R401.1, R402.1
unnamed: Q102.3 (B), R43.2
unnamed: C10.1, Q102.1 (E), R501.1, R502.1
unnamed: R43.1, U29.1
unnamed: R45.1, U29.7
unnamed: C13.2, C14.2, R301.1, U26.14 (MP), U26.15 (BC), U28.1, U28.2 (-)
unnamed: C14.1, U26.10 (CH1), U28.10 (+)
unnamed: C13.1, U26.11 (CH2), U28.12 (+)
unnamed: U26.5 (CLK), U27.64 (CLKS)
unnamed: U26.12 (COM), U28.6 (-), U28.7
unnamed: C2.1, U26.16 (RB), U28.3 (+)
unnamed: U26.4 (SD), U27.31 (OPO)
unnamed: U26.8 (SMP1), U27.29 (SH1)
unnamed: U26.7 (SMP2), U27.30 (SH2)
unnamed: C3.1, U26.13 (TOBUF), U28.5 (+)
unnamed: C301.2, R32.2, U27.27 (AOUT)
unnamed: R36.1, R42.1, U28.8, U28.9 (-)
unnamed: R37.1, R40.1, U28.13 (-), U28.14
unnamed: C11.1, R48.1, R49.2, U29.3 (+)
unnamed: R502.2, R503.2, U29.2 (-)
unnamed: C12.1, R46.2, R47.2, U29.5 (+)
unnamed: R402.2, R403.2, U29.6 (-)
unnamed: R36.2, R37.2, R38.2, U29.10 (+)
unnamed: R302.2, R303.1, U29.9 (-)
unnamed: C301.1, R301.2, U29.12 (+)
unnamed: R38.1, R39.2, R41.2, U29.13 (-), U29.14
RESET: U27.33 (~IC); also elsewhere on the board
SDPA8: U27.41 (PA8); also elsewhere on the board
SDPA9: U27.42 (PA9); also elsewhere on the board
SDPA10: U27.43 (PA10); also elsewhere on the board
SDPA11: U27.44 (PA11); also elsewhere on the board
SDPMPX: U27.47 (PMPX); also elsewhere on the board
SDPOE: U27.46 (POE); also elsewhere on the board
SDRA8: U27.23 (RA9); also elsewhere on the board
SDRA9: U27.22 (RA8); also elsewhere on the board
SDRA20: U27.35 (RA20); also elsewhere on the board
SDRA21: U27.36 (RA21); also elsewhere on the board
SDRA22: U27.37 (RA22); also elsewhere on the board
SDRA23: U27.38 (RA23); also elsewhere on the board
SDRMPX: U27.20 (RMPX); also elsewhere on the board
SDROE: U27.21 (ROE); also elsewhere on the board
VCC: C4.1, C5.1, C6.1, Q101.2 (C), Q102.2 (C), R31.1, R47.1, R48.2, U26.1 (VCC), U26.3 (VDD), U26.6 (FORM), U26.9 (ICL), U27.19 (VCC), U27.28 (AVCC), U27.40 (~TEST), U27.62 (VCC); also elsewhere on the board
Z80INT: R31.2, U27.56 (~IRQ); also elsewhere on the board

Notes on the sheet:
Right
Left

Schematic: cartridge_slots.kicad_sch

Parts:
CN4, CN5: AXC90020; CN4-5
U33: 74AS04; DIP-14_W7.62mm

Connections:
2H1: CN4.a6; also elsewhere on the board
4M: U33.5; also elsewhere on the board
8M: U33.1; also elsewhere on the board
12M: CN4.a5; also elsewhere on the board
24M: CN4.a48; also elsewhere on the board
68KCLKB: CN5.a32; also elsewhere on the board
/CPU/A1: CN5.b3; also elsewhere on the board
/CPU/A2: CN5.b4; also elsewhere on the board
/CPU/A3: CN5.b5; also elsewhere on the board
/CPU/A4: CN5.b6; also elsewhere on the board
/CPU/A5: CN5.b7; also elsewhere on the board
/CPU/A6: CN5.b8; also elsewhere on the board
/CPU/A7: CN5.b9; also elsewhere on the board
/CPU/A8: CN5.b10; also elsewhere on the board
/CPU/A9: CN5.b11; also elsewhere on the board
/CPU/A10: CN5.b12; also elsewhere on the board
/CPU/A11: CN5.b13; also elsewhere on the board
/CPU/A12: CN5.b14; also elsewhere on the board
/CPU/A13: CN5.b15; also elsewhere on the board
/CPU/A14: CN5.b16; also elsewhere on the board
/CPU/A15: CN5.b17; also elsewhere on the board
/CPU/A16: CN5.b18; also elsewhere on the board
/CPU/A17: CN5.b19; also elsewhere on the board
/CPU/A18: CN5.b20; also elsewhere on the board
/CPU/A19: CN5.b21; also elsewhere on the board
/CPU/D0: CN5.a3; also elsewhere on the board
/CPU/D1: CN5.a4; also elsewhere on the board
/CPU/D2: CN5.a5; also elsewhere on the board
/CPU/D3: CN5.a6; also elsewhere on the board
/CPU/D4: CN5.a7; also elsewhere on the board
/CPU/D5: CN5.a8; also elsewhere on the board
/CPU/D6: CN5.a9; also elsewhere on the board
/CPU/D7: CN5.a10; also elsewhere on the board
/CPU/D8: CN5.a11; also elsewhere on the board
/CPU/D9: CN5.a12; also elsewhere on the board
/CPU/D10: CN5.a13; also elsewhere on the board
/CPU/D11: CN5.a14; also elsewhere on the board
/CPU/D12: CN5.a15; also elsewhere on the board
/CPU/D13: CN5.a16; also elsewhere on the board
/CPU/D14: CN5.a17; also elsewhere on the board
/CPU/D15: CN5.a18; also elsewhere on the board
/CPU/SDD0: CN4.b40; also elsewhere on the board
/CPU/SDD1: CN4.b41; also elsewhere on the board
/CPU/SDD2: CN4.b42; also elsewhere on the board
/CPU/SDD3: CN4.b43; also elsewhere on the board
/CPU/SDD4: CN4.b44; also elsewhere on the board
/CPU/SDD5: CN4.b45; also elsewhere on the board
/CPU/SDD6: CN4.b46; also elsewhere on the board
/CPU/SDD7: CN4.b47; also elsewhere on the board
/Cartridge Slots/FIXD0: CN4.b3; also elsewhere on the board
/Cartridge Slots/FIXD1: CN4.b4; also elsewhere on the board
/Cartridge Slots/FIXD2: CN4.b5; also elsewhere on the board
/Cartridge Slots/FIXD3: CN4.b6; also elsewhere on the board
/Cartridge Slots/FIXD4: CN4.b7; also elsewhere on the board
/Cartridge Slots/FIXD5: CN4.b8; also elsewhere on the board
/Cartridge Slots/FIXD6: CN4.b9; also elsewhere on the board
/Cartridge Slots/FIXD7: CN4.b10; also elsewhere on the board
/Cartridge Slots/P0: CN4.a11; also elsewhere on the board
/Cartridge Slots/P1: CN4.b11; also elsewhere on the board
/Cartridge Slots/P2: CN4.a12; also elsewhere on the board
/Cartridge Slots/P3: CN4.b12; also elsewhere on the board
/Cartridge Slots/P4: CN4.a13; also elsewhere on the board
/Cartridge Slots/P5: CN4.b13; also elsewhere on the board
/Cartridge Slots/P6: CN4.a14; also elsewhere on the board
/Cartridge Slots/P7: CN4.b14; also elsewhere on the board
/Cartridge Slots/P8: CN4.a15; also elsewhere on the board
/Cartridge Slots/P9: CN4.b15; also elsewhere on the board
/Cartridge Slots/P10: CN4.a16; also elsewhere on the board
/Cartridge Slots/P11: CN4.b16; also elsewhere on the board
/Cartridge Slots/P12: CN4.a17; also elsewhere on the board
/Cartridge Slots/P13: CN4.b17; also elsewhere on the board
/Cartridge Slots/P14: CN4.a18; also elsewhere on the board
/Cartridge Slots/P15: CN4.b18; also elsewhere on the board
/Cartridge Slots/P16: CN4.a19; also elsewhere on the board
/Cartridge Slots/P17: CN4.b19; also elsewhere on the board
/Cartridge Slots/P18: CN4.a20; also elsewhere on the board
/Cartridge Slots/P19: CN4.b20; also elsewhere on the board
/Cartridge Slots/P20: CN4.a21; also elsewhere on the board
/Cartridge Slots/P21: CN4.b21; also elsewhere on the board
/Cartridge Slots/P22: CN4.a22; also elsewhere on the board
/Cartridge Slots/P23: CN4.b22; also elsewhere on the board
/Cartridge Slots/SDA0: CN4.a30; also elsewhere on the board
/Cartridge Slots/SDA1: CN4.a31; also elsewhere on the board
/Cartridge Slots/SDA2: CN4.a32; also elsewhere on the board
/Cartridge Slots/SDA3: CN4.a33; also elsewhere on the board
/Cartridge Slots/SDA4: CN4.a34; also elsewhere on the board
/Cartridge Slots/SDA5: CN4.a35; also elsewhere on the board
/Cartridge Slots/SDA6: CN4.a36; also elsewhere on the board
/Cartridge Slots/SDA7: CN4.a37; also elsewhere on the board
/Cartridge Slots/SDA8: CN4.a38; also elsewhere on the board
/Cartridge Slots/SDA9: CN4.a39; also elsewhere on the board
/Cartridge Slots/SDA10: CN4.a40; also elsewhere on the board
/Cartridge Slots/SDA11: CN4.a41; also elsewhere on the board
/Cartridge Slots/SDA12: CN4.a42; also elsewhere on the board
/Cartridge Slots/SDA13: CN4.a43; also elsewhere on the board
/Cartridge Slots/SDA14: CN4.a44; also elsewhere on the board
/Cartridge Slots/SDA15: CN4.a45; also elsewhere on the board
/Cartridge Slots/SDPAD0: CN5.a34; also elsewhere on the board
/Cartridge Slots/SDPAD1: CN5.a35; also elsewhere on the board
/Cartridge Slots/SDPAD2: CN5.a36; also elsewhere on the board
/Cartridge Slots/SDPAD3: CN5.a37; also elsewhere on the board
/Cartridge Slots/SDPAD4: CN5.a38; also elsewhere on the board
/Cartridge Slots/SDPAD5: CN5.a39; also elsewhere on the board
/Cartridge Slots/SDPAD6: CN5.a40; also elsewhere on the board
/Cartridge Slots/SDPAD7: CN5.a41; also elsewhere on the board
/Cartridge Slots/SDRAD0: CN5.b32; also elsewhere on the board
/Cartridge Slots/SDRAD1: CN5.b33; also elsewhere on the board
/Cartridge Slots/SDRAD2: CN5.b34; also elsewhere on the board
/Cartridge Slots/SDRAD3: CN5.b35; also elsewhere on the board
/Cartridge Slots/SDRAD4: CN5.b36; also elsewhere on the board
/Cartridge Slots/SDRAD5: CN5.b37; also elsewhere on the board
/Cartridge Slots/SDRAD6: CN5.b38; also elsewhere on the board
/Cartridge Slots/SDRAD7: CN5.b39; also elsewhere on the board
AS: CN5.a20; also elsewhere on the board
CA4: CN4.a10; also elsewhere on the board
DOTA: CN4.b30; also elsewhere on the board
DOTB: CN4.b31; also elsewhere on the board
EVEN: CN4.a7
GAD0: CN4.b32; also elsewhere on the board
GAD1: CN4.b33; also elsewhere on the board
GAD2: CN4.b34; also elsewhere on the board
GAD3: CN4.b35; also elsewhere on the board
GBD0: CN4.b36; also elsewhere on the board
GBD1: CN4.b37; also elsewhere on the board
GBD2: CN4.b38; also elsewhere on the board
GBD3: CN4.b39; also elsewhere on the board
H: CN4.a8; also elsewhere on the board
LOAD: CN4.a9; also elsewhere on the board
unnamed: CN4.a3, U33.8
unnamed: CN4.a4, U33.10
unnamed: CN4.b48, U33.4
unnamed: CN5.b48, U33.6
unnamed: U33.2, U33.3
PCK1: U33.9; also elsewhere on the board
PCK2: U33.11; also elsewhere on the board
PDTACK: CN5.b29; also elsewhere on the board
PORTADRS: CN5.a48; also elsewhere on the board
PORTOEL: CN5.a29; also elsewhere on the board
PORTOEU: CN5.a28; also elsewhere on the board
PORTWEL: CN5.a31; also elsewhere on the board
PORTWEU: CN5.a30; also elsewhere on the board
PWAIT0: CN5.b30; also elsewhere on the board
PWAIT1: CN5.b31; also elsewhere on the board
RESET: CN5.a33; also elsewhere on the board
ROMOE: CN5.b22; also elsewhere on the board
ROMOEL: CN5.a22; also elsewhere on the board
ROMOEU: CN5.a21; also elsewhere on the board
ROMWAIT: CN5.b28; also elsewhere on the board
R/W: CN5.a19; also elsewhere on the board
SDMRD: CN4.a46; also elsewhere on the board
SDPA8: CN5.a42; also elsewhere on the board
SDPA9: CN5.a43; also elsewhere on the board
SDPA10: CN5.a44; also elsewhere on the board
SDPA11: CN5.a45; also elsewhere on the board
SDPMPX: CN5.a46; also elsewhere on the board
SDPOE: CN5.a47; also elsewhere on the board
SDRA8: CN5.b40; also elsewhere on the board
SDRA9: CN5.b41; also elsewhere on the board
SDRA20: CN5.b42; also elsewhere on the board
SDRA21: CN5.b43; also elsewhere on the board
SDRA22: CN5.b44; also elsewhere on the board
SDRA23: CN5.b45; also elsewhere on the board
SDRD0: CN4.a28; also elsewhere on the board
SDRD1: CN4.a29; also elsewhere on the board
SDRMPX: CN5.b46; also elsewhere on the board
SDROE: CN5.b47; also elsewhere on the board
SDROM: CN4.a47; also elsewhere on the board
VCC: CN4.a25, CN4.a26, CN4.a27, CN4.b25, CN4.b26, CN4.b27, CN5.a25, CN5.a26, CN5.a27, CN5.b25, CN5.b26, CN5.b27; also elsewhere on the board

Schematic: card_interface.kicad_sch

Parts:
CN6: 5535653-1; CN6
U38: 74HC32; DIP-14_W7.62mm
U80: 74HC04; DIP-14_W7.62mm

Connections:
/CARD INTERFACE/CDA0: CN6.29; also elsewhere on the board
/CARD INTERFACE/CDA1: CN6.28; also elsewhere on the board
/CARD INTERFACE/CDA2: CN6.27; also elsewhere on the board
/CARD INTERFACE/CDA3: CN6.26; also elsewhere on the board
/CARD INTERFACE/CDA4: CN6.25; also elsewhere on the board
/CARD INTERFACE/CDA5: CN6.24; also elsewhere on the board
/CARD INTERFACE/CDA6: CN6.23; also elsewhere on the board
/CARD INTERFACE/CDA7: CN6.22; also elsewhere on the board
/CARD INTERFACE/CDA8: CN6.12; also elsewhere on the board
/CARD INTERFACE/CDA9: CN6.11; also elsewhere on the board
/CARD INTERFACE/CDA10: CN6.8; also elsewhere on the board
/CARD INTERFACE/CDA11: CN6.10; also elsewhere on the board
/CARD INTERFACE/CDA12: CN6.21; also elsewhere on the board
/CARD INTERFACE/CDA13: CN6.13; also elsewhere on the board
/CARD INTERFACE/CDA14: CN6.14; also elsewhere on the board
/CARD INTERFACE/CDA15: CN6.20; also elsewhere on the board
/CARD INTERFACE/CDA16: CN6.19; also elsewhere on the board
/CARD INTERFACE/CDA17: CN6.46; also elsewhere on the board
/CARD INTERFACE/CDA18: CN6.47; also elsewhere on the board
/CARD INTERFACE/CDA19: CN6.48; also elsewhere on the board
/CARD INTERFACE/CDA20: CN6.49; also elsewhere on the board
/CARD INTERFACE/CDA21: CN6.50; also elsewhere on the board
/CARD INTERFACE/CDA22: CN6.53; also elsewhere on the board
/CARD INTERFACE/CDA23: CN6.54; also elsewhere on the board
/CARD INTERFACE/CDD0: CN6.30; also elsewhere on the board
/CARD INTERFACE/CDD1: CN6.31; also elsewhere on the board
/CARD INTERFACE/CDD2: CN6.32; also elsewhere on the board
/CARD INTERFACE/CDD3: CN6.2; also elsewhere on the board
/CARD INTERFACE/CDD4: CN6.3; also elsewhere on the board
/CARD INTERFACE/CDD5: CN6.4; also elsewhere on the board
/CARD INTERFACE/CDD6: CN6.5; also elsewhere on the board
/CARD INTERFACE/CDD7: CN6.6; also elsewhere on the board
/CARD INTERFACE/CDD8: CN6.64; also elsewhere on the board
/CARD INTERFACE/CDD9: CN6.65; also elsewhere on the board
/CARD INTERFACE/CDD10: CN6.66; also elsewhere on the board
/CARD INTERFACE/CDD11: CN6.37; also elsewhere on the board
/CARD INTERFACE/CDD12: CN6.38; also elsewhere on the board
/CARD INTERFACE/CDD13: CN6.39; also elsewhere on the board
/CARD INTERFACE/CDD14: CN6.40; also elsewhere on the board
/CARD INTERFACE/CDD15: CN6.41; also elsewhere on the board
CARDCS: CN6.7, CN6.42; also elsewhere on the board
CARDOE: CN6.9, U38.9
CARDWE: U38.5
CARDWEN: U38.1; also elsewhere on the board
CARDWENB: U80.5; also elsewhere on the board
CD1: CN6.36; also elsewhere on the board
CD2: CN6.67; also elsewhere on the board
unnamed: CN6.15, U38.6
unnamed: CN6.61, U38.8
unnamed: U38.2, U80.6
unnamed: U38.3, U38.4
REGEN: U38.10; also elsewhere on the board
VCC: CN6.17, CN6.18, CN6.51, CN6.52; also elsewhere on the board
WP: CN6.33; also elsewhere on the board

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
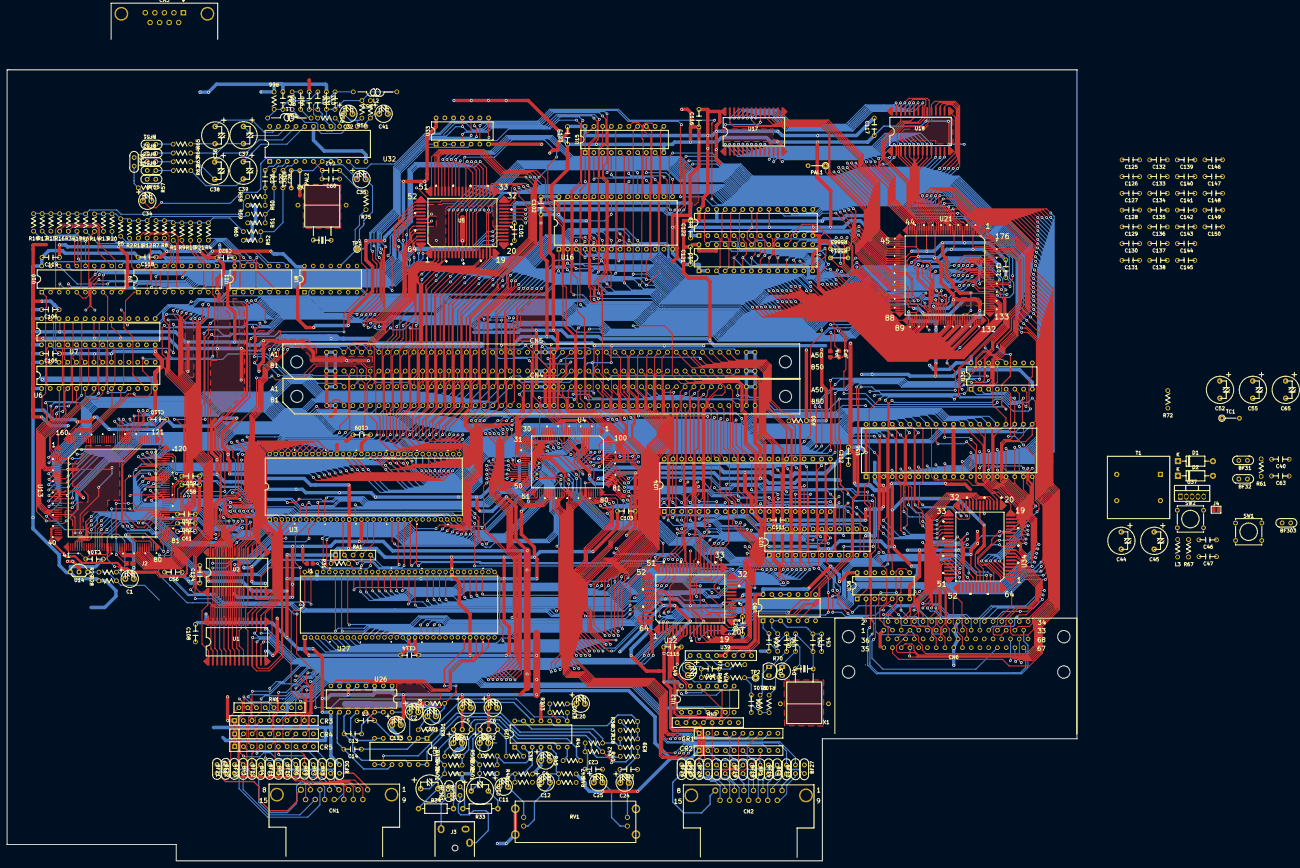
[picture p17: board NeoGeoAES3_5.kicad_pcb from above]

Board: 2 copper layers, 310.8 x 229.8 mm, 310 parts (0 on the bottom side), 608 nets.

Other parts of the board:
C40: 100uF/6.3v; CAP3-5mm
R61: 68Ω; Resistor1-5mm

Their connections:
unnamed: C40.2, R61.1

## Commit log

2022-12-03 Initial Commit of Schematics
    Initial Commit of Schematics
    [NeoGeoAES3_5.kicad_pcb, NeoGeoAES3_5.kicad_sch, card_interface.kicad_sch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]
2022-12-03 Resistor Value Ω added
    [NeoGeoAES3_5.kicad_sch, card_interface.kicad_sch, cartridge_slots.kicad_sch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]
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2022-12-03 Assigning Footprints
    Assigned some footprints to some components. Can still be wrong size on caps
    [NeoGeoAES3_5.kicad_sch, clock.kicad_sch, controller.kicad_sch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]
2022-12-03 Updated to Nightly Kicad
    Kicad Nighly Version
    [NeoGeoAES3_5.kicad_sch, card_interface.kicad_sch, cartridge_slots.kicad_sch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]
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2022-12-04 Merged in schematics from stable with footprints
    [NeoGeoAES3_5.kicad_sch, card_interface.kicad_sch, cartridge_slots.kicad_sch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]
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2022-12-05 UUID changed for somereason
    [cpu.kicad_sch, graphics.kicad_sch]
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2022-12-05 FIX 74AS04 and 74HC04
    [NeoGeoAES3_5.kicad_sch, card_interface.kicad_sch, cartridge_slots.kicad_sch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]
2022-12-05 Forgot Footprint on U8
    [NeoGeoAES3_5.kicad_sch, cartridge_slots.kicad_sch, clock.kicad_sch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]
2022-12-06 Renamed SDD[0..15] to SDD[0..7]
    [NeoGeoAES3_5.kicad_sch, cartridge_slots.kicad_sch, cpu.kicad_sch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]
2022-12-06 fixed wrong pin number on Neo-C1
    [cpu.kicad_sch, graphics.kicad_sch]
2022-12-06 Added Some Power Caps
    [NeoGeoAES3_5.kicad_sch, power.kicad_sch]
2022-12-07 U12 OUT21 and OUT23 wrong way on original schematic Added Cap on RESETP Pin20 Neo-D0
    [NeoGeoAES3_5.kicad_sch, controller.kicad_sch, graphics.kicad_sch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]
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2022-12-13 Fix 27c1024 wrong address map
    [NeoGeoAES3_5.kicad_sch, graphics.kicad_sch, power.kicad_sch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]
2022-12-14 Fix Wrong Component for Resistors on Controller Port 1 and 2. Changed to Resistor Array SIP
    [NeoGeoAES3_5.kicad_sch, controller.kicad_sch, graphics.kicad_sch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]
2022-12-15 fix wrong label name RN21 and RN22 should be RN1 and RN2
    [NeoGeoAES3_5.kicad_sch, graphics.kicad_sch, power.kicad_sch]
2022-12-15 Fix Wrong LS06 connection to CN2 on the 22X4 (RN2)
    [controller.kicad_sch, graphics.kicad_sch]
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2022-12-16 Added missing J3 and J4 for EVEN pin from LSPC2. Missing from original schematics Fixed RA1 being wrong way U38 pins 12/13 to VCC
    [NeoGeoAES3_5.kicad_sch, cpu.kicad_sch, graphics.kicad_sch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]
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2022-12-16 Added footprint to JP3 and JP4
    [NeoGeoAES3_5.kicad_sch, graphics.kicad_sch]
2022-12-16 Selected footprint that actually exists
    [NeoGeoAES3_5.kicad_sch, graphics.kicad_sch]
2022-12-17 Corrected the PC4741, The original schematics does not match the board for the audio circuit, still requires more changes as the board is laid out
    [NeoGeoAES3_5.kicad_sch, graphics.kicad_sch, power.kicad_sch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]
2022-12-17 Some Audio Changes C13 C14
    [NeoGeoAES3_5.kicad_sch, graphics.kicad_sch, ym2610_audio.kicad_sch]
2022-12-17 C14 track as slightly off
    [ym2610_audio.kicad_sch]
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2022-12-17 Component Naming Corrections
    [NeoGeoAES3_5.kicad_sch, ym2610_audio.kicad_sch]
2022-12-17 More Audio Changes to match board
    [NeoGeoAES3_5.kicad_sch, graphics.kicad_sch, ym2610_audio.kicad_sch]
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2022-12-17 Hopefully Audio Circuit matches the board
    [NeoGeoAES3_5.kicad_sch, graphics.kicad_sch, ym2610_audio.kicad_sch]
2022-12-17 More Tweaks to Audio Circuit
    [NeoGeoAES3_5.kicad_sch, graphics.kicad_sch, ym2610_audio.kicad_sch]
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2022-12-18 Sync footprints from Nightly Build
    [NeoGeoAES3_5.kicad_sch, card_interface.kicad_sch, cartridge_slots.kicad_sch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]
2022-12-19 1. Swap Halt / Reset on RA1 2. Added more Power Caps 3. Change Audio socket Left/Right around 4. Added Ferrite Beads to Audio Signals 5. Added Ferrite Beads to Video Signals
    [NeoGeoAES3_5.kicad_sch, cpu.kicad_sch, graphics.kicad_sch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]
2022-12-20 Added more power caps
    [NeoGeoAES3_5.kicad_sch, graphics.kicad_sch, power.kicad_sch]
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2022-12-20 Changed sync circuit not to use SYNCOUT pin 11 on CX Chip
    [NeoGeoAES3_5.kicad_sch, graphics.kicad_sch, rgb_video.kicad_sch]
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2022-12-25 Redo Video Clock Signal (1)
    [NeoGeoAES3_5.kicad_sch, clock.kicad_sch, graphics.kicad_sch]
2022-12-25 Redo Video Clock Signal (2)
    [NeoGeoAES3_5.kicad_sch, clock.kicad_sch]
2022-12-25 Redo Video Clock Signal (3)
    [NeoGeoAES3_5.kicad_sch, clock.kicad_sch]
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2022-12-25 Sync Footprints from Nightly
    [NeoGeoAES3_5.kicad_sch, clock.kicad_sch, cpu.kicad_sch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]
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2022-12-26 Synced PCB from Nightly to Stable
    [NeoGeoAES3_5.kicad_pcb]
2022-12-27 Fix U8 Unused pins to GND and NC Added C67 to A12 Pin 2 of U6
    [NeoGeoAES3_5.kicad_sch, graphics.kicad_sch, power.kicad_sch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]
2022-12-27 Swap X2 around
    [clock.kicad_sch, graphics.kicad_sch]
2022-12-27 Updated Value of C65
    [NeoGeoAES3_5.kicad_sch, clock.kicad_sch, graphics.kicad_sch]
2022-12-29 VCC & GND for J4
    [NeoGeoAES3_5.kicad_sch, graphics.kicad_sch, power.kicad_sch]
2022-12-29 Change Power Jack Symbol
    [NeoGeoAES3_5.kicad_sch, graphics.kicad_sch, power.kicad_sch]
2022-12-29 Power Circuit Update 1
    [NeoGeoAES3_5.kicad_sch, graphics.kicad_sch, power.kicad_sch]
2022-12-29 Update Power Circuit 2
    [NeoGeoAES3_5.kicad_sch, power.kicad_sch]
2022-12-29 Update Power Circuit 3
    [NeoGeoAES3_5.kicad_sch, power.kicad_sch]
2022-12-29 Update Power Circuit 4
    [NeoGeoAES3_5.kicad_sch, graphics.kicad_sch, power.kicad_sch]
2022-12-29 Update Power Circuit 5
    [NeoGeoAES3_5.kicad_sch, graphics.kicad_sch, power.kicad_sch]
2022-12-29 Power Circuit Update 6
    [NeoGeoAES3_5.kicad_sch, graphics.kicad_sch, power.kicad_sch]
2022-12-29 Update Power Circuit 7
    [graphics.kicad_sch, power.kicad_sch]
2022-12-29 Update Power Circuit 8
    [graphics.kicad_sch, power.kicad_sch]
2022-12-29 Update Power Circuit 9
    [NeoGeoAES3_5.kicad_sch, graphics.kicad_sch, power.kicad_sch]
2022-12-30 Update Power Circuit 10
    [NeoGeoAES3_5.kicad_sch, graphics.kicad_sch, power.kicad_sch]
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2022-12-30 Merged Footprints from Nightly
    [NeoGeoAES3_5.kicad_sch, clock.kicad_sch, graphics.kicad_sch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]
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2023-01-02 Swap Audio Resistors
    [graphics.kicad_sch, ym2610_audio.kicad_sch]
2023-01-02 Swapped Audio Resistors Around
    [graphics.kicad_sch, ym2610_audio.kicad_sch]
2023-01-02 Put Resistor Back, Swap Headphone
    [graphics.kicad_sch, ym2610_audio.kicad_sch]
2023-01-02 Fixed main unconnected traces Left to do is SW2 and all VCC and GND Still Todo Footprints for Power components bottom Left
2023-01-02 Updated Footprints Match PCB
    [NeoGeoAES3_5.kicad_sch, power.kicad_sch, rgb_video.kicad_sch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]
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2023-01-02 Swap Barrel Jack Symbol Change Size of Resistor
    [NeoGeoAES3_5.kicad_sch, graphics.kicad_sch, power.kicad_sch]
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2023-01-02 Some Ground Planes Added Added Missing Resistor and LED
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2023-04-04 Upgrade Schematics to Kicad 7.0
    [NeoGeoAES3_5.kicad_sch, card_interface.kicad_sch, cartridge_slots.kicad_sch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]
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2023-04-04 Changed Power input on DC Jack to be +9v instead of VCC Zero errors on PCB
    [graphics.kicad_sch, power.kicad_sch]
2023-04-05 Updated footprints from PCB to Schematics
    [power.kicad_sch, ym2610_audio.kicad_sch]
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2023-04-05 Added extra power cap
    [graphics.kicad_sch, power.kicad_sch]
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2023-04-05 PCB Updates Removed some none connected tracks Ignored Warnings on other none connected tracks Ignored Warnings on none designated footprints Fix a P6 Track that should have been GND
2023-04-06 PCB uopdates
    Added GND mounting holes x 3 and U37 exposed copper. Fixed fiducial at top right.
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2023-08-27 Updates to PCB Move P2 Joystick Port Move Memory Card Move Holes at top right Silkscreen added Update Titles
    [NeoGeoAES3_5-BOM.csv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]
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2023-08-28 Schematic fixes to PCB for D1 and D2
    [graphics.kicad_sch, power.kicad_sch]
2023-09-16 Track improvements for vcc at the cart slot
    [NeoGeoAES3_5-B_Cu.gbl, NeoGeoAES3_5-B_Mask.gbs, NeoGeoAES3_5-B_Paste.gbp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]
2023-09-16 More silkscreen tidy up, adding mouser components to BOM
    [card_interface.kicad_sch, cartridge_slots.kicad_sch, clock.kicad_sch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]
2023-09-24 Little tweaks to silkscreen Updated BOM with mouser parts
    [NeoGeoAES3_5-B_Cu.gbl, NeoGeoAES3_5-B_Mask.gbs, NeoGeoAES3_5-B_Paste.gbp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]
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2023-12-24 Update README.md
    fix pdf bom
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2024-01-06 Update BF1.4
    Update Mouser Parts
    Update Silkscreen for Memory Slot
    Update Silkscreen for BF1.4 Version and date
    Generate Gerbers and BOM files
    [NeoGeoAES3_5-BOM.csv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]
2024-01-06 Update Silk
    Update Ram Silk
    Fix mouser wrong 6.8K
    Update BOM, Gerbers ...
    [NeoGeoAES3_5-BOM.csv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]
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2024-01-11 fix wrong mouser part for 6.8K Resistor
    [NeoGeoAES3_5-BOM.csv, graphics.kicad_sch, rgb_video.kicad_sch]
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
